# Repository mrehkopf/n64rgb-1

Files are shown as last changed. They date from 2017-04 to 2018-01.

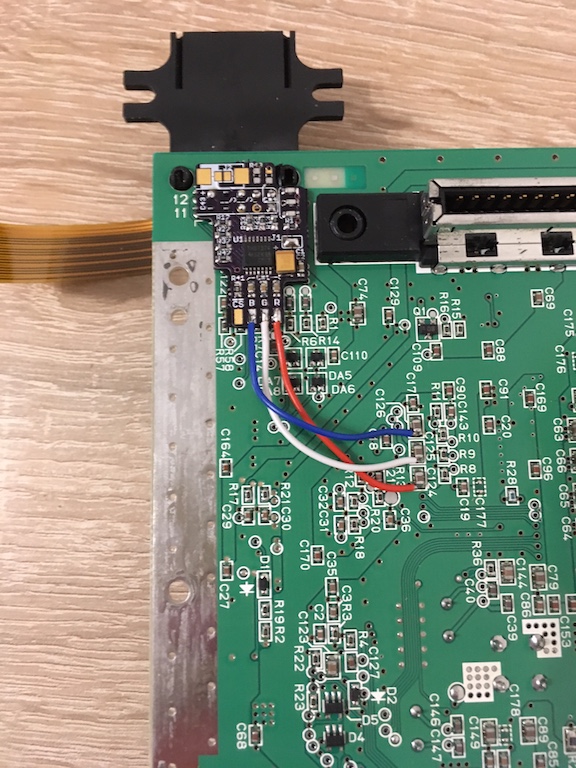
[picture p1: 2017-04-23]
pictures/n64_RGBamp_installed.jpg

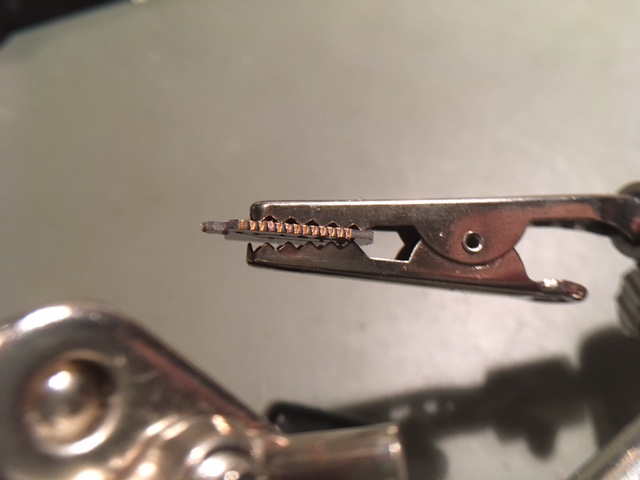
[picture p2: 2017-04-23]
pictures/mav_nus_breakout_side.jpg

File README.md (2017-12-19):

# N64 RGB 

A collection of RGB mods for the N64. This repository includes:

- a simple RGB amp
  * based on TI's video amplifier THS7374 / THS7373 (only for some NTSC-units)
  * folder: simpleRGBAmp
- a general RGB digital-to-analog converter based on viletims schematics
  * supported devices: MaxII (EPM240T100C5, EPM570T100C5) and MaxV (5M240ZT100C4, 5M570ZT100C4) CPLDs
  * PCB files (common for all supported devices) and firmware (separate programming files) are provided
  * folder: generalRGBmod
- an advanced RGB digital-to-analog converter with optional YPbPr conversion
  * supported FPGA: Cyclone IV (EP4CE6E22 and EP4CE10E22) and Cyclone 10 LP (10CL006YE144 and 10CL010YE144)
  * PCB files (common for all supported devices) and firmware (separate programming files) are provided
  * additional Filter board for the outputted video signal if you need that
  * folder: advancedRGBmod
- additional MAV-NUS Adapter:
  * pin breakout from 0.8mm pitch to 1.27mm pitch
  * PCB files provided
  * folder: misc/MAV-NUS-BreakOut
- Filter AddOn for N64RGBv2 and N64 Advanced:
  * used to filter the video signal comming out of the ADV7125 or to adjust signal levels such that one can use SNES PAL RGB cables
  * PCB files provided
  * folder: misc/FilterAddOn
- an alternative firmware for viletims commercial N64 RGB modding kit
  * include in firmware folder of generalRGBmod
  * project: n64rgb_viletim.qpf

## Acknowledgement

Of course, many thanks to viletim for his initial CPLD-based DAC project, for providing a valuable commercial modding board as well as for publishing the schematics and source codes for that project.
I also want to send many thanks to Ikari_01. He has written the code to detect 480i and PAL/NTSC output with the CPLD. He provides a source code for the XC9572XL, which can be accessed here: [URL to Ikari_01's GitHub repository](https://github.com/mrehkopf/n64rgb)
Last but not least, thank you to Bob for his website [RetroRGB](http://retrorgb.com) and especially in this context here for collecting and sharing all the [RGB information regarding the N64](http://retrorgb.com/n64.html).

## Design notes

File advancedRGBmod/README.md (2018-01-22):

# Advanced N64 RGB Digital-to-Analog Mod

This folder contains all you need for a complete DIY RGB mod.

Please don't ask me for selling a modding. I either sell some prototypes on some forums marketplaces (which is very unlikely) or I don't have any of the boards.
This is a complete DIY modding project. So everybody is on his own here.

**WARNING:** This is an advanced DIY project if you do everything on your own. You need decent soldering skills. The FPGA has 0.5mm fine pitch with 144pins and one exposed pad below the IC, which has to be soldered to the PCB. Next to it the video DAC has also 0.5mm pin pitch on the board there are some SMD1206 resistor and ferrit bead arrays.

## Features

- Supporting for different FPGAs [1] on a common PCB design:
  * (Cyclone IV EP4CE6E22)
  * Cyclone IV EP4CE10E22
  * (Cyclone 10 LP 10CL006YE144)
  * Cyclone 10 LP 10CL010YE144
- Video DAC ADV7125 (or ADV7123)
- Detection of 240p/288p vs. 480i/576i together with detection of NTSC vs. PAL mode
- Heuristic for de-blur function [2], De-Blur in 240p/288p (horizontal resolution decreased from 640 to 320 pixels)
- 15bit color mode
- IGR features:
  * reset the console with the controller
  * full control on de-blur and 15bit mode with the controller
- Advanced features:
  * output of RGsB or YPBPr on demand
  * linedoubling of 240p/288p video to 480p/576p [3]
  * selectable scanline strength: 0% (i.e. sl off), 25%, 50% and 100% [4]
  * optional bob de-interlace of 480i/576i to 480p/576p [3]
  * VGA output [5]

The following shortly describes the main features of the firmware and how to use / control them.

#### Notes
##### [1]
For now, all FPGAs seems to be fine. However, it might be the case that the 6k LEs FPGAs (EP4CE6E22 and 10CL006YE144) are to small for an OSD menu implementation due to the small amount of block RAM.

##### [2]
Heuristic for de-blur function highly depends on the image content. So it might be the case that de-blur is switched on and off rapidly even on small content changes. In any case you can override the heuristic by forcing de-blur on or off.  
If you observe something like that or where do you think that de-blur is not correctly guessed, please take a note (PAL / NTSC N64, game, ROM, situation), where I can check that and can try to further improve the heuristic algorithm. Send me your observation vie email or open an issue here on GitHub.

##### [3]
can be switched off

##### [4]
no scanlines are available in this mode

##### [5]
Not available if the filter adddon is used as HSYNC and VSYNC are shared outputs with F1 and F2 (filter selection)

### In-Game Routines (IGR)

Three functunalities are implemented: toggle de-blur feature / override heuristic for de-blur and toggle the 15bit mode (see above) as well as resetting the console.

The button combination are as follows:

- reset the console: Z + Start + R + A + B
- (de)activate de-blur / override heuristic for de-blur: (see description above)
- (de)activate 15bit mode: (see description above)

_Modifiying the IGR Button Combinations_:  
It's difficult to make everybody happy with it. Third party controllers, which differ from the original ones by design, make it even more difficult. So it is possible to generate your own firmware with **your own** preferred **button combinations** implemented. Please refere to the document **IGR.README.md** located in the top folder of this repository for further information.

_Final remark on IGR_:  
However, as the communication between N64 and the controller goes over a single wire, sniffing the input is not an easy task (and probably my solution is not the best one). This together with the lack of an exhaustive testing (many many games out there as well my limited time), I'm looking forward to any incomming issue report to furhter improve this feature :)

### De-Blur

De-blur of the picture information is only be done in 240p/288p. This is be done by simply blanking every second pixel. Normally, the blanked pixels are used to introduce blur by the N64 in 240p/288p mode. However, some games like Mario Tennis, 007 Goldeneye, and some others use these pixel for additional information rather than for bluring effects. In other words this means that these games uses full horizontal resolution even in 240p/288p output mode. Hence, the picture looks more blurry in this case if de-blur feature is activated.

- **By default heuristic is activated on every power cycle and on every reset!** However, as the heuristic guess might be not reliable, the guess can be overriden.
- Press Z + Start + R + C-le to deactivate de-blur (overrides the guess)
- Press Z + Start + R + C-ri to activate de-blur (overrides the guess)

_(Button combinations can be modified according to your needs - see note below @ **In-Game Routines (IGR)**)_

### Heuristic for De-Blur

As noted above, the N64 typically outputs a 320pixel wide picture in 240p/288p. As the pixel clock does not change compared to 480i/576i there outputted pixel wide is 640.
On the one hand, most games outputs a 320pixel wide picture in 240p/288p and use the remaining pixels to introduce a blur. This can be removed by simply blank these interpolated pixels.
On the other hand, a minor number of games outputs a 'full' 640pixel wide picture also in 240p/288p. In this case blanking out the suspected interpolated pixels causes a blurry picture.

The heuristic algorithm estimates whether a game uses the first or the second method. Depending on the result de-blur is active or not. However, as the estimation could be wrong, the user has the opportunity to override the estimation. (see section de-blur) At the moment it is not implemented that the heuristic can be switched on once overridden except with a reset or a new power cycle.

### 15bit Color Mode

The 15bit color mode reduces the color depth from 21bit (7bit for each color) downto 15bits (5bit for each color). Some very few games just use the five MSBs of the color information and the two LSBs for some kind of gamma dither. The 15bit color mode simply sets the two LSBs to '0'.

- By default the 15bit mode is *off*! The default is set on each power cycle but not on a reset.
- to deactivate 15bit mode press Z + Start + R + C-up.
- to (re)activate 15bit mode press Z + Start + R + C-dw.

_(Button combinations can be modified according to your needs - see note below @ **In-Game Routines (IGR)**)_

### Low Pass Filtering of the Video Output

The video DAC does not use any filtering. In general, this is also not needed. If you need DAC post-filtering though (receiver has a ADC build without any pre-filtering), you can install the filter addon (also provided in this repository).

The filter addon is based on a THS7368, where the video channels with selectable filter are used. As the filter is selected over the same pins as HSYNC and VSYNC, the addon is not compatible to VGA.

## Technical Information

A complete installation and setup guide to this modding kit is provided in the main folder of the repository. Here are some additional short notes.

### Checklist: How to build the project

- Use PCB files to order your own PCB or simply use the shared project(s) on OSHPark
- Source the components you need, e.g. from Mouser or Digikey
- Wait for everything to arrive
- Assemble your PCB
- Set all jumpers
- Flash the firmware to the serial flash device
  * You need a Altera USB Blaster
  * Use the JIC programming file if you want to program the serial flash over the FPGA or the SOF file if you have a AS programming adapter for the serial flash
  * The serial flash / board needs to be powered; so you may consider to install the PCB into your N64 first and then use the N64 for powering the board
  * If you want to build an adapter, you may take a look onto [my DIY adapter](https://oshpark.com/shared_projects/mEwjoesz) at [my profile on OSHPark](https://oshpark.com/profiles/borti4938)
- Install the modding board:
  * Installation description is part of the guide located in the top folder.
  * However an installation guide of a simalar product made by viletim is provided [here](http://etim.net.au/n64rgb/). The minor differences / extra pads are as follows:
    * decide on you own whether you want to use the analog part with 5V (connect 5V to the appropriate pad) or with 3.3V (short jumper _J6_). **Don't connect 5V and close J5.**
	* Pad *C*: currently unused. Leave it unconnected
    * Pad *Rst#*: connect this pad to the PIF-NUS pin 27
    * Pad *Ctrl*: connect this pin to the middle pin of the controller port you want to use for the IGR functions (controller port 1 is probably connected to PIF-NUS pin 16; check that before soldering a wire)
  * You have to be aware of the pinout of your video-encoder build into your N64. Pads on the DIY modding board are labeled.
  * If you have a MAV-NUS in your N64, you may want to use either the DIY break out board provided with this project and on OSHPark or buy a [flex cable from viletims shop](http://etim.net.au/shop/shop.php?crn=209&rn=555&action=show_detail)

### Jumpers

There are some jumpers spreaded over the PCB, namely _J1_, _J2_, _J3_, _J4_, _J5_ and _J6_. _J1 - J4_ have to parts, let's say _.1_ and _.2_, where _.1_ is marked with the _dot_ on the PCB.

#### J1 (Filter AddOn)
##### J1.1 
- opened: output HSYNC and VSYNC for possible VGA output
- closed: use filter addon

##### J1.2
- opened: use filter of the addon board
- closed: bypass filter (actually filter is set to 95MHz cut-off which is way above the video signal content)

#### J2 (RGB, RGsB, YPbPr)
##### J2.1
- opened: RGB output
- closed: RGsB output (sync on green)

##### J2.2
- opened: RGB / RGsB output
- closed: YPbPr output (beats J2.1)

#### J3 (Scanline)
##### J3.1/J3.2
- opened / opened: 0%
- opened / closed: 25%
- closed / opened: 50%
- closed / closed: 100%

#### J4 (Linemode)
##### J4.1
- opened: linedoubling of 240p/288p to 480p/576p
- closed: no-linedoubling (beats J4.2)

##### J4.2
- opened: no bob de-interlace of 480i/576i
- closed: bob de-interlace of 480i/576i to 480p/576p (J4.1 must be opened)

#### J5
_J5_ is the JTAG connector.

#### J6 (Power supply of analog outputs)
The analog part can be power with **either** 3.3V **or** 5V. If you want to power this part of the PCB with 3.3V, close _J6_ and leave pad _5V_ unconnected. If you want to power this part with 5V, leave _J6_ opened and connect pad _5V_ to +5V power rail of the N64. **NEVER connect 5V and close J6.**

#### Fallback Mode

A fallback mode can be activated by holding reset button down while powering on the N64. In the fallback mode **linedoubling and component conversion is turned off**. Sync on G/Y output is still on if one J2.1 or J2.2 is set as it does not affect RGBS.

### Source the PCB

Choose the PCB service which suits you. Here are some:

- OSHPark: [Link to the Main PCB](https://oshpark.com/shared_projects/kKAiNrtK) (If the PCB was updated and I forgot to update this link, look onto [my profile](https://oshpark.com/profiles/borti4938))
- PCBWay.com: [Link](http://www.pcbway.com/), [Affiliate Link](http://www.pcbway.com/setinvite.aspx?inviteid=10658)

### Part List for the PCB

This part list a recommendation how the PCB is designed. If you are able to find pin-compatible devices / parts, you can use them.

#### Components

Components are listed in advancedRGBmod/Main-PCB/BOM_n64advanced.xlsx

### Firmware
The firmware is located in the folder firmware/. To build the firmware on your own you need Quartus Prime Lite (any version which supports MaxII and MaxV devices).

If you only want to flash the firmware, the configuration files are pre-compiled and located in firmware/output_files. You need the POF appropriate for the CPLD you have choosen (look for the *\_extension*).

For flashing you need:

- Altera USB Blaster
- Standalone Quartus Prime Programmer and Tools

#### Firmware Revision Numbering

- 1.0: initially commited version

#### Road Map / New Ideas

- Gamma boost
- On Screen Display menu to get rid of the jumpers
- improve de-blur heuristic, e.g. by
  * de-blur estimation in the Y-domain
  * dynamic de-blur: decide on demand wether a pixel is used for a blurry effect or not (possible for the N64 to decide on demand? (e.g. background gaming with blur, front text without blur))
  * don't use quite dark / light pictures for the de-blur heuristic algorithm
- HDMI

Any other ideas: email me :)

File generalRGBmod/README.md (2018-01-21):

# General N64 RGB Digital-to-Analog Mod

This folder contains all you need for a complete DIY RGB mod.

Please don't ask me for selling a modding. I either sell some prototypes on some forums marketplaces (which is very unlikely) or I don't have any of the boards.
This is a complete DIY modding project. So everybody is on his own here.
If you are looking for a ready to install kit, just look on your own for a seller. Preferably you should invest your money into a [kit made by viletim](http://etim.net.au/shop/shop.php?crn=209). I also provide similar firmware files for his board in this GitHub repository, too.

**WARNING:** This is an advanced DIY project if you do everything on your own. You need decent soldering skills. The CPLD has 0.5mm fine pitch with 100pins. Next to it the video amp has a 0.65mm pin pitch on the board there are some SMD1206 resistor and ferrit bead arrays.

## Features

- Supporting for different CPLDs on a common PCB design:
  * MaxII EPM240T100C5
  * MaxII EPM570T100C5
  * MaxV 5M240ZT100C4 (a 5M240ZT100C5 does not met timing requirements [1])
  * MaxV 5M570ZT100C4 (a 5M570ZT100C5 does not met timing requirements [1])
- Video DAC:
  * V1: R2R ladder with video amplifier THS7374 or THS7373
  * V2: Video DAC ADV7125
- Detection of 240p/288p vs. 480i/576i together with detection of NTSC vs. PAL mode
- Heuristic for de-blur function [2], De-Blur in 240p/288p (horizontal resolution decreased from 640 to 320 pixels)
- 15bit color mode
- IGR features:
  * reset the console with the controller
  * full control on de-blur and 15bit mode with the controller
- Installation type: user decides whether he want to use IGR features or dedicated mechanical switches
- Slow Slew Rate
- for possibly future implementation: switch LPF of the video amplifier on and off (may only fit into CPLDs with 570LE)

The following shortly describes the main features of the firmware and how to use / control them.

#### Notes
##### [1]
Clocks are defined in the SDC-files place in the firmware folder.
The 5M240ZT100C5 and 5M570ZT100C5 does not met the timing requirements checked during the Timing Analysis. However, the default model is the so called *slow model*. If one uses the *fast model* for analysis, the timings are met without any problems.
So one could also give a try with the 5M240ZT100C5 or the 5M570ZT100C5, which should also works with 95% of all units produced in 'common' environments (e.g. living room temperature environment). Nevertheless, I won't garantee that.

Update: If you are looking for a 5M240ZT100C4 and 5M570ZT100C4, you propably realize that they are not in stock (e.g. at Mouser or Digikey). Then you can also use the 5M240ZT100I5 and 5M570ZT100I5, which are actually the same CPLDs.

##### [2]
Heuristic for de-blur function highly depends on the image content. So it might be the case that de-blur is switched on and off rapidly even on small content changes. In any case you can override the heuristic by forcing de-blur on or off.  
If you observe something like that or where do you think that de-blur is not correctly guessed, please take a note (PAL / NTSC N64, game, ROM, situation), where I can check that and can try to further improve the heuristic algorithm. Send me your observation vie email or open an issue here on GitHub.

### In-Game Routines (IGR) (default installation type)

Three functunalities are implemented: toggle de-blur feature / override heuristic for de-blur and toggle the 15bit mode (see above) as well as resetting the console.

The button combination are as follows:

- reset the console: Z + Start + R + A + B
- (de)activate de-blur / override heuristic for de-blur: (see description below)
- (de)activate 15bit mode: (see description below)

_Modifiying the IGR Button Combinations_:  
It's difficult to make everybody happy with it. Third party controllers, which differ from the original ones by design, make it even more difficult. So it is possible to generate your own firmware with **your own** preferred **button combinations** implemented. Please refere to the document **IGR.README.md** located in the top folder of this repository for further information.

_Final remark on IGR_:  
However, as the communication between N64 and the controller goes over a single wire, sniffing the input is not an easy task (and probably my solution is not the best one). This together with the lack of an exhaustive testing (many many games out there as well my limited time), I'm looking forward to any incomming issue report to furhter improve this feature :)

### De-Blur

De-blur of the picture information is only be done in 240p/288p. This is be done by simply blanking every second pixel. Normally, the blanked pixels are used to introduce blur by the N64 in 240p/288p mode. However, some games like Mario Tennis, 007 Goldeneye, and some others use these pixel for additional information rather than for bluring effects. In other words this means that these games uses full horizontal resolution even in 240p/288p output mode. Hence, the picture looks more blurry in this case if de-blur feature is activated.

- **By default heuristic is activated on every power cycle and on every reset!** However, as the heuristic guess might be not reliable, the guess can be override. Also, the heuristic algorithm can be switched off permanently by setting pin 2 of the CPLD to GND (short pin 1 and 2)
- Press Z + Start + R + C-le to deactivate de-blur (overrides the guess)
- Press Z + Start + R + C-ri to activate de-blur (overrides the guess)
- If heuristic estimation is switched off, the de-blur setting has a default value. This default is set on each power cycle but not on a reset. Default is de-blur *on*! If you want to have it *off* by default, short pin 91 and 90 at the CPLD!

_(Button combinations can be modified according to your needs - see note below @ **In-Game Routines (IGR)**)_

### Heuristic for De-Blur

As noted above, the N64 typically outputs a 320pixel wide picture in 240p/288p. As the pixel clock does not change compared to 480i/576i there outputted pixel wide is 640.
On the one hand, most games outputs a 320pixel wide picture in 240p/288p and use the remaining pixels to introduce a blur. This can be removed by simply blank these interpolated pixels.
On the other hand, a minor number of games outputs a 'full' 640pixel wide picture also in 240p/288p. In this case blanking out the suspected interpolated pixels causes a blurry picture.

The heuristic algorithm estimates whether a game uses the first or the second method. Depending on the result de-blur is active or not. However, as the estimation could be wrong, the user has the opportunity to override the estimation. (see section de-blur) At the moment it is not implemented that the heuristic can be switched on once overridden except with a reset or a new power cycle.

### 15bit Color Mode

The 15bit color mode reduces the color depth from 21bit (7bit for each color) downto 15bits (5bit for each color). Some very few games just use the five MSBs of the color information and the two LSBs for some kind of gamma dither. The 15bit color mode simply sets the two LSBs to '0'.

- By default the 15bit mode is *off*! The default is set on each power cycle but not on a reset. If you want to have it *on* by default, short pin 36 and 37 at the CPLD!
- to deactivate 15bit mode press Z + Start + R + C-up.
- to (re)activate 15bit mode press Z + Start + R + C-dw.

_(Button combinations can be modified according to your needs - see note below @ **In-Game Routines (IGR)**)_

### Jumpers - Altering Defaults and Installation Type

There are three jumpers jumpers on the modding board - one double solder jumper and one 'hidden' jumper - to set up deblur (IGR installation) and 15bit mode.  
The hidden jumper are nothing else then neighbouring pins. This pin is marked with an arrow. If you short a pair of pins you can change the default of the above noted features.  

- J11.1 -> deactivates de-blur by default (only applied if de-blur heuristic is off by default) **[1]**
- J11.2 -> deactivate the de-blur heuristic. **[1]**
- pin 36 and 37 (hidden jumper on v1) / J12.1 -> activates the 15bit color mode by default
- J12 (v1) / J12.2 (v2) -> Altering installation type **[2]** 

**Notes**:  

**[1]**  
Board Version September 2017 and later have a dedicated double solder jumper for de-blur heuristic and de-blur default. The jumper is labeled with _J11_ (left pad is _marked with a dot_). The middle pad is GND, the right pad is de-blur heuristic on (open) or off (short to middle) and the left pad is de-blur on (open) or off (short to middle), respectively.  
On older revisions _J11.1_ (pin 90 and 91) and _J11.2_ (pin 1 and 2) are hidden jumpers.  

**[2]**  
To use switches for de-blur (similar to viletims board) on can set the jumper _J12_ on the board. This deactivates the IGR functionalities and the user can use the in-/ouputs for controller and reset for switches.  
These switches are used as on viletims commercial board: **A**uto and **M**anual. The corresponding inputs are _Ctrl_ and _Rst#_, respectively. On newer boards (September 2017 and later) these pads are relabeled with _Ctrl/ A_ and _Rst#/ M_.

- If pad _Ctrl/ A_ is shorted to GND via a switch, the de-blur heuristic is used to switch de-blur on and off.
- If pad _Rst#/ M_ is shorted to GND via a switch, the de-blur is forced to be on (beats heuristic).

_J12_ is connected to pin 66 of the CPLD. Next to it is pin 65 which is connected to GND. If you have an older version of the board (August 2017 and earlier) running with the current firmware (September 2017 and later) you can short pin 65 and 66 to activate the alternative installation type.

### Slow Slew Rate

This feature reduces the rising and falling time of the outputs. This reduces artefacts due to fast rising/falling edges at the outputs and the resulting over-/undershoots. The drawback is that the edges are not as sharp as with fast slew rates (at least in theory), which is not noticeable.

### Low Pass Filter Bypass Mode of the THS7374 (v1 only)

The bypass mode of the internal filters is controlled by the CPLD. At the moment the CPLD forwards just the setting one can input to the CPLD over pad *Fil*.

- To leave the internal filters enabled you can left the pad open
- To bypass the filter set this pad to GND.

## Technical Information

A complete installation and setup guide to this modding kit is provided in the main folder of the repository. Here are some additional short notes.

### Checklist: How to build the project

- Use PCB files to order your own PCB or simply use the shared project on OSHPark
- Source the components you need, e.g. from Mouser
- Wait for everything to arrive
- Assemble your PCB (**N64RGBv1**):
  * If you use a MaxII CPLD, you have to assemble FB2 and must not use U3, C31 and C32.
  * If you use a MaxV CPLD, you need U3 (a 1.8V voltage regulator), C31 and C32. Don't touch FB2 in this case!
- Assemble your PCB (**N64RGBv2**):
  * If you use a MaxII CPLD, you have to assemble FB3 and must not use U4, C41 and C42.
  * If you use a MaxV CPLD, you need U4 (a 1.8V voltage regulator), C41 and C42. Don't touch FB3 in this case!
- If you use a 570LEs CPLD, close J1
- Flash the firmware to the CPLD:
  * You need a Altera USB Blaster
  * The board needs to be powered; so you may consider to install the PCB into your N64 first and then use the N64 for powering the board
  * If you want to build an adapter, you may take a look onto [my DIY adapter](https://oshpark.com/shared_projects/mEwjoesz) at [my profile on OSHPark](https://oshpark.com/profiles/borti4938)
- Install the modding board:
  * Installation description is part of the guide located in the top folder.
  * However an installation guide of a similar product made by viletim is provided [here](http://etim.net.au/n64rgb/). The minor differences / extra pads are as follows:
    * N64RGBv2: J2 shorts 3.3V from CPLD with power rail of the ADV7125 (DAC). **If you use 5V at the analog power rail of the ADV7125, you must not close J2!**
    * Pad *Fil*: controls the low pass filter mode (v1 only, see above)
    * Pad *Rst#*: connect this pad to the PIF-NUS pin 27
    * Pad *Ctrl*: connect this pin to the middle pin of the controller port you want to use for the IGR functions (controller port 1 is probably connected to PIF-NUS pin 16; check that before soldering a wire)
  * You have to be aware of the pinout of your video-encoder build into your N64. Pads on the DIY modding board are labeled.
  * If you have a MAV-NUS in your N64, you may want to use either the DIY break out board provided with this project and on OSHPark or buy a [flex cable from viletims shop](http://etim.net.au/shop/shop.php?crn=209&rn=555&action=show_detail)

### Source the PCB
Choose the PCB service which suits you. Here are some:

- OSHPark: [Link to the Main PCB v1](https://oshpark.com/shared_projects/zPCxky4e) (If the PCB was updated and I forgot to update this link, look onto [my profile](https://oshpark.com/profiles/borti4938))
- OSHPark: [Link to the Main PCB v2](https://oshpark.com/shared_projects/KUxvVUbc) (If the PCB was updated and I forgot to update this link, look onto [my profile](https://oshpark.com/profiles/borti4938))
- PCBWay.com: [Link](http://www.pcbway.com/), [Affiliate Link](http://www.pcbway.com/setinvite.aspx?inviteid=10658)

### BOM / Part List for the PCB
This part list a recommendation how the PCB is designed. If you are able to find pin-compatible devices / parts, you can use them.

The manufacturer's part numbers (MPNs) are just to help you to source appropriate components.

### Firmware
The firmware is located in the folder firmware/. To build the firmware on your own you need Quartus Prime Lite (any version which supports MaxII and MaxV devices).

If you only want to flash the firmware, the configuration files are pre-compiled and located in firmware/output_files. You need the POF appropriate for the CPLD you have choosen (look for the *\_extension*).

For flashing you need:

- Altera USB Blaster
- Standalone Quartus Prime Programmer and Tools

#### Firmware Revision Numbering

Revision numbering goes along with the revision numbering I use for the alternative firmware for viletims N64RGB modding kit.

#### Road Map / New Ideas

- don't use quite dark / light pictures for the de-blur heuristic algorithm (possibly only for the CPLDs with 570LEs)
- Simple onscreen feedback for user controled changes (only for the CPLDs with 570LEs (for the 240LEs CPLDs instead of the heuristic?))
- dynamic de-blur: decide on demand wether a pixel is used for a blurry effect or not (possible for the N64 to decide on demand? (e.g. background gaming with blur, front text without blur))
- HDMI?

Any other ideas: email me :)

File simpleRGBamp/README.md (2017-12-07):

# Simple RGB Mod

## General Information

Technical information about this mod...

- Which N64 is suitable for it
- How to install this mod

... can be found on RetroRGB.com ([Compatibility](http://www.retrorgb.com/n64rgbcompatible.html) and [Installation](http://www.retrorgb.com/n64rgbmod.html))

Many thanks to Bob at this place for sharing that.

The rest

- Which parts are needed
- Some additional tips and hints

can be found in this document.

## Components

**be aware of the additional comments below this table**

| Label | Device / Part | Package | Quantity | Mouser Ordering Key | Comment |
|:---:|---|---|:---:|:---|---|
| | | | | | |
| **U1** | THS7374 | TSSOP-14 | 1 | 595-THS7374IPWR | |
| | THS7373 | TSSOP-14 | 1 | 595-THS7373IPWR | **Alternative** for the THS7374 [1] |
| **C1** | 22uF / 6.3V (tantal) | SMD case B (typical: 3.50mm x 2.80mm) | 1 | 74-593D226X96R3B2TE3 | |
| **C2** | 0.1uF / 50V (10%) | SMD 0603 | 1 | 80-C0603C104K9R | |  
| | | | | | |
| **R1, R41** | 4.7kohm (1%) | SMD 0603 | 2 | 71-CRCW06034K70FKEAH | |
| **R42** | 475ohm (1%) | SMD 0603 | 1 | 71-CRCW0603-475-E3 | csync compatible with 75ohm termination [2,3] |
| | 10.7kohm | SMD 0603 | 1 | 71-CRCW060310K7FKEB | TTL compatible csync [2,3] |
| **C11,C21,C31** | 0.082uF / 25V (10%) | SMD 0603 | 3 | 81-GRM188R71E823KA1D | |
| **R12,R22,R32** | 5.1Mohm (1%) | SMD 0603 | 3 | 71-CRCW06035M10FKEA | |
| | | | | | |
| **R13,R23,R33** | 75ohm (1%) | SMD 0603 | 3 | 71-RCS060375R0FKEA | NTSC-SNES RGB cable setup or direct wiring on RGB wires [4] |
| | 39ohm (1%) | SMD 0603 | 3 | 71-CRCW060339R0FKEAH | PAL-SNES cable setup on RGB wires [4] |
| **C14,C24,C34** | 47pF / 25V (5%) | SMD 0603 | 3 | 77-VJ0603A470JXXPBC | | 
| | | | | | |
| **C43** | tantal 220uF / 6.3V (tantal) | SMD case D (typical: 7.30mm x 4.30mm) | 1 | 74-593D227X96R3D2TE3 | csync compatible with 75ohm termination[2,3] |
| | 330uF / 6.3V (tantal) | SMD case D (typical: 7.30mm x 4.30mm) | 1 | 74-TR3D337K6R3E0100 | /CSYNC compatible with 75ohm termination, **Alternative** to 220uF tantal [2,3] |
| | *free* | | | | TTL compatible /CSYNC, close **J2** [2,3] |
| **R43** | 75ohm (1%) | SMD 0603 | 1 | 71-RCS060375R0FKEA | csync compatible with 75ohm termination [2,3], NTSC-SNES RGB cable setup [4] |
|| 39ohm (1%) | SMD 0603 | 1 | 71-CRCW060339R0FKEAH | /CSYNC compatible with 75ohm termination [2,3], PAL-SNES cable setup on RGB wires [4] |
| | 0ohm | SMD 0603 | 1 | *use a piece of silver wire* |  TTL compatible /CSYNC [2,3] |
| **C44** | 47pF / 25V (5%) | SMD 0603 | 1 | 77-VJ0603A470JXXPBC | [3] | 

### Additional Comments:

##### [1]  
Both ICs are supported. The THS7373 has one SD-video low pass filter (used for /CSYNC) and three HD-video filters (used for R, G and B). The THS7374 has four SD-video filters.  
At the THS7373 the HD-video LPFs can be bypassed and at the THS7374 all four SD-video filters can be bypassed (using J1).

##### [2]
According to your needs, you can design the board such that it outputs 75ohm compatible /CSYNC or TTL /CSYNC. Be aware of the components marked with this note (**R42**, **R43**, **C43/J2** and **C44**).  
If you have a RGB cable build to work with /CSYNC and use this with another (probably) _unmodified_ console, which you use on a 75ohm terminated source, you may have a resistor (and a cap) build in the sync line. Then you must build this modding board here with TTL compatible sync, too.

##### [3]
If you are going to use the stock /CSYNC circuit of the N64 - which I recommend if you have a NUS-CPU-01/02/03 board - you don't need the components **R43**, **C43** and **C44**. Just leave the footprints disassembled.  
**R42** should remain on the modding board (either size; could also be a short) as it holds channel one of the video amp close to GND.

##### [4]
As the N64 does not output RGB by stock, there is no official RGB cable available. A most common method is to refere to the [SNES cable schematics](http://members.optusnet.com.au/eviltim/gamescart/gamescart.htm#snes).

- If you use a NTSC cable cable, **R13**, **R23** and **R33** (and **R43**) has to be 75ohm resistors.
- If you use a PAL cable setup, **R13**, **R23** and **R33** (and **R43**) has to be 39ohm resistors.

## Source the PCB
Choose the PCB service which suits you. Here are some:

- OSHPark: [Link to the PCB](https://oshpark.com/shared_projects/B3Unx78x) (If the PCB was updated and I forgot to update this link, look onto [my profile](https://oshpark.com/profiles/borti4938))
- PCBWay.com: [Link](http://www.pcbway.com/), [Affiliate Link](http://www.pcbway.com/setinvite.aspx?inviteid=10658)

## Installation

A very good installation guide can be found on [RetroRGB.com](http://www.retrorgb.com/n64rgbmod.html).

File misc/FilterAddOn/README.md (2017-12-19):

# Filter Add On for N64 RGBv2 and N64 Advanced

This filter board is meant to use with the N64RGBv2 and N64 Advanced. It can be used to filter the video signal comming out of the ADV7125 or to adjust signal levels such that one can use SNES PAL RGB cables.

The PCB can be sourced on every manufacturer you like. Use a **PCB substrate thickness** as small as possible; e.g., 0.8mm at OSHPark.

- OSHPark: [Link to the Filter AddOn PCB](https://oshpark.com/shared_projects/BTvi9bfX) (If the PCB was updated and I forgot to update this link, look onto [my profile](https://oshpark.com/profiles/borti4938)) -- get this PCB with 0.8mm (or less) substrate thickness
- PCBWay.com: [Link](http://www.pcbway.com/), [Affiliate Link](http://www.pcbway.com/setinvite.aspx?inviteid=10658)

## Filter Settings

The board utilizes the THS7368 with selectable filters. The setup is done via inputs _F1_ and _F2_.

### N64RGBv2

- Leave _F1_ and _F2_ open or short the to GND to use the filter.
- Connect _F1_ and _F2_ to Vcc, i.e. +5V, to effectively bypass the filter.

### N64Advanced

Commect _F1_ and _F2_ to the modding board and use _J1_ to set it up.

## Jumper J1

With the jumper _J1_ you are able to forward composite sync input to either MultiAV pin 3 or pin 7.  
The composite sync input _/CS_ **is not** passed through the THS7386. You can either connect TTL level sync or 75ohm attenuated sync, here.

## BOM

- U1: THS7368
- C1: 0.1uF SMD0603 ceramic cap
- C2: 22uF SMD1206 ceramic cap
- RN1: 4x 75ohm resistor array SMD1206
- RN2:
  * NTSC cable:: 4x 75ohm resistor array SMD1206
  * PAL cable:: 4x 39ohm resistor array SMD1206

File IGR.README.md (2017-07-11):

# IGR Features of the N64 RGB Firmware
## Modifying the Button Combinations

### Preface
With the In-Game Routines feature of the N64 RGB firmware (generalRGBmod, viletim) you are able to trigger several events using the controller, e.g. perform a soft-reset.  
However, everybody prefer some different combinations according to some subjective criterias. This documents describes how to build your own firmware or how to request a firmware build.

### Required Software

- _build your own_: [Quartus Prime Lite edition](http://dl.altera.com/17.0/?edition=lite) with MaxII / MaxV support files. Please see release notes for additional hard- and software requirements.
- _request a fw-build_: simple text editor

### Adding your button combination

#### Before you start
All firmware builds I made will be located in the GitHub repository _firmware_ subfolder _output\_files/igr\_fw\_builds/_. Please look through the subfolders there if there is a build with button combinations which are suitable for you. The to the build corresponding _igr\_params.vh_ is located in the firmware build subfolder along with the programming file(s).

#### First steps
The firmware source is located in either _generalRGBmod/firmware/_ or _viletim/_. It depends on your hardware which one you use - most probable you have viletims modding kit installed; then you go into _viletim/_ of course.

If you use Quartus Prime to build your own firmware open the _Quartus Project File_ (\*.qpf) with Quartus Prime. Once the project has been loaded, change the revision accodingly.

- generalRGBmod: revision named by the CPLD you use
- viletim: use revision _n64rgb_with_igr

#### Modifying the button combination
You find in the Verilog source files a file named **igr\_params.vh**. open this file with either Quartus Prime or with a text editor of your choice.

**Please do not edit** the first few lines. Your editing starts at line 50. Each line starting with the keyword _parameter_ is now in your point of interest. After the keyword you have a name and an assigned value. Do not edit the name, just the assignment.

You have the following values for your assignment available: **\`A, \`B, \`Z, \`St, \`Du, \`Dd, \`Dl, \`Dr, \`L, \`R, \`Cu, \`Cd, \`Cl and \`Cr**. It's important that you **use the backtick** infront of each button code. You can **connect multiple buttons** with a simple **+** sign! A line closes with a semicolon. You can assign the following codes:

- _igr\_reset_: button combination to trigger a reset
- _igr\_deblur\_off_: button combination to switch deblur off
- _igr\_deblur\_on_: button combination to switch deblur on
- _igr\_15bitmode\_off_: button combination to switch 15bit color mode off
- _igr\_15bitmode\_on_: button combination to switch 15bit color mode on

Once you have edited your button combinations, you have the option to either build the firmware on your own or to request a firmware build.

#### Building the firmware
If you are on the DIY PCB project, first open the _n64rgb.v_ and (un-)comment the lines 31 to 34 appropriately for your CPLD.
 
In Quartus Prime then go to _Processing_ on the top bar and _Start Compilation_. Or simply double click on _Assembler (Generate programming file)_ in the _Tasks_-subwindow. Your programming file (\*.pof) will be located in the project-subfolder _output\_files/_.

#### Request the firmware
As I can understand that not everybody wants to install a 15GB program for just building the firmware, I offer you to generate your firmware. Just send me your edited **igr\_params.vh** to [borti4938@gmx.de](mailto:borti4938@gmx.de).

A few days later I will upload it to GitHub. I try to inform you via email directly, but please be not sad if I forget it. Just look frequently on GitHub.

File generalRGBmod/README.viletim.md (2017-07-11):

# N64 RGB Firmware
An alternative firmware for viletims commercial N64 RGB mod

## Description of the Firmware Version

I uploaded two different firmware versions. These are the common features:
- Detection of 240p/288p
- Detection of PAL and NTSC mode (no output of that information at the moment as it is only internally used)
- Heuristic for de-blur function
- De-Blur in 240p/288p (horizontal resolution decreased from 640 to 320 pixels)
- 15bit color mode
- Slow Slew Rate

The two versions of the firmware now differs in the way how de-blur and 15bit color mode is accessed:
- With mechanical switches
- with in-game routine (IGR)

The following shortly describes the main features of the firmware and how to use / control them.

### De-Blur

De-blur of the picture information is only be done in 240p/288p. This is be done by simply blanking every second pixel. Normally, the blanked pixels are used to introduce blur by the N64 in 240p/288p mode. However, some games like Mario Tennis use these pixel for additional information rather than for bluring effects. In other words this means that these games uses full horizontal resolution even in 240p/288p output mode. Hence, the picture looks more blurry in this case if de-blur feature is activated.

By default this feature is on.
- 'firmware without IGR':
  * By setting pin 100 of the MaxII CPLD (pad *A*) to GND, the heuristic is activated. The firmware tries to estimate whether de-blur can be applied in 240p/288p or not.
  * By setting pin 99 of the MaxII CPLD (pad *M*) to GND, de-blur is applied in 240p/288p in any case. This overrides the heuristic.
  * By default (pin 100 and 99 / pad *A* and *M* left open) the de-blur feature is switched *off*!
- 'firmware with IGR':
  * **By default heuristic is activated on every power cycle and on every reset!** However, as the heuristic guess might be not reliable, the guess can be override. Also, the heuristic algorithm can be switched off permanently by setting pin 61 of the MaxII CPLD to GND (short pin 61 and 60)
  * Press D-Pad le + L + R + C-le to deactivate de-blur (overrides the guess)
  * Press D-Pad ri + L + R + C-ri to activate de-blur (overrides the guess)
  * If heuristic estimation is switched off, the de-blur setting has a default value. This default is set on each power cycle. Default is de-blur *on*! If you want to have it *off* by default, short pin 91 and 90 at the MaxII CPLD!

_(Button combinations can be modified according to your needs - see note below @ **In-Game Routines (IGR)**)_

### Heuristic for De-Blur

As noted above, the N64 typically outputs a 320pixel wide picture in 240p/288p. As the pixel clock does not change compared to 480i/576i there outputted pixel wide is 640.
On the one hand, most games outputs a 320pixel wide picture in 240p/288p and use the remaining pixels to introduce a blur. This can be removed by simply blank these interpolated pixels.
On the other hand, a minor number of games outputs a 'full' 640pixel wide picture also in 240p/288p. In this case blanking out the suspected interpolated pixels causes a blurry picture.

The heuristic algorithm estimates whether a game uses the first or the second method. Depending on the result de-blur is active or not. However, as the estimation could be wrong, the user has the opportunity to override the estimation. (see section de-blur)

### 15bit Color Mode

The 15bit color mode reduces the color depth from 21bit (7bit for each color) downto 15bits (5bit for each color). Some very few games just use the five MSBs of the color information and the two LSBs for some kind of gamma dither. The 15bit color mode simply sets the two LSBs to '0'.

By default this feature is off.
- 'firmware without IGR': To activate it set pin 36 of the CPLD to GND (short pin 36 and 37). This feature is *off* by default.
- 'firmware with IGR':
  * to deactivate 15bit mode press D-Pad up + L + R + C-up.
  * to (re)activate 15bit mode press D-Pad dw + L + R + C-dw.
  * the default is set on each power cycle. Default for 15bit color mode is *off*! If you want to have it *on* by default, short pin 36 and 37 at the MaxII CPLD!

_(Button combinations can be modified according to your needs - see note below @ **In-Game Routines (IGR)**)_

### Slow Slew Rate

This feature reduces the rising and falling time of the outputs. This reduces artefacts due to fast rising/falling edges at the outputs and the resulting over-/undershoots. The drawback is that the edges are not as sharp as with fast slew rates (at least in theory), which is not noticeable.

### In-Game Routines (IGR)

To use this firmware (and therefore the IGRs) pin 100 of the CPLD (pad *A*) has to be connected to the communication wire of controller 1. On the controller port this is the middle pin, which is connected to pin 16 of the PIF-NUS (PIFP-NUS) on most consoles. Check this before soldering a wire to the PIF-NUS.

Three functunalities are implemented: toggle de-blur feature / override heuristic for de-blur and toggle the 15bit mode (see above) as well as resetting the console. To use the reset functionality please connect pin 1 OR pin 99 of the CPLD (pad *M*) to the PIF-NUS pin 27. This is optional and can be left out if not needed.

The button combination are as follows:

- reset the console: A + B + D-Pad dw + D-Pad ri + L + R
- (de)activate de-blur / override heuristic for de-blur: (see description above)
- (de)activate 15bit mode: (see description above)

_Modifiying the IGR Button Combinations_:  
It's difficult to make everybody happy with it. Third party controllers, which differ from the original ones by design, make it even more difficult. So it is possible to generate your own firmware with **your own** preferred **button combinations** implemented. Please refere to the document **IGR.README.md** located in the top folder of this repository for further information.

_Final remark on IGR_:  
However, as the communication between N64 and the controller goes over a single wire, sniffing the input is not an easy task (and probably my solution is not the best one). This together with the lack of an exhaustive testing (many many games out there as well my limited time), I'm looking forward to any incomming issue report to furhter improve this feature :)

## Technical Information

The firmware is suiteable for all version of the N64RGB modding kits designed by viletim.
- On V1.0 and V1.1 boards, CPLD pin 100, pin 99 and pin 1 are not connected to anything. You have to connect loose wires here.
- On V1.2 boards (and later versions?), CPLD pin 100 is connected to pad *A* and pin 99 to pad *M*.

Lastly, the information how to update can be grabbed incl. some more technical information here: [URL to viletims official website](http://etim.net.au/n64rgb/tech/). The use of the presented firmware is up on everybodies own risk. However, a fallback to the initial firmware is provided on viletims webpage.

### Firmware Revision Numbering

Before 19.04.2017:
- The revisions were number with 1, 2, 3,...
- All revisions with a number below 4 has no IGRs implemented; revisions with 5 and later has the IGRs implemented.

After 19.04.2017:
- Revision numbering has changed:
  * 1.x - no IGR implemented. Use mechanical (or external electrical) switches
  * 2.x - IGR functions implemented.

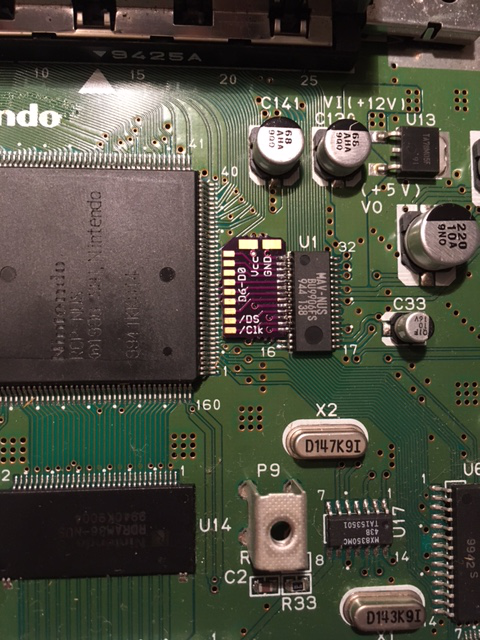
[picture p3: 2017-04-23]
pictures/mav_nus_breakout.jpg

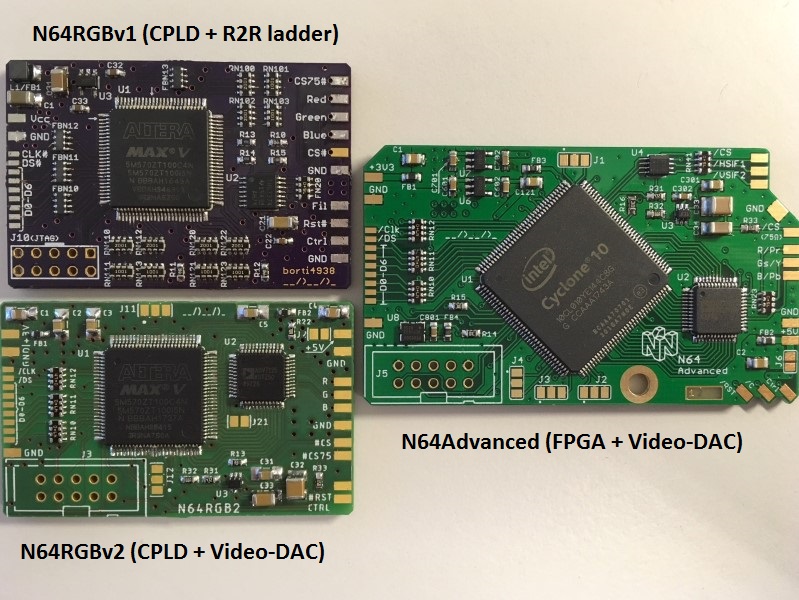
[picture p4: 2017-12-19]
pictures/N64RGB-Family.JPG

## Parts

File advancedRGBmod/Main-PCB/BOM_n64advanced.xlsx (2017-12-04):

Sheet: BOM_N64_Advanced
Designator | MPN | QTY | DESCRIPTION | VALUE | PACKAGE | NOTES | Digikey | Mouser
U1 | 10CL010YE144C8G | 1 | Cyclone 10 LP FPGA, 10k LE |  | EQFP144 | can be replaced with other FPGAs on demand (see Schematic file) | https://www.digikey.de/product-detail/en/altera/10CL010YE144I7G/544-3376-ND/7347620 (http://www.digikey.de/scripts/DkSearch/dksus.dll?Detail&itemSeq=234870402) | http://www.mouser.de/ProductDetail/Intel/10CL010YE144C8G/
U2 | ADV7125KSTZ140 | 1 | Video DAC 8bit, 3Ch. |  | 48-LQFP | can be replaced with ADV7123KSTZ140 on demand | https://www.digikey.de/product-detail/de/analog-devices-inc/ADV7125KSTZ140/ADV7125KSTZ140-ND/654207 | www.mouser.de/ProductDetail/Analog-Devices/ADV7125KSTZ140/
U3 | TSH122ICT | 1 | Video Verstärker 1Ch |  | SC-70-6 |  | https://www.digikey.de/product-detail/de/stmicroelectronics/TSH122ICT/497-8332-1-ND/ | http://www.mouser.de/ProductDetail/STMicroelectronics/TSH122ICT/
U4 | SN74LVC3G17DCTR | 1 | Non-Inv Buffer 3Ch., Schmitt Trigger |  | 8-LSSOP, 8-MSOP | TI: DCT Package Footprint | https://www.digikey.de/product-detail/de/texas-instruments/SN74LVC3G17DCTR/296-16915-1-ND/644203 | http://www.mouser.de/ProductDetail/Texas-Instruments/SN74LVC3G17DCTR/
U5 | S25FL116K0XMFB013 | 1 | IC FLASH 16MBIT 108MHZ 8SOIC |  | 8-SOIC | 208mil Body; Digikey ist Alternative im 150mil Body. Footprint ünterstützt beides | https://www.digikey.de/product-detail/de/cypress-semiconductor-corp/S25FL116K0XMFA043/428-4061-1-ND/ | http://www.mouser.de/ProductDetail/Cypress/S25FL116K0XMFB013/
U6 | TLV70012DDCR | 1 | LDO 1.2V |  | SOT-23-5 |  | https://www.digikey.de/product-detail/de/texas-instruments/TLV70012DDCR/296-39275-1-ND/ | http://www.mouser.de/ProductDetail/Texas-Instruments/TLV70012DDCR/
U7 | TLV70025DDCR | 1 | LDO 2.5V |  | SOT-23-5 |  | https://www.digikey.de/product-detail/de/texas-instruments/TLV70025DDCR/296-32411-1-ND/ | http://www.mouser.de/ProductDetail/Texas-Instruments/TLV70025DDCR/
U8 | ASE-50.000MHZ-LC-T | 1 | OSC 50MHz | 50MHz | 4-SMD | L x B: 0,126" x 0,098" (3,20 mm x 2,50 mm) | https://www.digikey.de/product-detail/de/abracon-llc/ASE-50.000MHZ-LC-T/535-9577-1-ND/ | http://www.mouser.de/ProductDetail/ABRACON/ASE-50000MHZ-L-C-T/
C1,C2 | GRM219R60J476ME44D | 2 | Ceramic capacitor, X5R | 47uF / 6.3V | SMD0805 |  | https://www.digikey.de/product-detail/de/murata-electronics-north-america/GRM219R60J476ME44D/490-13249-1-ND/ | http://www.mouser.de/ProductDetail/Murata/GRM219R60J476ME44D/
C21,C22,C102,C103,C104,C105,C106,C107,C108,C109,C110,C111,C112,C113,C122,C123,C124,C125,C126,C127,C128,C129,C131,C132,C141,C142,C201,C203,C205,C401,C501 | GRM188R71H104KA93J | 31 | Ceramic capacitor, X7R | 0.1uF / 50V | SMD0603 |  | https://www.digikey.de/product-detail/de/murata-electronics-north-america/GRM188R71H104KA93J/490-9735-1-ND/ | http://www.mouser.de/ProductDetail/Murata/GRM188R71H104KA93J/
C101,C121,C301 | GRM21BR60J106ME19L | 3 | Ceramic capacitor, X5R | 10uF / 6.3V | SMD0805 |  | https://www.digikey.de/product-detail/de/murata-electronics-north-america/GRM21BR60J106ME19L/490-1718-1-ND/ | http://www.mouser.de/ProductDetail/Murata/GRM21BR60J106ME19L/
C202,C204,C206,C302,C801 | GRM188R70J103KA01D | 5 | Ceramic capacitor, X7R | 0.01uF / 50V | SMD0603 |  | https://www.digikey.de/product-detail/de/murata-electronics-north-america/GRM188R70J103KA01D/490-9729-1-ND/ | http://www.mouser.de/ProductDetail/Murata/GRM188R70J103KA01D/
C33 | GRM32DR60J336ME19L | 1 | Ceramic capacitor, X5R | 33uF / 6.3V | SMD1210 |  | https://www.digikey.de/product-detail/de/murata-electronics-north-america/GRM32DR60J336ME19L/490-3389-1-ND/ | http://www.mouser.de/ProductDetail/Murata-Electronics/GRM32DR60J336ME19L/
C34 | GRM31CR60J226KE19L | 1 | Ceramic capacitor, X5R | 22uF / 6.3V | SMD1206 |  | https://www.digikey.de/product-detail/de/murata-electronics-north-america/GRM31CR60J226KE19L/ | http://www.mouser.de/ProductDetail/Murata/GRM31CR60J226KE19L/
C601,C602,C701,C702 | GRM18R60J105KA01J | 4 | Ceramic capacitor, X5R | 1uF / 6.3V | SMD0603 |  | https://www.digikey.de/product-detail/de/murata-electronics-north-america/GRM188R60J105KA01J/490-6404-1-ND/3845601 | https://www.mouser.de/ProductDetail/Murata/GRM188R60J105KA01J/
FB1,FB2,FB3,FB4 | MPZ1608S221A | 4 | Ferrit bead, power line |  | SMD0603 |  | https://www.digikey.de/product-detail/de/tdk-corporation/MPZ1608S221ATA00/445-1565-1-ND/ | http://www.mouser.de/ProductDetail/TDK/MPZ1608S221A/
J5 | 30310-6002HB | 1 |  |  |  | JTAG Connector | https://www.digikey.de/product-detail/de/3m/30310-6002HB/30310-6002HB-ND/1237393 | http://www.mouser.de/ProductDetail/3M/30310-6002HB/
R11 | RC0603FR-071KL | 1 | Resistor | 1k | SMD0603 |  | https://www.digikey.de/product-detail/de/yageo/RC0603FR-071KL/311-1.00KHRCT-ND/ | http://www.mouser.de/ProductDetail/Yageo/RC0603FR-071KL/
R12,R13,R14,R15,R16 | RC0603FR-0710KL | 5 | Resistor | 10k | SMD0603 |  | https://www.digikey.de/product-detail/de/yageo/RC0603FR-0710KL/311-10.0KHRCT-ND/ | http://www.mouser.de/ProductDetail/Yageo/RC0603FR-0710KL/
R21 | RC0603FR-07523RL | 1 | Resistor | 518 | SMD0603 | with ADV7123: use 516ohm resistor; for PAL-Standard: 528ohm/527ohm | https://www.digikey.de/product-detail/de/yageo/RC0603FR-07523RL/311-523HRCT-ND/ | http://www.mouser.de/ProductDetail/Yageo/RC0603FR-07523RL/
R22,R31,R52,R53 | RC0603FR-074K7L | 4 | Resistor | 4k7 | SMD0603 |  | https://www.digikey.de/product-detail/de/yageo/RC0603FR-074K7L/311-4.70KHRCT-ND/ | http://www.mouser.de/ProductDetail/Yageo/RC0603FR-074K7L/
R32 | RC0603FR-07475RL | 1 | Resistor | 475 | SMD0603 |  | https://www.digikey.de/product-detail/de/yageo/RC0603FR-07475RL/311-475HRCT-ND/ | http://www.mouser.de/ProductDetail/Yageo/RC0603FR-07475RL/
R33 | RC0603FR-0775RL | 1 | Resistor | 75 | SMD0603 |  | https://www.digikey.de/product-detail/de/yageo/RC0603FR-0775RL/311-75.0HRCT-ND/ | http://www.mouser.de/ProductDetail/Yageo/RC0603FR-0775RL/
R51 | RC0603FR-0724R9L | 1 | Resistor | 25 | SMD0603 |  | https://www.digikey.de/product-detail/de/yageo/RC0603FR-0724R9L/311-24.9HRCT-ND/ | http://www.mouser.de/ProductDetail/Yageo/RC0603FR-0724R9L/
RN10,RN11,RN12 | CAT16-47R0F4LF | 3 | Resistor Array (4x) | 47 | SMD1206 | Alternative: CAY16-47R0F4LF | https://www.digikey.de/product-detail/de/bourns-inc/CAT16-47R0F4LF/CAT16-47R0F4LFCT-ND/ | http://www.mouser.de/ProductDetail/Bourns/CAT16-47R0F4LF/
RN23,RN41 | CAT16-75R0F4LF | 2 | Resistor Array (4x) | 75 | SMD1206 | Alternative: CAY16-75R0F4LF; Digi-Key Link zur J4LF Serie (5% Toleranz statt 1%) | https://www.digikey.de/product-detail/de/bourns-inc/CAT16-750J4LF/CAT16-750J4LFCT-ND/ | http://www.mouser.de/search/ProductDetail.aspx?R=0virtualkey0virtualkeyCAT16-75R0F4LF

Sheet: TOP
Designator | MPN | QTY | DESCRIPTION | VALUE | PACKAGE | NOTES
U1 | 10CL010YE144C8G | 1 | Cyclone 10 LP FPGA, 10k LE |  | EQFP144 | can be replaced with other FPGAs on demand (see Schematic file)
U2 | ADV7125KSTZ140 | 1 | Video DAC 8bit, 3Ch. |  | 48-LQFP | can be replaced with ADV7123KSTZ140 on demand
U3 | TSH122ICT | 1 | Video Verstärker 1Ch |  | SC-70-6
U4 | SN74LVC3G17DCTR | 1 | Non-Inv Buffer 3Ch., Schmitt Trigger |  | 8-LSSOP, 8-MSOP | TI: DCT Package Footprint
U6 | TLV70012DDCR | 1 | LDO 1.2V |  | SOT-23-5
U7 | TLV70025DDCR | 1 | LDO 2.5V |  | SOT-23-5
U8 | ASE-50.000MHZ-LC-T | 1 | OSC 50MHz | 50MHz | 4-SMD | L x B: 0,126" x 0,098" (3,20 mm x 2,50 mm)
C1,C2 | GRM219R60J476ME44D | 2 | Ceramic capacitor, X5R | 47uF / 6.3V | SMD0805
C121,C301 | GRM21BR60J106ME19L | 2 | Ceramic capacitor, X5R | 10uF / 6.3V | SMD0805
C302,C801 | GRM188R70J103KA01D | 2 | Ceramic capacitor, X7R | 0.01uF / 50V | SMD0603
C33 | GRM32DR60J336ME19L | 1 | Ceramic capacitor, X5R | 33uF / 6.3V | SMD1210
C34 | GRM31CR60J226KE19L | 1 | Ceramic capacitor, X5R | 22uF / 6.3V | SMD1206
C601,C602,C701,C702 | GRM18R60J105KA01J | 4 | Ceramic capacitor, X5R | 1uF / 6.3V | SMD0603
FB1,FB2,FB3,FB4 | MPZ1608S221A | 4 | Ferrit bead, power line |  | SMD0603
R14,R15,R16 | RC0603FR-0710KL | 3 | Resistor | 10k | SMD0603
R21 | RC0603FR-07523RL | 1 | Resistor | 518 | SMD0603 | with ADV7123: use 516ohm resistor; for PAL-Standard: 528ohm/527ohm
R31 | RC0603FR-074K7L | 1 | Resistor | 4k7 | SMD0603
R32 | RC0603FR-07475RL | 1 | Resistor | 475 | SMD0603
R33 | RC0603FR-0775RL | 1 | Resistor | 75 | SMD0603
RN10,RN11,RN12 | CAT16-47R0F4LF | 3 | Resistor Array (4x) | 47 | SMD1206 | Alternative: CAY16-47R0F4LF
RN23,RN41 | CAT16-75R0F4LF | 2 | Resistor Array (4x) | 75 | SMD1206 | Alternative: CAY16-75R0F4LF; Digi-Key Link zur J4LF Serie (5% Toleranz statt 1%)

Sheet: BOT
Designator | MPN | QTY | DESCRIPTION | VALUE | PACKAGE | NOTES
U5 | S25FL116K0XMFB013 | 1 | IC FLASH 16MBIT 108MHZ 8SOIC |  | 8-SOIC | 208mil Body; Digikey ist Alternative im 150mil Body. Footprint ünterstützt beides
C21,C22,C102,C103,C104,C105,C106,C107,C108,C109,C110,C111,C112,C113,C122,C123,C124,C125,C126,C127,C128,C129,C131,C132,C141,C142,C201,C203,C205,C401,C501 | GRM188R71H104KA93J | 31 | Ceramic capacitor, X7R | 0.1uF / 50V | SMD0603
C101 | GRM21BR60J106ME19L | 1 | Ceramic capacitor, X5R | 10uF / 6.3V | SMD0805
C202,C204,C206 | GRM188R70J103KA01D | 3 | Ceramic capacitor, X7R | 0.01uF / 50V | SMD0603
R11 | RC0603FR-071KL | 1 | Resistor | 1k | SMD0603
R12,R13 | RC0603FR-0710KL | 2 | Resistor | 10k | SMD0603
R22,R52,R53 | RC0603FR-074K7L | 3 | Resistor | 4k7 | SMD0603
R51 | RC0603FR-0724R9L | 1 | Resistor | 25 | SMD0603

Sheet: THT
Designator | MPN | QTY | DESCRIPTION | VALUE | PACKAGE | NOTES
J5 | 30310-6002HB | 1 |  |  |  | JTAG Connector

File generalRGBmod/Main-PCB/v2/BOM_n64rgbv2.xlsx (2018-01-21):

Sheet: MaxV Setup
Designator | MPN | QTY | DESCRIPTION | VALUE | PACKAGE | NOTES
ICs and Regulators
U1 | 5M570ZT100C4N | 1 | CPLD with 570LEs |  | TQFP100 | Close J1
 | 5M240ZT100C4N |  | CPLD with 240LEs |  | TQFP100 | Alternative to 5M570ZT100 with less LEs, leave J1 open
U2 | ADV7125KSTZ50 | 1 | Video DAC 8bit, 3Ch. |  | 48-LQFP | can be replaced with ADV7123KSTZ50 on demand
U3 | TSH122ICT | 1 | Video buffer |  | SC-70-6
U4 | TLV70018DDCR | 1 | 1.8V LDO regulator |  | SOT-23-5
Power Supply Filtering
C1,C4 | GRM31CR61A476ME15L | 2 | Ceramic capacitor, X5R | 47uF / 6.3V | SMD0805
FB1,FB2 | BLM18PG471SN1D | 2 | Ferrit bead |  | SMD0603
Remaining passive components
C2,C3,C5,C31 | GRM219R60J476ME44D | 4 | Ceramic capacitor, X5R | 10uF / 6.3V | SMD0805
C10-C19,C20,C22,C24,C27,C28 | GRM188R71H104KA93J | 15 | Ceramic capacitor, X7R | 0.1uF / 50V (10%) | SMD0603
C21,C23,C25,C32 | GRM188R70J103KA01D | 4 | Ceramic capacitor, X7R | 0.01uF / 50V | SMD0603
C33 | GRM32DR60J336ME19L | 1 | Ceramic capacitor, X5R | 33uF / 6.3V | SMD1210
C34 | GRM31CR60J226KE19L | 1 | Ceramic capacitor, X5R | 22uF / 6.3V | SMD1206
C41,C42 | GRM18R60J105KA01J | 2 | Ceramic capacitor, X5R | 1uF / 6.3V | SMD0603
R10 | CRCW06031K00FKTB | 1 | Resistor | 1kohm (1%) | SMD0603
R11, R12 | CRCW0603-10K | 2 | Resistor | 10kohm (1%) | SMD0603
R13 | RC0603FR-07330RL | 1 | Resistor | 330ohm (1%) | SMD0603
R21 | RC0603FR-07523RL | 1 | Resistor | 518 | SMD0603 | with ADV7123: use 516ohm resistor; for PAL-Standard: 528ohm/527ohm
R22,R31 | RC0603FR-074K7L | 2 | Resistor | 4.7kohm (1%) | SMD0603
R32 | RC0603FR-07475RL | 1 | Resistor | 475ohm (1%) | SMD0603
R33 | RC0603FR-0775RL | 1 | Resistor | 75 | SMD0603
RN10,RN11,RN12 | CAT16-47R0F4LF | 3 | Resistor Array (4x) | 47 | SMD1206
RN23 | CAT16-75R0F4LF | 2 | Resistor Array (4x) | 75 | SMD1206
J3 | 30310-6002HB | 1 |  |  |  | JTAG Connector
Unpopulated Footprints
FB3 | Don't use FB3 in MaxV setup!!! Otherwise you'll harm your CPLD at first power cycle
MPNs are only suggestions! You can use equivalent components, too.

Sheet: MaxII Setup
Designator | MPN | QTY | DESCRIPTION | VALUE | PACKAGE | NOTES
ICs and Regulators
U1 | EPM570T100C5N | 1 | CPLD with 570LEs |  | TQFP100 | Close J1
 | EPM240T100C5N |  | CPLD with 240LEs |  | TQFP100 | Alternative to EPM570T100C5N with less Les, leave J1 open
U2 | ADV7125KSTZ50 | 1 | Video DAC 8bit, 3Ch. |  | 48-LQFP | can be replaced with ADV7123KSTZ50 on demand
U3 | TSH122ICT | 1 | Video buffer |  | SC-70-6
Power Supply Filtering
C1,C4 | GRM31CR61A476ME15L | 2 | Ceramic capacitor, X5R | 47uF / 6.3V | SMD0805
FB1,FB2,FB3 | BLM18PG471SN1D | 3 | Ferrit bead |  | SMD0603
Remaining passive components
C2,C3,C5,C31 | GRM219R60J476ME44D | 4 | Ceramic capacitor, X5R | 10uF / 6.3V | SMD0805
C10-C19,C20,C22,C24,C27,C28 | GRM188R71H104KA93J | 15 | Ceramic capacitor, X7R | 0.1uF / 50V (10%) | SMD0603
C21,C23,C25,C32 | GRM188R70J103KA01D | 4 | Ceramic capacitor, X7R | 0.01uF / 50V | SMD0603
C33 | GRM32DR60J336ME19L | 1 | Ceramic capacitor, X5R | 33uF / 6.3V | SMD1210
C34 | GRM31CR60J226KE19L | 1 | Ceramic capacitor, X5R | 22uF / 6.3V | SMD1206
R10 | CRCW06031K00FKTB | 1 | Resistor | 1kohm (1%) | SMD0603
R11, R12 | CRCW0603-10K | 2 | Resistor | 10kohm (1%) | SMD0603
R13 | RC0603FR-07330RL | 1 | Resistor | 330ohm (1%) | SMD0603
R21 | RC0603FR-07523RL | 1 | Resistor | 518 | SMD0603 | with ADV7123: use 516ohm resistor; for PAL-Standard: 528ohm/527ohm
R22,R31 | RC0603FR-074K7L | 2 | Resistor | 4.7kohm (1%) | SMD0603
R32 | RC0603FR-07475RL | 1 | Resistor | 475ohm (1%) | SMD0603
R33 | RC0603FR-0775RL | 1 | Resistor | 75 | SMD0603
RN10,RN11,RN12 | CAT16-47R0F4LF | 3 | Resistor Array (4x) | 47 | SMD1206
RN23 | CAT16-75R0F4LF | 2 | Resistor Array (4x) | 75 | SMD1206
J3 | 30310-6002HB | 1 |  |  |  | JTAG Connector
Unpopulated Footprints
U4,C41,C42 | These components are for MaxV setup only!!! Leave them free.
MPNs are only suggestions! You can use equivalent components, too.

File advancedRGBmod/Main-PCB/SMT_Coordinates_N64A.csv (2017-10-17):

Designator | Footprint | Mid XＢmm） | Mid YＢmm） | Layer | Rotation
U1 | EQFP144 | 31.11 | 18.41 | T | 45
U2 | LQFP48 | 51.94 | 13.97 | T | 0
U3 | SC-70-6 | 46.86 | 27.94 | T | 0
U4 | SSOP-8 | 43.05 | 34.93 | T | 0
U5 | SO-08 | 5.72 | 14.48 | B | 90
U6 | SOT23-5 | 17.14 | 31.75 | T | 270
U7 | SOT23-5 | 17.14 | 35.56 | T | 270
U8 | 4-SMD | 7.62 | 10.79 | T | 180
C1 | C0805 | 7.62 | 35.56 | T | 180
C2 | C0805 | 58.42 | 6.22 | T | 180
C21 | C0603 | 58.93 | 21.84 | B | 270
C22 | C0603 | 56.90 | 21.84 | B | 270
C33 | C1210 | 51.94 | 29.08 | T | 0
C34 | C1206 | 51.94 | 25.91 | T | 0
C101 | C0805 | 10.03 | 31.75 | B | 0
C102 | C0603 | 20.57 | 8.64 | B | 315
C103 | C0603 | 23.50 | 5.71 | B | 315
C104 | C0603 | 34.04 | 5.59 | B | 45
C105 | C0603 | 33.66 | 10.79 | B | 45
C106 | C0603 | 36.83 | 13.97 | B | 45
C107 | C0603 | 43.82 | 11.43 | B | 225
C108 | C0603 | 39.50 | 20.19 | B | 315
C109 | C0603 | 35.31 | 24.51 | B | 315
C110 | C0603 | 23.62 | 31.24 | B | 45
C111 | C0603 | 22.23 | 29.84 | B | 45
C112 | C0603 | 24.89 | 22.35 | B | 225
C113 | C0603 | 21.59 | 19.05 | B | 225
C121 | C0805 | 24.77 | 32.38 | T | 0
C122 | C0603 | 16.00 | 14.61 | B | 0
C123 | C0603 | 24.89 | 4.32 | B | 315
C124 | C0603 | 32.26 | 9.40 | B | 45
C125 | C0603 | 38.48 | 15.62 | B | 45
C126 | C0603 | 41.02 | 18.67 | B | 315
C127 | C0603 | 32.00 | 27.69 | B | 315
C128 | C0603 | 25.02 | 32.64 | B | 45
C129 | C0603 | 23.14 | 20.57 | B | 225
C131 | C0603 | 32.39 | 3.94 | B | 225
C132 | C0603 | 27.06 | 34.66 | B | 45
C141 | C0603 | 26.80 | 2.41 | B | 315
C142 | C0603 | 35.56 | 34.29 | B | 135
C201 | C0603 | 49.91 | 11.94 | B | 180
C202 | C0603 | 49.91 | 13.97 | B | 180
C203 | C0603 | 53.59 | 10.41 | B | 0
C204 | C0603 | 53.59 | 12.45 | B | 0
C205 | C0603 | 53.59 | 14.73 | B | 0
C206 | C0603 | 53.59 | 16.76 | B | 0
C301 | C0805 | 51.31 | 31.13 | T | 0
C302 | C0603 | 46.86 | 30.48 | T | 180
C401 | C0603 | 48.26 | 35.94 | B | 180
C501 | C0603 | 10.16 | 18.54 | B | 180
C601 | C0603 | 13.34 | 31.75 | T | 270
C602 | C0603 | 20.96 | 31.75 | T | 270
C701 | C0603 | 13.34 | 35.43 | T | 270
C702 | C0603 | 20.96 | 35.56 | T | 270
C801 | C0603 | 10.67 | 10.79 | T | 90
FB1 | R0603 | 7.37 | 33.02 | T | 0
FB2 | R0603 | 59.69 | 9.53 | T | 180
FB3 | R0603 | 24.77 | 34.42 | T | 180
FB4 | R0603 | 12.70 | 10.79 | T | 270
R11 | R0603 | 2.29 | 5.84 | B | 0
R12 | R0603 | 2.29 | 3.30 | B | 0
R13 | R0603 | 19.05 | 3.30 | B | 180
R14 | R0603 | 16.13 | 10.54 | T | 180
R15 | R0603 | 14.22 | 14.48 | T | 180
R16 | R0603 | 49.50 | 29.21 | T | 270
R31 | R0603 | 43.05 | 30.48 | T | 0
R32 | R0603 | 43.05 | 27.94 | T | 0
R33 | R0603 | 56.52 | 25.91 | T | 0
RN10 | CTS742C083 | 8.26 | 16.51 | T | 270
RN11 | CTS742C083 | 8.26 | 20.96 | T | 270
RN12 | CTS742C083 | 8.26 | 25.40 | T | 270
RN23 | CTS742C083 | 59.69 | 15.11 | T | 270
RN41 | CTS742C083 | 49.91 | 35.43 | T | 270
R21 | R0603 | 53.34 | 19.05 | B | 0
R22 | R0603 | 54.86 | 21.84 | B | 90
R51 | R0603 | 10.16 | 11.30 | B | 180
R52 | R0603 | 10.16 | 13.34 | B | 180
R53 | R0603 | 10.16 | 15.37 | B | 180

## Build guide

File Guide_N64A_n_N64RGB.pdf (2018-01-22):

# N64 Advanced and

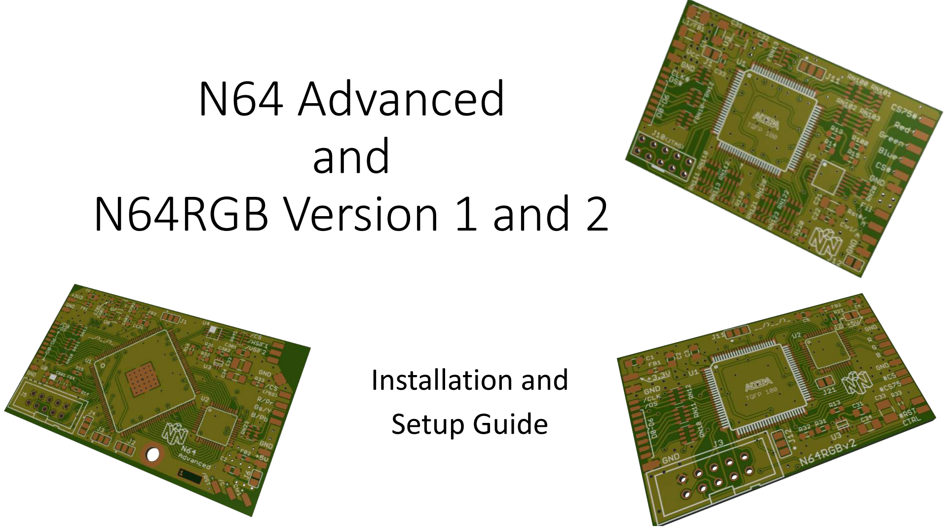
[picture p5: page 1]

# N64RGB Version 1 and 2

# Installation and Setup Guide

# Content

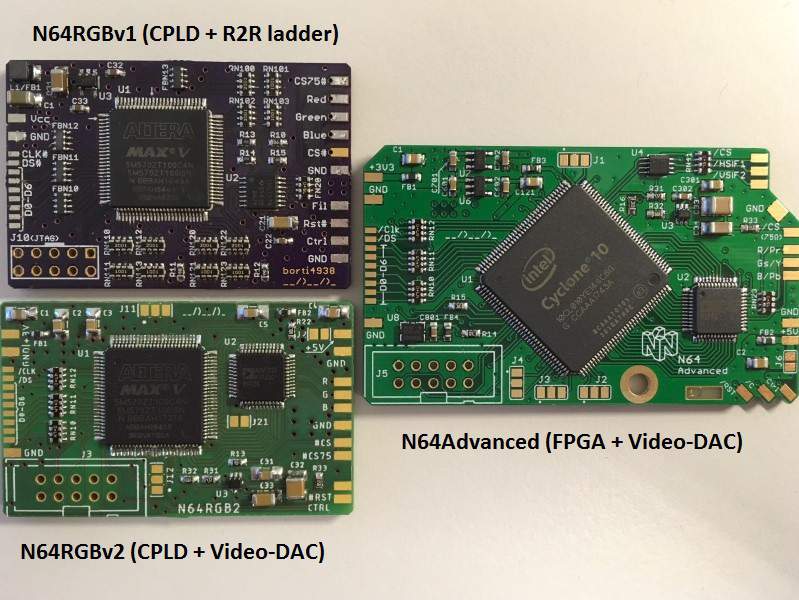
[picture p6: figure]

# - Open the Console - Preparation - Solder Work

## - Console - Modding Kit

# - Settings (Solder Jumper) - Cable Setup - Controller – In Game Routines - Firmwareupdate

# Open the Console

## - Remove Jumper Pak / Expansion Pak - Remove screws from bottom side of the console (needs 4.5mm game bit tool) - Lift up the top housing

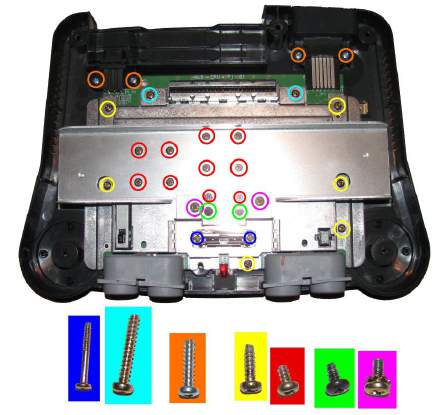
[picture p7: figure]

## - Remove marked screws from inside (in some later consoles heat sink is designed differently) - Pull out the mainboard and remove heat sink and RF shield - Hint: Now you have a good chance to clean

up your N64 shell under hot water.

Picture by Zerberus (circuit-board.de user)

# Preparation – Top RF shield

# - Next to the MultiOut and the cartridge slot

## - Locate the tap in the RF shield closing the gap to the N64 mainboard - Bend away or remove this tap or even cut off a small piece out of the RF shield as shown here

# - At the front side between reset button and controller port:

## - Slightly bend off the tap here

# - This helps later to fit the connection wire

Cut away | Bend away

# Preparation – Top RF shield -- Interference issue--

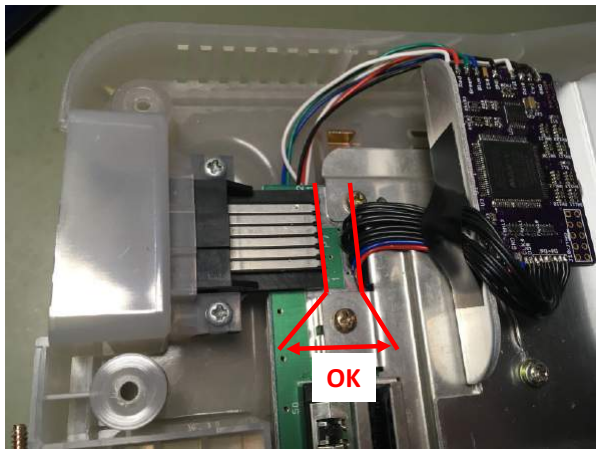
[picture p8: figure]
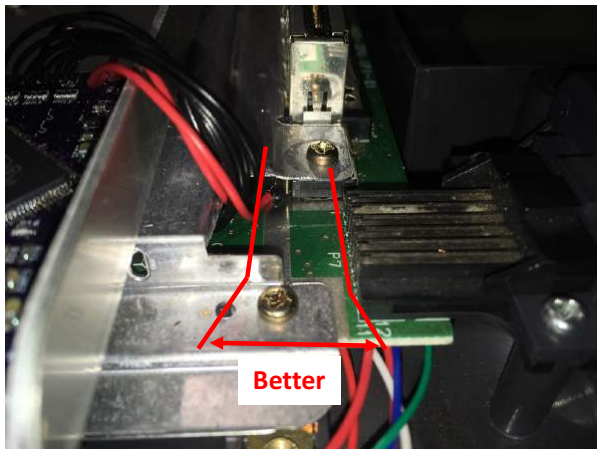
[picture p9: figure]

- Later, the data lines as well as the clock will be routed close to the MultiAV - The distance between both is a crucial issue as your wires act as interferer - Hence, have tap bend might be ok, but it is better to cut some piece of the RF shield away to further increase the distance between MultiAV and data lines

OK | Better

# Preparation – Mount the PCB (N64A only)

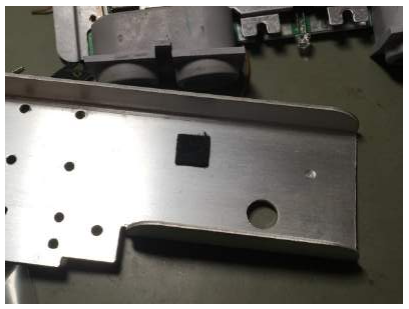
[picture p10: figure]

- Put a small piece of a
flat isolationg foam or
glider under the top left
of the PCB
(OPTIONAL)

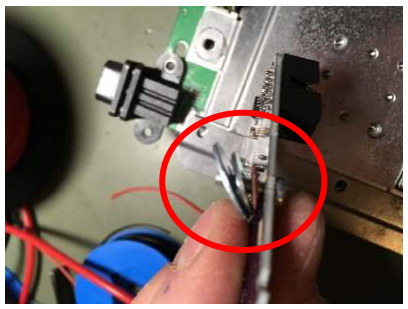
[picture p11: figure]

Mounting material:
- Screw
(M3 diameter,
min. 10mm, max. 14mm)
- 3x washer below PCB:
- isolating or small outer diameter
(three traces are close to the mounting hole)
- a slightly larger washer
- a large washer
(such that this washer does not fit through the mounting hole of the heat sink)

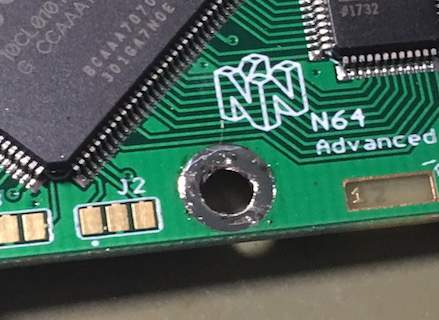
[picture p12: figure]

- Apply some amount of
solder to the mounting
hole
- This helps later to have a better connection to the
screw

# Preparation – Mount the PCB (N64A only)

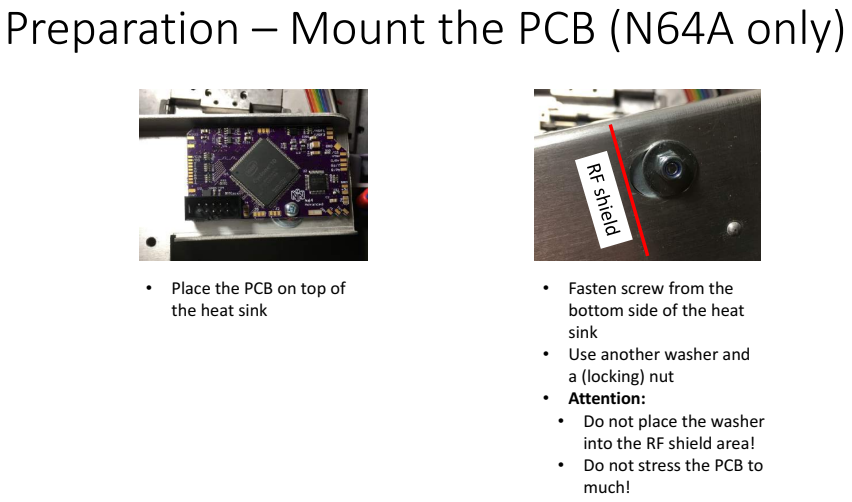
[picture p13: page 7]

• Place the PCB on top of
the heat sink

• Fasten screw from the
bottom side of the heat
sink
• Use another washer and
a (locking) nut
• Attention:
• Do not place the washer
into the RF shield area!
• Do not stress the PCB to
much!

# Preparation – Mount the PCB (N64RGB only)

(no pictures atm)

## - The N64RGB does not have a mounting hole to keep the size as small as possible - Isolate the PCB from the bottom - Fix the PCB into the heat sink (similar position as the N64A) using double side tape or other adhesive pads or hot glue

# Solder Work – Console -- digital video signals --

Pin 10 (marked with a dot)

Pinout RCP-NUS

Pinouts of different encoder chips used in the N64

Most of the signals needed has to be taken from video processor output; the RCP-NUS.
Next to the RCP-NUS is the video encoder, where several types are used during the variety of N64 designs. The pinouts are given below. Basically we need D0-D6, /DSYNC and /CLK (or VCLK or CLOCK) for the modding board.

RCP-NUS picture by Marshall Encoder picture by Viletim

# Solder Work – Console -- digital video signals and 3.3V and GND --

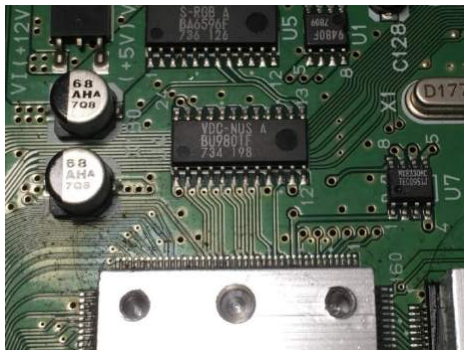
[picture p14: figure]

# - Locate the video encode (here a VDC-NUS) - Solder a bunch of wires to the video signal pins

- You may use an adapter if you have a MAV-NUS or AVDC-NUS encoder (see README)

# - Solder two addional wires one for 3.3V (can be picked off C141) and one for GND (large GND plain)

# - Route all wires approximately to the MultiAV port

# Solder Work – Console -- Controller and Reset --

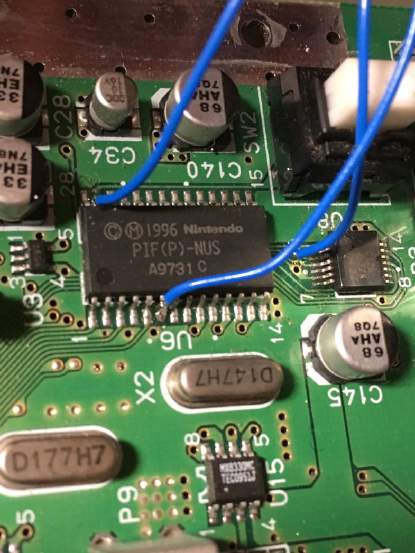
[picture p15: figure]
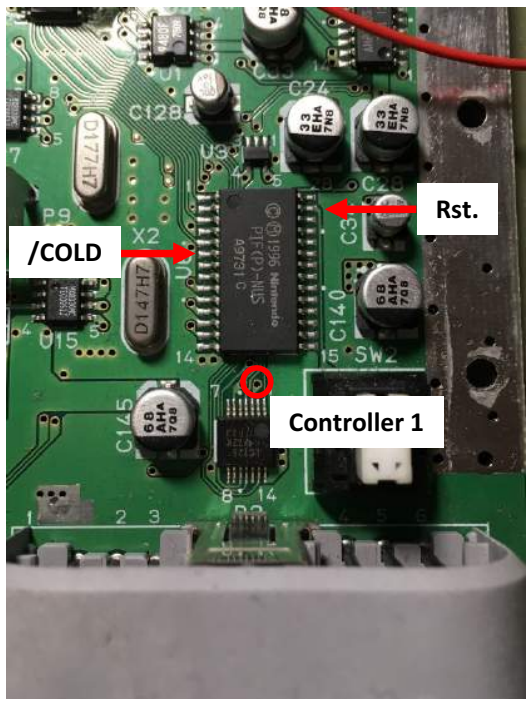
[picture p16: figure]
Rst.; /COLD; Controller 1

## - All signals for the controller and the reset can be picked off the PIF-NUS which is located next to the reset button - Solder the following wires:

- One for reset (PIF-NUS pin 27)
- One for the controller input
in my case: the marked via, sometimes also PIF-NUS pin 16
in any case: search for a suiteable connection to the middle pin of controller port 1
- N64A only:
one for /COLD (PIF-NUS pin 6) (atm not used in the current implementation)

# Solder Work – Console -- MultiAV port – analoge video output --

# - Prepare some wires for:

- Pin 1: | Red / Pr
- Pin 2: | Green / Y
- Pin 3: | Sync *
- Pin 4: | Blue / Pb

## - Pin 5 / 6: GND - Pin 7: Sync * - Pin 10: +5V (N64A only)

* Sync:

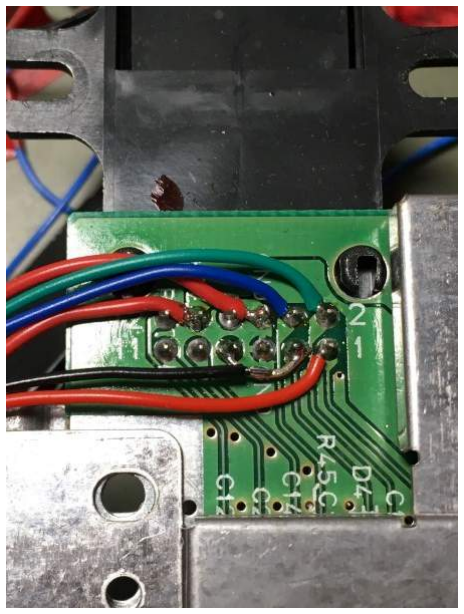
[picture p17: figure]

You need to take the composite sync out of the modding board. Depending on your RGB cable, you need to use pin 3 (sync on csync cable) or pin 7 (sync on luma cable). I soldered a bridge between both pins to make it useable with both types of cables.
Sometimes pin 3 / 7 is used in your stock console. Make sure that the pin / these pins is / are unconnected.

Solder Work – Miscellaneous -- Other PIF-NUS configurations and proper Controller 1 solder points --

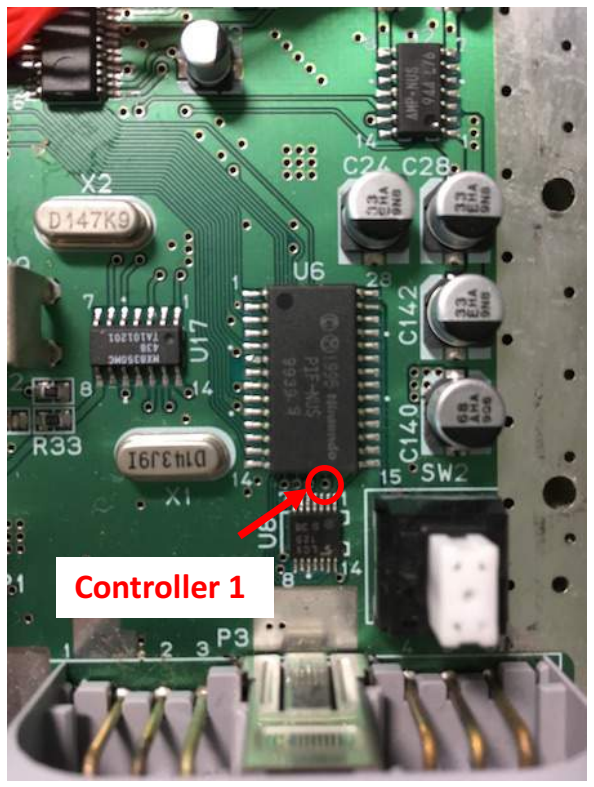
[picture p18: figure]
Controller 1
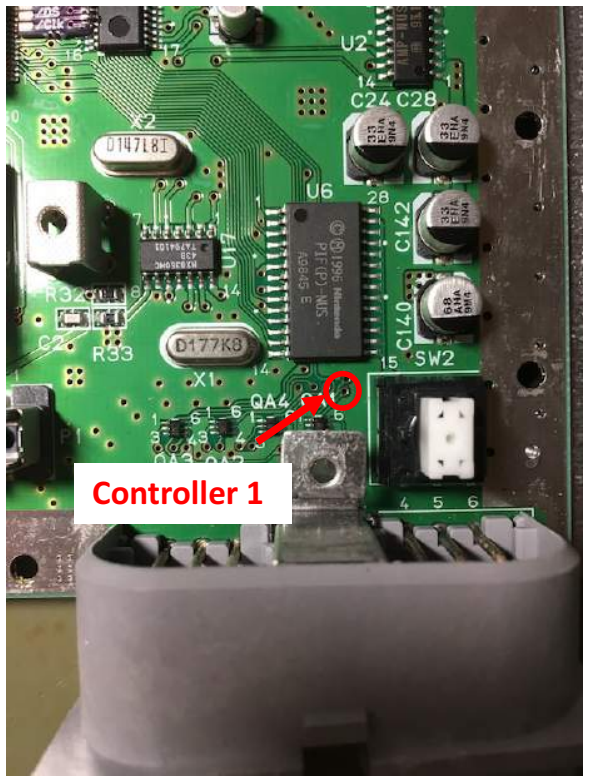
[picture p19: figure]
Controller 1

# Solder Work – Miscellaneous -- MAV-NUS--

# - The MAV-NUS and the AVDC-NUS have a small pitch of 0.8mm - You may want to use the MAV-NUS breakout board to work on a 1.27mm pitch - Check connectivity between the RCP-NUS and the pads on the breakout with a DMM

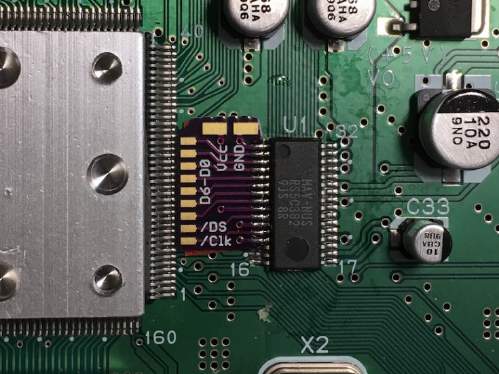
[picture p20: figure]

# - Check for adjacent shorts

# Solder Work – Miscellaneous -- Marking wires --

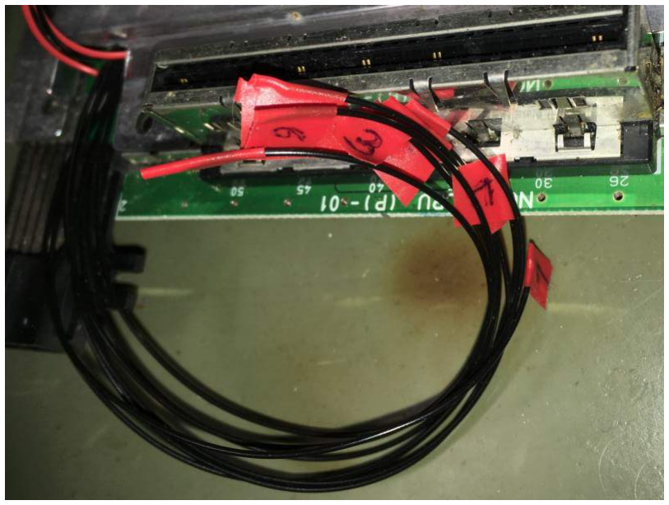
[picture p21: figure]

# - If you use lose wires as I do, you may mark them before you go on

# Solder Work – Modding Kit -- N64 Advanced --

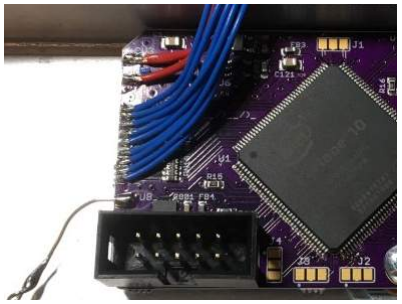
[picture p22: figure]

## - Reassemble the top RF shield and heat sink on top of the N64 mainboard

## - Make sure that you do not squeeze any of the wires you prepared - For that you cut and/or bend the taps of the RF shield

## - Connect +3.3V and GND to the left hand side of the modding kit - Connect the seven data lines and /DSYNC and /CLK to the appropriate pads

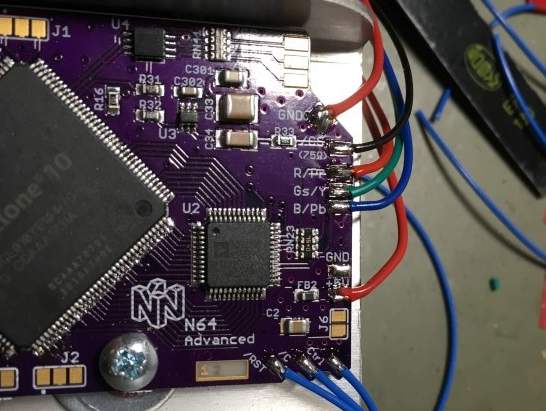
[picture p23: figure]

- Connect the wires for /Rst., Ctrl. (Controller) and /C (/Cold) to the pads at the bottom right of the

## modding kit - Connect the video lines, GND and +5V to the right hand side of the modding kit

# Solder Work – Modding Kit -- N64RGB --

## - Reassemble the top RF shield and heat sink on top of the N64 mainboard

- Make sure that you do not squeeze any of the wires you prepared

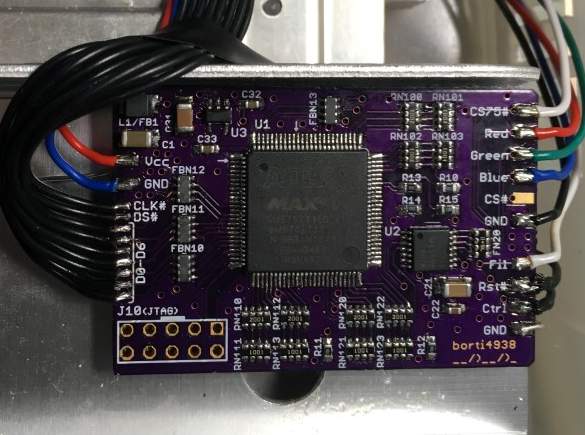
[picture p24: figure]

- For that you cut and/or bend the taps of the RF shield

- Connect +3.3V (Vcc) and GND to the left hand side of the modding kit - Connect the seven data lines and /DSYNC and /CLK to the appropriate pads - Connect the wires for /Rst. and Ctrl. (Controller) to the pads at the bottom right of the modding kit - Connect the video lines and GND to the right hand side of the modding kit - You may want to use the Fil pad to toggle the LPF on and off (see jumper section)

# Solder Work – Modding Kit -- Some extra GND --

- To reduce the GND loop size, it is helpful to assemble some extra GND connections to the N64 mainboard - If the GND is not properly designed between the N64 mainboard and modding kit some current out of the digital signals flows back to the N64 throgh the analog video connections. This causes visible noise!

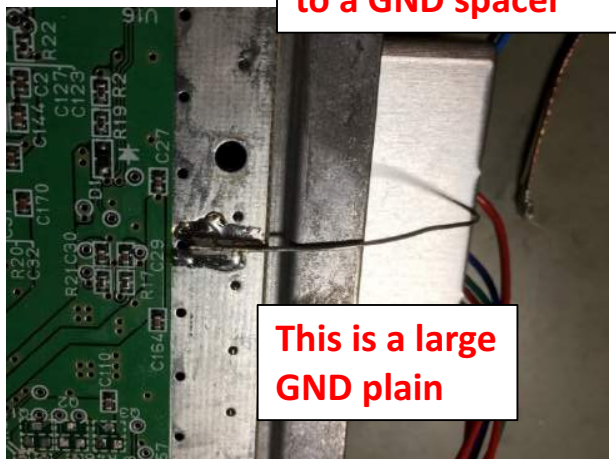
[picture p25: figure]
This is a large GND plain

# - I assembled two extra connection: one on the left hand side of the modding PCB and

one at the right hand side.

to a GND spacer

# Settings – Solder Jumper (N64 Advanced)

J5: 10pin JTAG interface
for update firmware

J4: Linemode

J4.1: - opened: linedoubling enabled
- closed: no linedoubling (beats J4.2) J4.2: - opened: 480i pass through
- closed: 480i de-interlace (bob)

J3: Scanline strenght
(J3.2/J3.1) =
- (opened/opened): 0%
- (opened/closed): 25%
- (closed/opened): 50%
- (closed / closed): 100%

J2: RGB, RGsB, YPbPr
J2.1: - opened: RGB output
- closed: RGsB output
J2.2: - opened: RGB / RGsB output
- closed: YPbPr output (beats J2.1)

J1: VGA sync / Filter AddOn J1.1: - opened: output HS, VS and CS (VGA output possible)
- closed: use filter addon
J1.2: - Use filter board in bypass mode (e.g. to use it as a simple
NTSC output to PAL output conversion) J6: Analog power supply
- opened: +5V (connect +5V to pad)
- closed: +3.3V (do not connect +5V to +5V pad in this case)

Notes for dual jumper:
- Jx.1 is always marked with a dot
- Closed reference is middle pad

Fallback Mode:
- Fallback is active if reset button is pressed on powering on
- fallback: 240p/480i and RGB output

# Settings – Solder Jumper (N64 RGBv1)

J10: 10pin JTAG interface

for update firmware | J12: IGR / Mechanical Switches
- opened: Use IGR (Ctrl. and /Rst)
- closed: Use switches at M and A pads

J11: De-Blur with IGR active
J11.1: (only applicable with heuristic off)
- opened: default de-blur on
- closed: default de-blur off J11.2: - opened: use de-blur heuristic
- closed: bypass de-blur heuristic

Notes for dual jumper J11:
- J11.1 is marked with a dot
- Closed reference is middle pad

M: Manual (only with J12 closed)
- opened: no de-blur or de-blur heuristic
- grounded: de-blur in any 240p case (beats heuristic)
A: Auto (only with J12 closed)
- opened: bypass de-blur heuristic
- grounded: use de-blur heuristic

Fil: Video filter
- opened: Use filter of the THS7374
- grounded: THS7374 in bypass mode

Hidden Jumper between
pin 36 and 37:
- short both pins to activate 15bit mode by default

J1: (bottom side)
- opened: use a CPLD
with 240LEs
- closed: use a CPLD
with 570LEs

# Settings – Solder Jumper (N64 RGBv2)

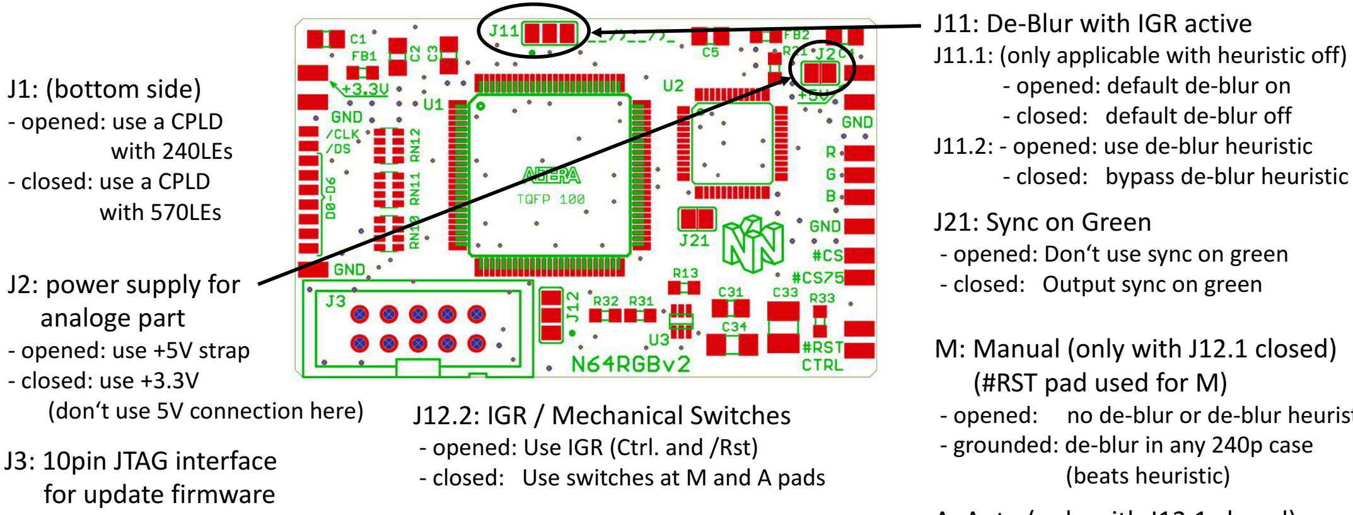
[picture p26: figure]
J3: 10pin JTAG interface for update firmware; J11: De-Blur with IGR active; - opened: default de-blur on - closed: default de-blur off J11.2: - opened: use de-blur heuristic - closed: bypass de-blur heuristic; M: Manual (only with J12.1 closed) (#RST pad used for M); - grounded: de-blur in any 240p case (beats heuristic); J12.2: IGR / Mechanical Switches - opened: Use IGR (Ctrl. and /Rst); J21: Sync on Green - opened: Don‘t use sync on green; analoge part - opened: use +5V strap - closed: use +3.3V (don‘t use 5V connection here)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

J12.1: 15bit mode default
- opened: 15 bit mode off by default
- closed: 15 bit mode on by default

J11.1: (only applicable with heuristic off)

Notes for dual jumper J11:
- J1#.1 is marked with a dot
- Closed reference is middle pad
- opened: no de-blur or de-blur heuristic

A: Auto (only with J12.1 closed) (CTRL pad used for A)
- opened: bypass de-blur heuristic
- grounded: use de-blur heuristic
- closed: Use switches at M and A pads
J2: power supply for | - closed: Output sync on green

# Cable Setup -- N64RGBv2 and N64 Advanced --

Name | MultiAV | SCART plug | Ref. GND in SCART | Cinch plugs | Notes
Red / Pr | 1 | 15 | 13 | Red plug | Using a 220uF cap in series is possible
Green / Y | 2 | 11 | 9 | Green plug | Using a 220uF cap in series is possible
Blue / Pb | 4 | 7 | 5 | Blue plug | Using a 220uF cap in series is possible
Sync | 3 or 7 | 20 | 17 | Not needed | Consider notes on next page
GND | 5, 6 | 4, 5, 9, 13, 17, 18, 21 | | To outer ring of each plug | Pin 21 @ SCART plug is outer shield
+5V | 10 | 16 | 18 | Not needed | Use a 180ohm resistor in series
Audio left | 11 | 6 | 4 | Red plug
Audio right | 12 | 2 | 4 | White plug

# Cable Setup

# -- N64RGBv2 and N64 Advanced --

- Notes on Sync:
- I recommend using the 75ohm compatible csync output.
- If you do so then run a straight wire through your cable for sync.
- If you use TTL sync output, you have to add an additional resistor in series (N64RGv2: 0ohm to 900ohm; N64A: 270ohm to 1.1kohm) to attenuate the signal for 75ohm terminationed destinations.
- RGB cables:
- If you buy an RGB cable, buy a typical RGB cable for a NTSC SNES with sync on luma (MultiAV pin 7) or sync on csync (MultiAV pin 3).
- If you bought a raw csync cable and if you use the 75ohm output, remove / short the resistor which is possibly installed in the sync trace.

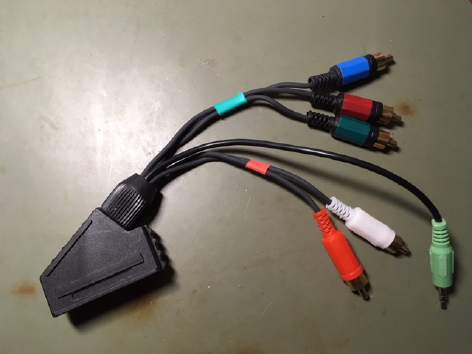
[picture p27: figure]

- RGsB / YPbPr Cables:
- With the given table you should be able to build your own component cable or to build an adapter (see pictures on left side)
- Unfortunately, there are no cables / adapter to bought.

# Cable Setup

# -- Filter Add On for the N64RGBv2 and N64 Advanced --

- Use the Filter AddOn if your ADC device does not apply input filtering (e.g. some capture cards)
- Solder the board onto the MultiAV and decide where /CS has to go – pin 3 and/or pin 7 – depending on your setup
- All connections to the N64RGBv2 and N64A are labeled
- A note on PAL SNES RGB cables:
- By default the N64RGBv2 and N64A are not suitable to use it with PAL SNES RGB cables
- By using the Filter AddOn board one can convert the output such that it is possible to buy a stock PAL SNES RGB cable (with sync on luma)
- Just use the Filter Addon board and use a 39Ohm resistor array at the output (marked with a red arrow)
- N64RGBv2
- To use the LPF of the adapter board, left F1 and F2 floating or connect them to GND
- To bypass the LPF, connect F1 and F2 pads to +5V.
- N64 Advanced:
- Remind to set J1.1 on the N64A
- Set J1.2 if you want to have the filter off, e.g. in the case you simply want to use a PAL SNES RGB cable
(actually they will be set to 95MHz cut-off, which is way above the
video content)

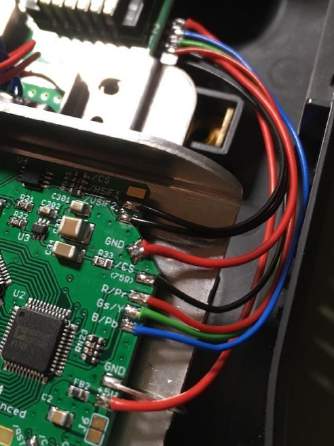
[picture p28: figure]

# Cable Setup -- N64 RGBv1 --

Name | MultiAV | SCART plug | Ref. GND in SCART | Notes | PAL assembly | NTSC assembly
Red | 1 | 15 | 13 | | Use 75ohm resistor to reference GND | Using a 220uF cap in series is possible
Green | 2 | 11 | 9 | | Use 75ohm resistor to reference GND | Using a 220uF cap in series is possible
Blue | 4 | 7 | 5 | | Use 75ohm resistor to reference GND | Using a 220uF cap in series is possible
Sync | 3 or 7 | 20 | 17 | Consider notes on next page | Using a 220uF cap in series is possible
GND | 5, 6 | 4, 5, 9, 13, 17, 18, 21 | | Pin 21 @ SCART plug is outer shield
+5V | 10 | 16 | 18 | Use a 180ohm resistor in series
Audio left | 11 | 6 | 4
Audio right | 12 | 2 | 4

# Cable Setup

# -- N64 RGBv1 --

## - PAL or NTSC assembly:

### - Depends on RN20 - PAL assembled kits have 39ohm resistor array installed - NTSC assembled kits have 75ohm resistor array installed

- Notes on Sync: • I recommend using the 75ohm compatible csync output.
- If you do so then run a straight wire through your cable for sync. For PAL assembly an optional resistor of 75ohm to reference GND can be installed.
- If you use TTL sync output, you have to add an additional resistor in series.
- R15 = 330ohm … series resistor of size 0ohm to 420ohm
- R15 = 0ohm … series resistor of size 330ohm to 750ohm

## - RGB cables:

- It‘s possible to buy pre-build RGB cable with either PAL SNES or NTSC SNES setup.
- Use a cable with sync on luma (MultiAV pin 7) or sync on csync (MultiAV pin 3).
- If you bought a raw csync cable and if you use the 75ohm output, remove / short the resistor which is possibly installed in the sync trace.

# Controller – In Game Routines

## - The controller is able to trigger a reset or to change de-blur and 15bit mode option - Button combinaton: Start + R + Z + … - … A + B : trigger a reset - … C-ri : de-blur for 240p on - … C-le : de-blur for 240p off - … C-up : 15bit mode off - … C-dw : 15bit mode on

R

Basis for all button combinations

Notes:
- Controller is only read if the actual game reads the controller
- Switching de-blur overwrites the heuristic estimation.
De-blur option is reset with each triggered reset and power cycle
- 15bit mode is reset with each power cycle

# Firmwareupdate

# -- Download the software tools --

1. Go to altera.com and select “Downloads” from the “SUPPORT” menu
2. Select “Download” from the “Light Edition” column of the “Design Software” (preselected)
3. Go to “Additional Software”
4. Download the “Quartus Prime Programmer and Tools software

If you have the Quartus Prime edition installed, the programmer tools are already available on your computer.

Date: 22.11.2017
Website layout may change

# Firmwareupdate

# -- Update your N64 Advanced --

- Connect your PC with the USB Blaster and the USB Blaster with the modding kit J5 - Download the actual firmware build from the GitHub repository folder advancedRGBmod/firmware/output_files/yourFPGA/n64 a_yourfpga.jic - Open the programmer tool - Load the previously downlaoded JIC file with “Add File…” - Check “Program/Configure” for the FPGA and “Program/Configure” and “Verify” for the Flashdevice - Make sure that the USB Blaster is selected in the “Hardware Setup” - Click on “Start” (the N64 has to be powered for the reference voltage) and wait for the process to be finished - Power cycle your N64 and enjoy :)

Quartus Prime Lite v17.1

# Firmwareupdate

# -- Update your N64 RGB --

### - Connect your PC with the USB Blaster and the USB Blaster with the modding kit J10 - Download the actual firmware build from the GitHub repository folder

generalRGBmod/firmware/output_files/v#/n64rgb_yourcpld.pof

### - Open the programmer tool - Load the previously downlaoded POF file with “Add File…” - Check “Program/Configure” and “Verify” for the CFM part of your device

### - Make sure that the USB Blaster is selected in the “Hardware Setup” - Click on “Start” (the N64 has to be powered for the reference voltage) and wait for the process to be finished

Quartus Prime Lite v17.1

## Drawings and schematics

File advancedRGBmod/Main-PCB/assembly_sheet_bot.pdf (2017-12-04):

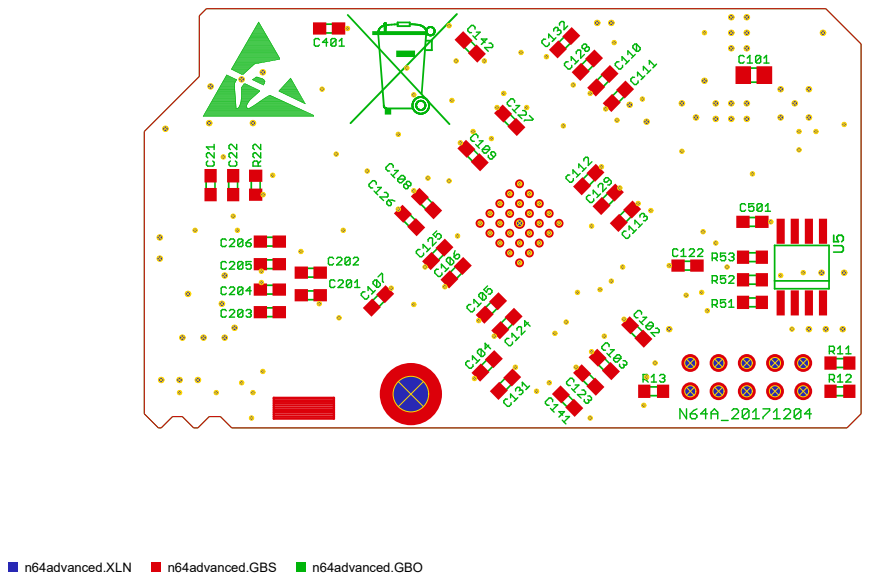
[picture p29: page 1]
n64advanced.XLN; n64advanced.GBS; n64advanced.GBO

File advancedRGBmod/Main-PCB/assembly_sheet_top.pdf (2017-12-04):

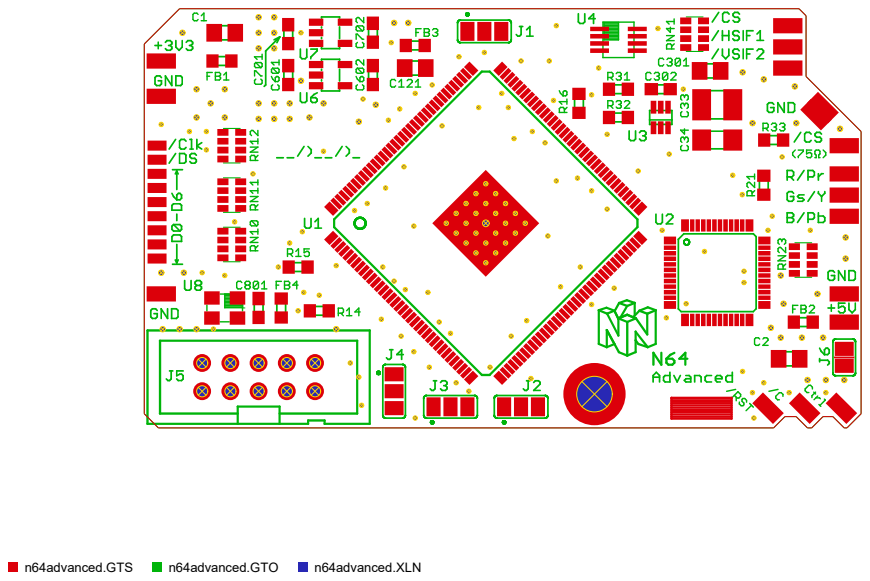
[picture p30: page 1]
n64advanced.GTS; n64advanced.GTO; n64advanced.XLN

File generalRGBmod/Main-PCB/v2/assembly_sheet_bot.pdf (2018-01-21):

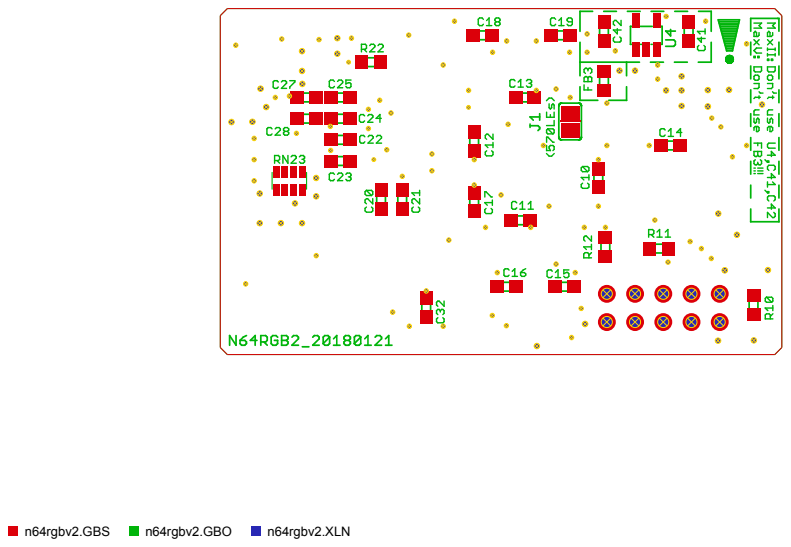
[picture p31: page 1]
n64rgbv2.GBS; n64rgbv2.GBO; n64rgbv2.XLN

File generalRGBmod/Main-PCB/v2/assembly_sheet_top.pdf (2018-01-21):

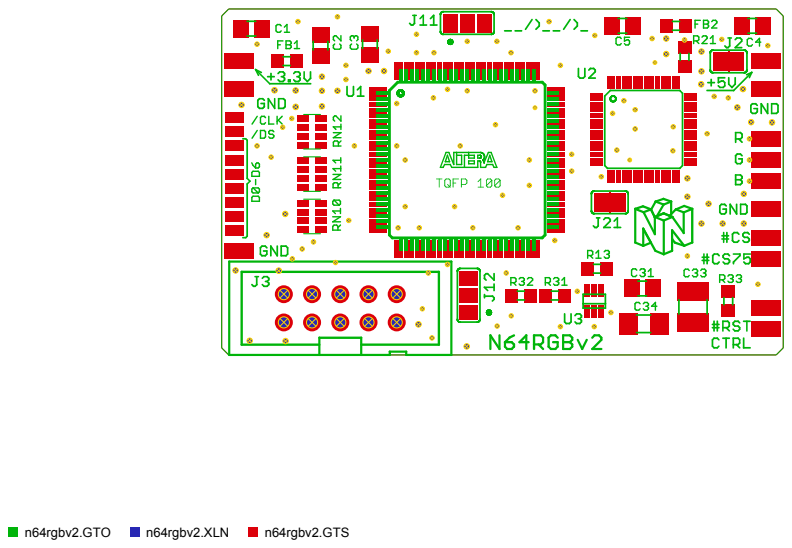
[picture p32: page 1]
n64rgbv2.GTO; n64rgbv2.XLN; n64rgbv2.GTS

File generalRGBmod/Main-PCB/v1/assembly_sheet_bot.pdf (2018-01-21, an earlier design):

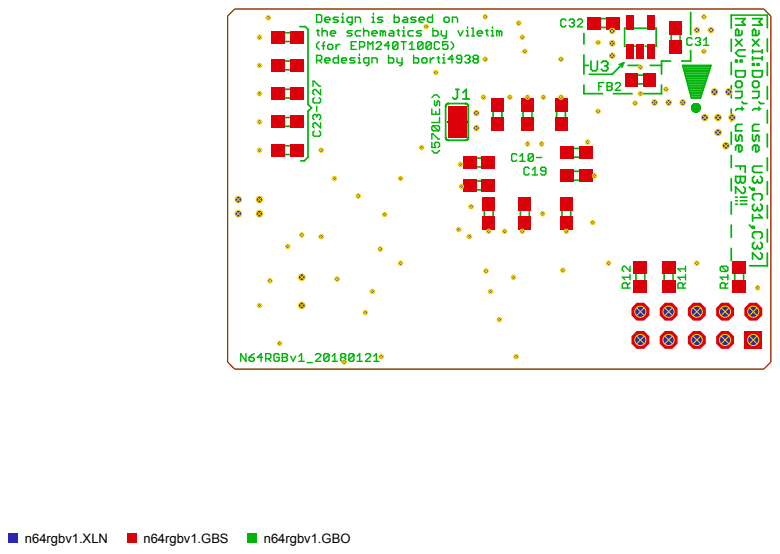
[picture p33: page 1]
n64rgbv1.XLN; n64rgbv1.GBS; n64rgbv1.GBO

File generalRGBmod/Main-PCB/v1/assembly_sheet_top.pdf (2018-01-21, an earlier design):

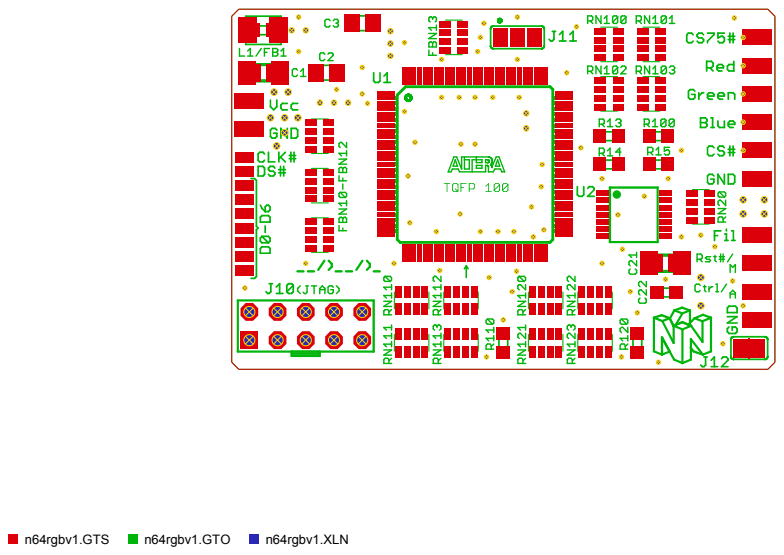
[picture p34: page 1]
n64rgbv1.GTS; n64rgbv1.GTO; n64rgbv1.XLN

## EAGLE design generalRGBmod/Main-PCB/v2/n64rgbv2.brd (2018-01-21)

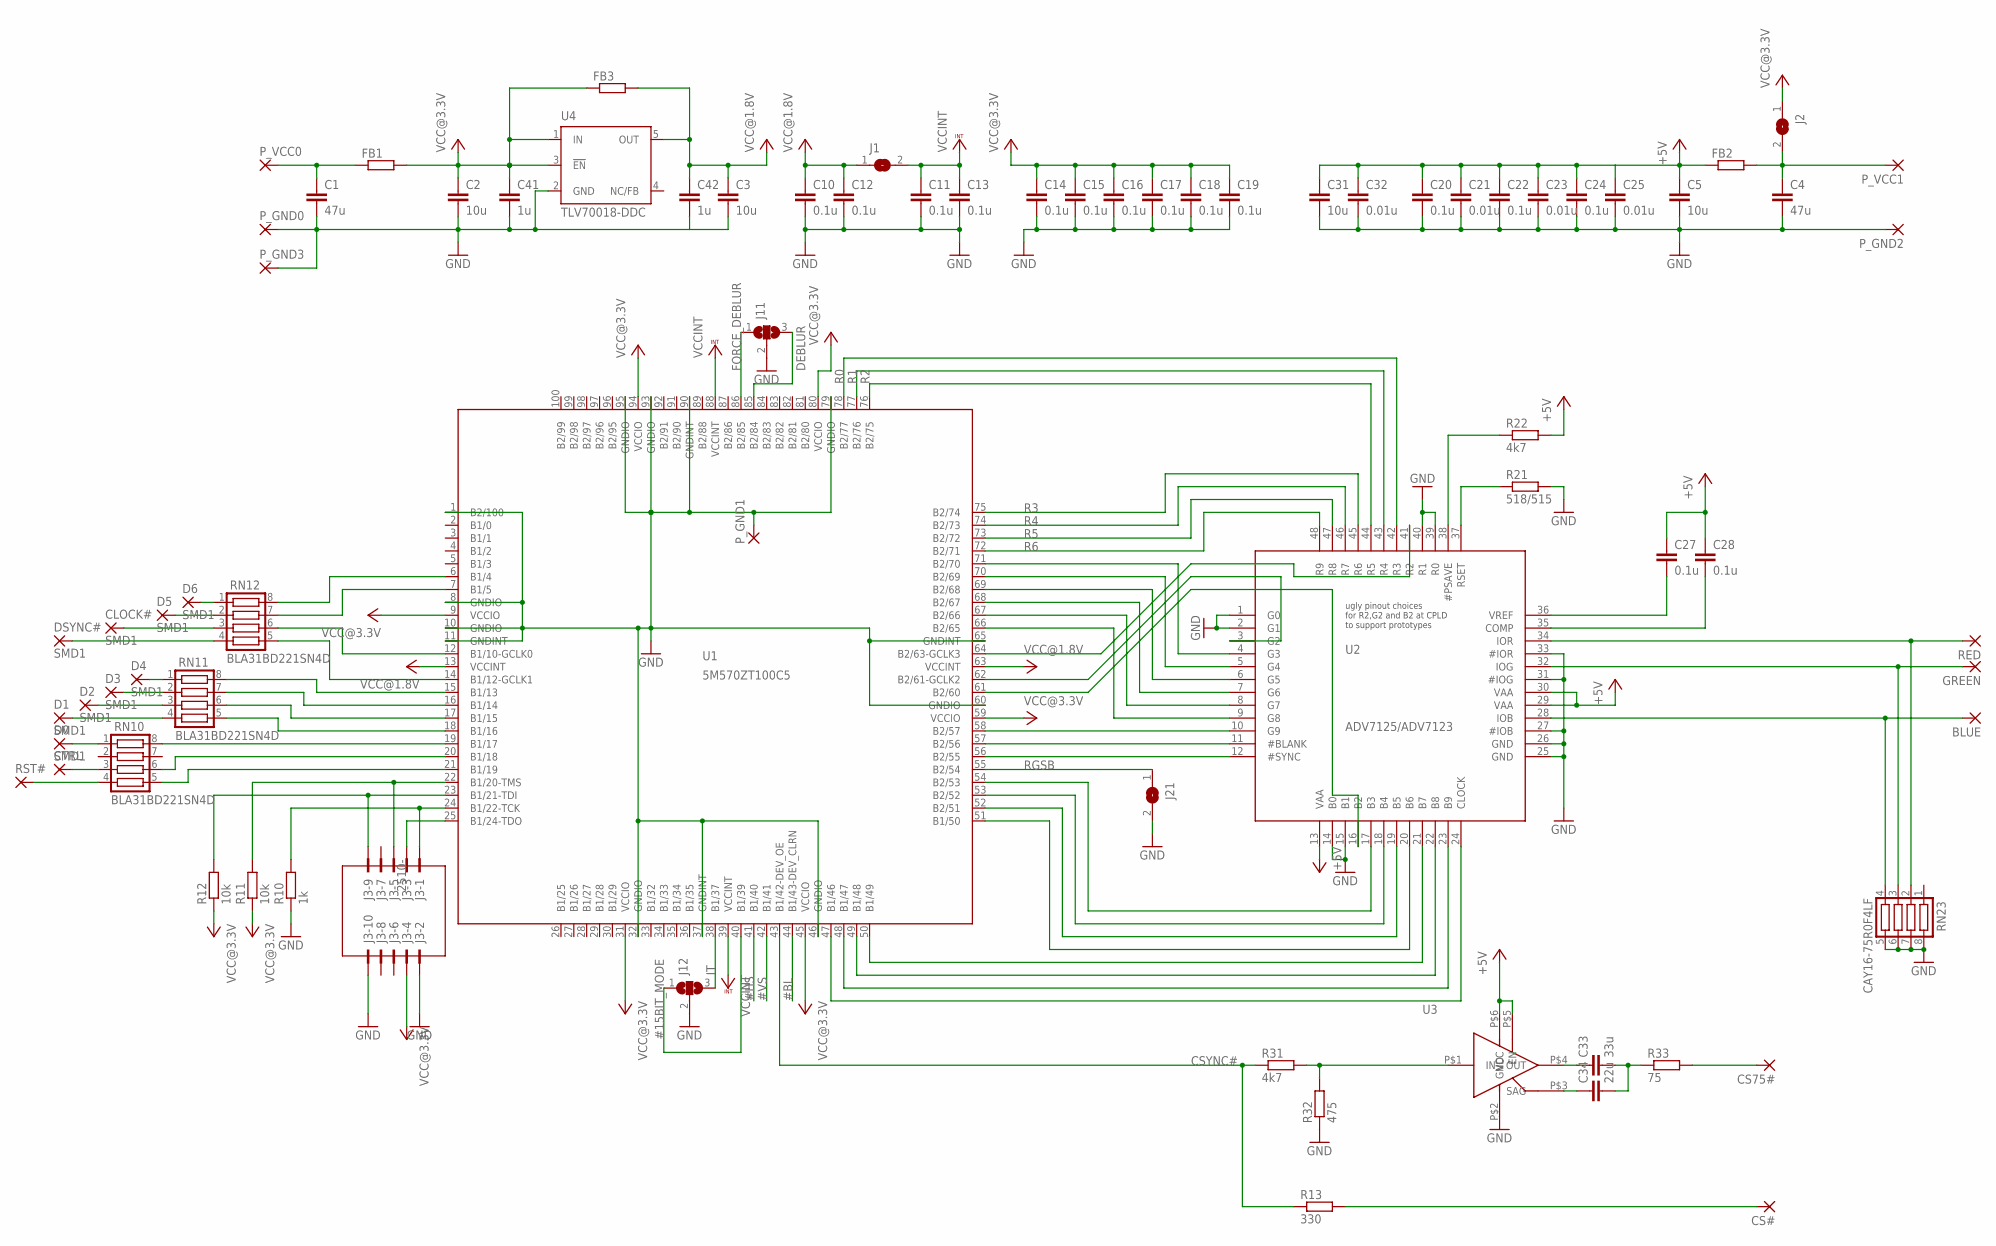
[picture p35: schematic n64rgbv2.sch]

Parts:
BLUE: SMD2; SMD1,27-2,54
C1, C4: 47u; C0805
C2, C3, C5, C31: 10u; C0805
C10, C11, C12, C13, C14, C15, C16, C17, C18, C19, C20, C22, C24, C27, C28: 0.1u; C0603
C21, C23, C25, C32: 0.01u; C0603
C33: 33u; C1210
C34: 22u; C1206
C41, C42: 1u; C0603
CLOCK#: SMD1; SMD0,8-1,6
CS75#: SMD2; SMD1,27-2,54
CS#: SMD2; SMD1,27-2,54
CTRL: SMD2; SMD1,27-2,54
D0, D1, D2, D3, D4, D5, D6: SMD1; SMD0,8-1,6
DSYNC#: SMD1; SMD0,8-1,6
FB1, FB2, FB3: R-EU_R0603; R0603
GREEN: SMD2; SMD1,27-2,54
J1, J2, J21: SJ
J3: 2510-; PAK100/2500-10
J11, J12: SJ2W; SJ_2
P_GND0, P_GND1, P_GND2, P_GND3: SMD2; SMD1,27-2,54
P_VCC0, P_VCC1: SMD2; SMD1,27-2,54
R10: 1k; R0603
R11, R12: 10k; R0603
R13: 330; R0603
R21: 518/515; R0603
R22, R31: 4k7; R0603
R32: 475; R0603
R33: 75; R0603
RED: SMD2; SMD1,27-2,54
RN10, RN11, RN12: BLA31BD221SN4D; CTS742C083
RN23: CAY16-75R0F4LF; CTS742C083
RST#: SMD2; SMD1,27-2,54
U1: 5M570ZT100C5; TQFP100
U2: ADV7125/ADV7123; LQFP48
U3: TSH122ICT; SC70
U4: TLV70018-DDC; SOT23-DBV

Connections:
#15BIT_MODE: J12.1, U1.40 (B1/39)
#BL: U1.44 (B1/43-DEV_CLRN)
#HS: U1.41 (B1/40)
#VS: U1.42 (B1/41)
+5V: C5.1, C20.1, C21.1, C22.1, C23.1, C24.1, C25.1, C27.1, C28.1, C31.1, C32.1, FB2.1, R22.2, U2.13 (VAA), U2.29 (VAA), U2.30 (VAA), U3.P$5 (EN), U3.P$6 (VCC)
BLUE: BLUE.1, RN23.4, U2.28 (IOB)
CSYNC#: R13.1, R31.1, U1.43 (B1/42-DEV_OE)
DEBLUR: J11.3, U1.85 (B2/84)
FORCE_DEBLUR: J11.1, U1.86 (B2/85)
GND: C1.2, C2.2, C3.2, C4.2, C5.2, C10.2, C11.2, C12.2, C13.2, C14.2, C15.2, C16.2, C17.2, C18.2, C19.2, C20.2, C21.2, C22.2, C23.2, C24.2, C25.2, C31.2, C32.2, C41.2, C42.2, J3.2, J3.10, J11.2, J12.2, J21.2, P_GND0.1, P_GND1.1, P_GND2.1, P_GND3.1, R10.1, R21.2, R32.1, RN23.5, RN23.6, RN23.7, RN23.8, U1.1 (B2/100), U1.8 (GNDIO), U1.10 (GNDIO), U1.11 (GNDINT), U1.32 (GNDIO), U1.37 (GNDINT), U1.46 (GNDIO), U1.60 (GNDIO), U1.65 (GNDINT), U1.79 (GNDIO), U1.90 (GNDINT), U1.93 (GNDIO), U1.95 (GNDIO), U2.1 (G0), U2.2 (G1), U2.14 (B0), U2.15 (B1), U2.25 (GND), U2.26 (GND), U2.27 (#IOB), U2.31 (#IOG), U2.33 (#IOR), U2.39 (R0), U2.40 (R1), U3.P$2 (GND), U4.2 (GND)
GREEN: GREEN.1, RN23.3, U2.32 (IOG)
IT: J12.3, U1.38 (B1/37)
unnamed: D6.P$1, RN12.1
unnamed: D5.P$1, RN12.2
unnamed: DSYNC#.P$1, RN12.4
unnamed: CLOCK#.P$1, RN12.3
unnamed: RN10.4, RST#.1
unnamed: CTRL.1, RN10.3
unnamed: D0.P$1, RN10.1
unnamed: RN10.8, U1.19 (B1/17)
unnamed: RN10.6, U1.20 (B1/18)
unnamed: RN10.5, U1.21 (B1/19)
unnamed: RN11.5, U1.18 (B1/16)
unnamed: RN11.6, U1.17 (B1/15)
unnamed: CS#.1, R13.2
unnamed: RN11.7, U1.16 (B1/14)
unnamed: RN11.8, U1.15 (B1/13)
unnamed: D1.P$1, RN11.4
unnamed: D2.P$1, RN11.3
unnamed: D3.P$1, RN11.2
unnamed: D4.P$1, RN11.1
unnamed: RN12.7, U1.7 (B1/5)
unnamed: RN12.8, U1.6 (B1/4)
unnamed: RN12.5, U1.14 (B1/12-GCLK1)
unnamed: RN12.6, U1.12 (B1/10-GCLK0)
unnamed: U1.71 (B2/70), U2.4 (G3)
unnamed: U1.64 (B2/63-GCLK3), U2.41 (R2)
unnamed: U1.70 (B2/69), U2.5 (G4)
unnamed: U1.69 (B2/68), U2.6 (G5)
unnamed: U1.68 (B2/67), U2.7 (G6)
unnamed: U1.67 (B2/66), U2.8 (G7)
unnamed: U1.66 (B2/65), U2.9 (G8)
unnamed: U1.58 (B2/57), U2.10 (G9)
unnamed: U1.56 (B2/55), U2.12 (#SYNC)
unnamed: U1.47 (B1/46), U2.24 (CLOCK)
unnamed: U1.48 (B1/47), U2.23 (B9)
unnamed: U1.49 (B1/48), U2.22 (B8)
unnamed: U1.50 (B1/49), U2.21 (B7)
unnamed: U1.51 (B1/50), U2.20 (B6)
unnamed: U1.52 (B2/51), U2.19 (B5)
unnamed: U1.53 (B2/52), U2.18 (B4)
unnamed: U1.54 (B2/53), U2.17 (B3)
unnamed: U1.62 (B2/61-GCLK2), U2.3 (G2)
unnamed: U1.57 (B2/56), U2.11 (#BLANK)
unnamed: U1.61 (B2/60), U2.16 (B2)
unnamed: C4.1, FB2.2, J2.2, P_VCC1.1
unnamed: C1.1, FB1.1, P_VCC0.1
unnamed: C33.2, C34.2, R33.1
unnamed: CS75#.1, R33.2
unnamed: C33.1, U3.P$4 (OUT)
unnamed: C34.1, U3.P$3 (SAG)
unnamed: R21.1, U2.37 (RSET)
unnamed: R22.1, U2.38 (#PSAVE)
unnamed: C28.2, U2.35 (COMP)
unnamed: R31.2, R32.2, U3.P$1 (IN)
unnamed: C27.2, U2.36 (VREF)
R0: U1.78 (B2/77), U2.42 (R3)
R1: U1.77 (B2/76), U2.43 (R4)
R2: U1.76 (B2/75), U2.44 (R5)
R3: U1.75 (B2/74), U2.45 (R6)
R4: U1.74 (B2/73), U2.46 (R7)
R5: U1.73 (B2/72), U2.47 (R8)
R6: U1.72 (B2/71), U2.48 (R9)
RED: RED.1, RN23.2, U2.34 (IOR)
RGSB: J21.1, U1.55 (B2/54)
TCK: J3.1, R10.2, U1.24 (B1/22-TCK)
TDI: J3.9, R12.2, U1.23 (B1/21-TDI)
TDO: J3.3, U1.25 (B1/24-TDO)
TMS: J3.5, R11.2, U1.22 (B1/20-TMS)
VCC@1.8V: C3.1, C10.1, C12.1, C42.1, FB3.2, J1.1, U1.13 (VCCINT), U1.63 (VCCINT), U4.5 (OUT)
VCC@3.3V: C2.1, C14.1, C15.1, C16.1, C17.1, C18.1, C19.1, C41.1, FB1.2, FB3.1, J2.1, J3.4, R11.1, R12.1, U1.9 (VCCIO), U1.31 (VCCIO), U1.45 (VCCIO), U1.59 (VCCIO), U1.80 (VCCIO), U1.94 (VCCIO), U4.1 (IN), U4.3 (!EN)
VCCINT: C11.1, C13.1, J1.2, U1.39 (VCCINT), U1.88 (VCCINT)

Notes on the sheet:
ugly pinout choices for R2,G2 and B2 at CPLD to support prototypes

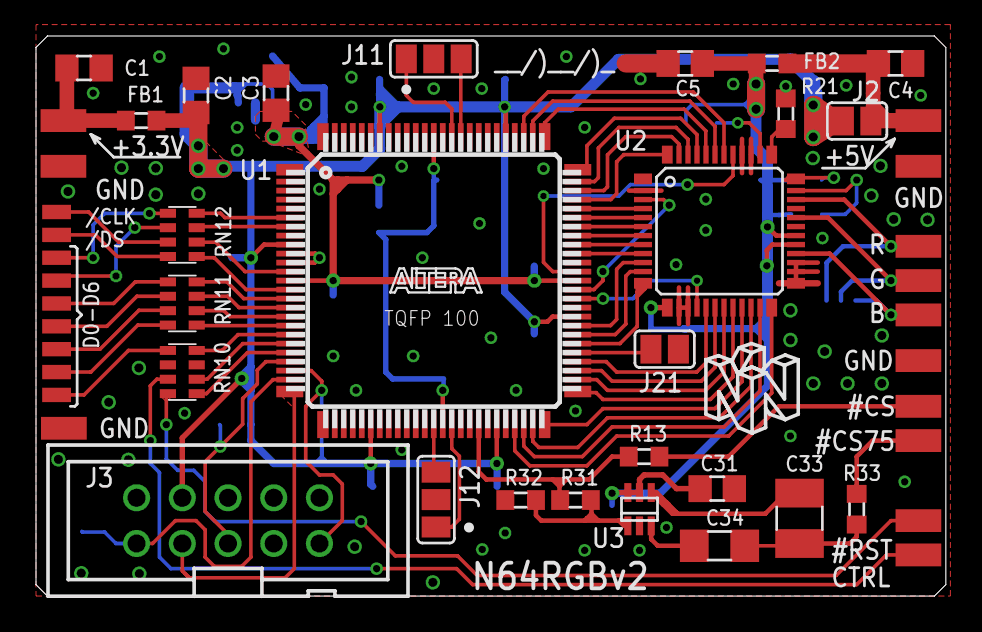
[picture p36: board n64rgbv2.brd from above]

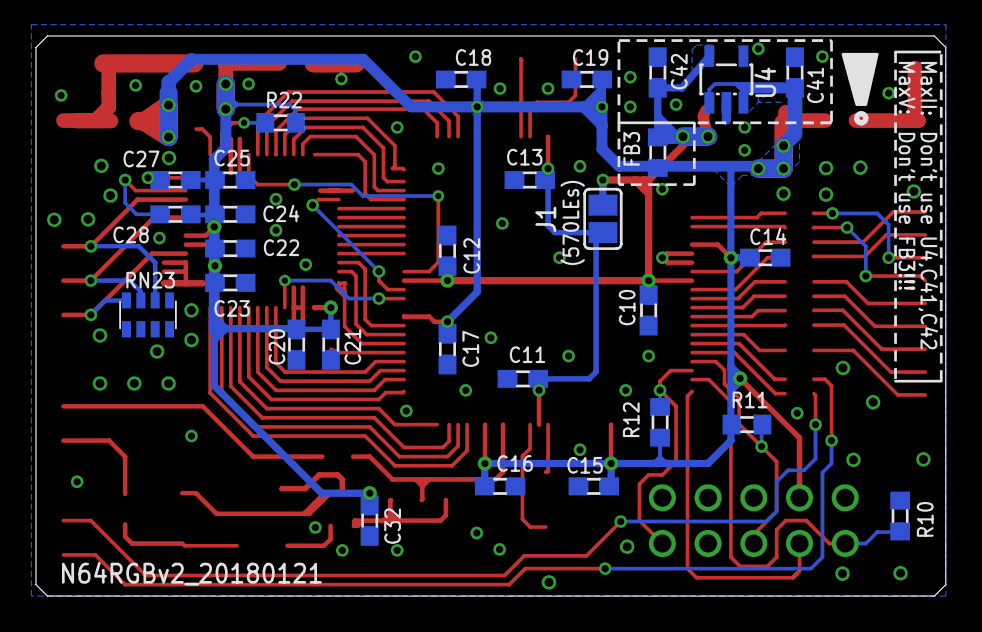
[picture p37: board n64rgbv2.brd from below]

Board: 2 copper layers, 50.5 x 31.1 mm, 77 parts (29 on the bottom side), 79 nets.

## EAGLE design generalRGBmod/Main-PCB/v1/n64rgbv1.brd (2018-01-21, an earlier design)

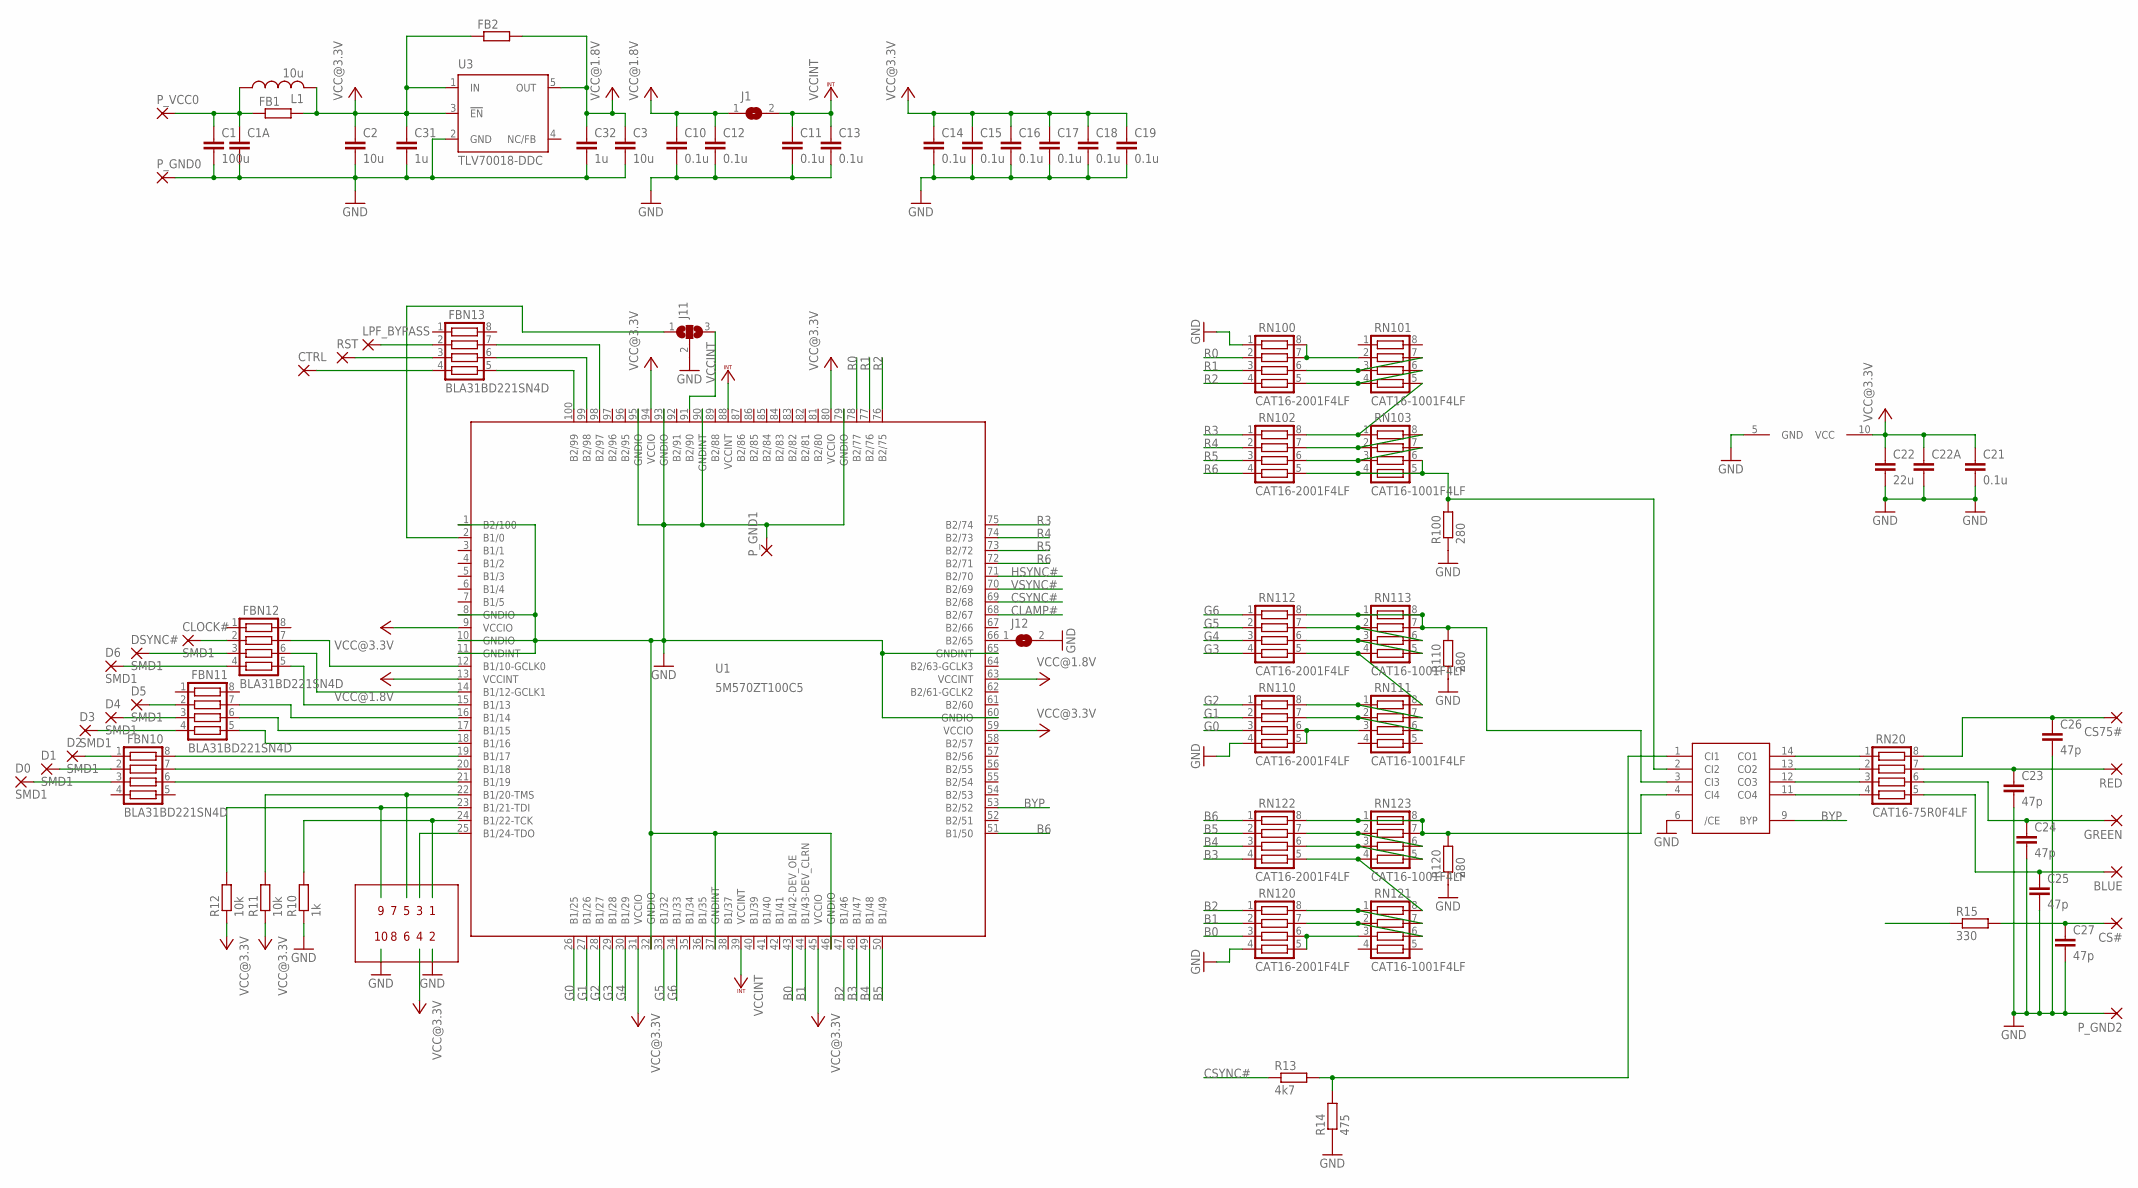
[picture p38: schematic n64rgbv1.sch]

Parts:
BLUE: SMD2; SMD1,27-2,54
C1: 100u; C1206K
C1A, C22A: C-EUC0805; C0805
C2, C3: 10u; C0805
C10, C11, C12, C13, C14, C15, C16, C17, C18, C19, C21: 0.1u; C0603
C22: 22u; C1206K
C23, C24, C25, C26, C27: 47p; C0603
C31, C32: 1u; C0603
CLOCK#: SMD1; SMD0,8-1,6
CS75#: SMD2; SMD1,27-2,54
CS#: SMD2; SMD1,27-2,54
CTRL: SMD2; SMD1,27-2,54
D0, D1, D2, D3, D4, D5, D6: SMD1; SMD0,8-1,6
DSYNC#: SMD1; SMD0,8-1,6
FB1, FB2: R-EU_R0603; R0603
FBN10, FBN11, FBN12, FBN13: BLA31BD221SN4D; CTS742C083
GREEN: SMD2; SMD1,27-2,54
J1, J12: SJ
J11: SJ2W; SJ_2
L1: 10u; L3230M
LPF_BYPASS: SMD2; SMD1,27-2,54
P_GND0, P_GND1, P_GND2: SMD2; SMD1,27-2,54
P_VCC0: SMD2; SMD1,27-2,54
R10: 1k; R0603
R11, R12: 10k; R0603
R13: 4k7; R0603
R14: 475; R0603
R15: 330; R0603
R100, R110, R120: 280; R0603
RED: SMD2; SMD1,27-2,54
RN20: CAT16-75R0F4LF; CTS742C083
RN100, RN102, RN110, RN112, RN120, RN122: CAT16-2001F4LF; CTS742C083
RN101, RN103, RN111, RN113, RN121, RN123: CAT16-1001F4LF; CTS742C083
RST: SMD2; SMD1,27-2,54
U1: 5M570ZT100C5; TQFP100
U2: THS7374
U3: TLV70018-DDC; SOT23-DBV

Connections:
B0: RN120.3, U1.43 (B1/42-DEV_OE)
B1: RN120.2, U1.44 (B1/43-DEV_CLRN)
B2: RN120.1, U1.47 (B1/46)
B3: RN122.4, U1.48 (B1/47)
B4: RN122.3, U1.49 (B1/48)
B5: RN122.2, U1.50 (B1/49)
B6: RN122.1, U1.51 (B1/50)
BYP: U1.53 (B2/52), U2.9 (BYP)
CLAMP#: U1.68 (B2/67)
CSYNC#: R13.1, R15.1, U1.69 (B2/68)
G0: RN110.3, U1.26 (B1/25)
G1: RN110.2, U1.27 (B1/26)
G2: RN110.1, U1.28 (B1/27)
G3: RN112.4, U1.29 (B1/28)
G4: RN112.3, U1.30 (B1/29)
G5: RN112.2, U1.33 (B1/32)
G6: RN112.1, U1.34 (B1/33)
GND: C1.2, C1A.2, C2.2, C3.2, C10.2, C11.2, C12.2, C13.2, C14.2, C15.2, C16.2, C17.2, C18.2, C19.2, C21.2, C22.2, C22A.2, C23.2, C24.2, C25.2, C26.2, C27.2, C31.2, C32.2, J11.2, J12.2, P_GND0.1, P_GND1.1, P_GND2.1, R10.1, R14.1, R100.1, R110.1, R120.1, RN100.1, RN110.4, RN120.4, U1.1 (B2/100), U1.8 (GNDIO), U1.10 (GNDIO), U1.11 (GNDINT), U1.32 (GNDIO), U1.37 (GNDINT), U1.46 (GNDIO), U1.60 (GNDIO), U1.65 (GNDINT), U1.79 (GNDIO), U1.90 (GNDINT), U1.93 (GNDIO), U1.95 (GNDIO), U2.5 (GND), U2.6 (/CE), U3.2 (GND)
HSYNC#: U1.71 (B2/70)
unnamed: R13.2, R14.2, U2.1 (CI1)
unnamed: C23.1, RED.1, RN20.7
unnamed: RN20.1, U2.14 (CO1)
unnamed: RN20.2, U2.13 (CO2)
unnamed: RN20.3, U2.12 (CO3)
unnamed: RN20.4, U2.11 (CO4)
unnamed: CTRL.1, FBN13.4
unnamed: FBN13.3, RST.1
unnamed: FBN13.2, LPF_BYPASS.1
unnamed: C24.1, GREEN.1, RN20.6
unnamed: BLUE.1, C25.1, RN20.5
unnamed: C26.1, CS75#.1, RN20.8
unnamed: C27.1, CS#.1, R15.2
unnamed: FBN13.5, U1.100 (B2/99)
unnamed: D1.P$1, FBN10.2
unnamed: D0.P$1, FBN10.3
unnamed: D2.P$1, FBN10.1
unnamed: FBN10.6, U1.21 (B1/19)
unnamed: FBN10.7, U1.20 (B1/18)
unnamed: FBN10.8, U1.19 (B1/17)
unnamed: D3.P$1, FBN11.4
unnamed: D4.P$1, FBN11.3
unnamed: D5.P$1, FBN11.2
unnamed: D6.P$1, FBN12.4
unnamed: RN110.5, RN110.6, RN111.3
unnamed: RN110.7, RN111.2, RN111.6
unnamed: RN110.8, RN111.1, RN111.7
unnamed: RN111.8, RN112.5, RN113.4
unnamed: RN112.6, RN113.3, RN113.5
unnamed: RN112.7, RN113.2, RN113.6
unnamed: R120.2, RN122.8, RN123.1, RN123.7, RN123.8, U2.4 (CI4)
unnamed: RN120.5, RN120.6, RN121.3
unnamed: RN120.7, RN121.2, RN121.6
unnamed: RN120.8, RN121.1, RN121.7
unnamed: RN121.8, RN122.5, RN123.4
unnamed: DSYNC#.P$1, FBN12.3
unnamed: RN122.6, RN123.3, RN123.5
unnamed: RN122.7, RN123.2, RN123.6
unnamed: CLOCK#.P$1, FBN12.2
unnamed: FBN11.5, U1.18 (B1/16)
unnamed: FBN11.6, U1.17 (B1/15)
unnamed: FBN11.7, U1.16 (B1/14)
unnamed: FBN12.5, U1.15 (B1/13)
unnamed: FBN12.6, U1.14 (B1/12-GCLK1)
unnamed: FBN12.7, U1.12 (B1/10-GCLK0)
unnamed: FBN13.6, U1.99 (B2/98)
unnamed: FBN13.7, U1.98 (B2/97)
unnamed: R100.2, RN102.5, RN103.4, RN103.5, RN103.6, U2.2 (CI2)
unnamed: J12.1, U1.66 (B2/65)
unnamed: J11.3, U1.91 (B2/90)
unnamed: J11.1, U1.2 (B1/0)
unnamed: C1.1, C1A.1, FB1.1, L1.1, P_VCC0.1
unnamed: R110.2, RN112.8, RN113.1, RN113.7, RN113.8, U2.3 (CI3)
unnamed: RN100.7, RN100.8, RN101.2
unnamed: RN100.6, RN101.3, RN101.7
unnamed: RN100.5, RN101.4, RN101.6
unnamed: RN101.5, RN102.8, RN103.1
unnamed: RN102.7, RN103.2, RN103.8
unnamed: RN102.6, RN103.3, RN103.7
R0: RN100.2, U1.78 (B2/77)
R1: RN100.3, U1.77 (B2/76)
R2: RN100.4, U1.76 (B2/75)
R3: RN102.1, U1.75 (B2/74)
R4: RN102.2, U1.74 (B2/73)
R5: RN102.3, U1.73 (B2/72)
R6: RN102.4, U1.72 (B2/71)
TCK: R10.2, U1.24 (B1/22-TCK)
TDI: R12.2, U1.23 (B1/21-TDI)
TDO: U1.25 (B1/24-TDO)
TMS: R11.2, U1.22 (B1/20-TMS)
VCC@1.8V: C3.1, C10.1, C12.1, C32.1, FB2.2, J1.1, U1.13 (VCCINT), U1.63 (VCCINT), U3.5 (OUT)
VCC@3.3V: C2.1, C14.1, C15.1, C16.1, C17.1, C18.1, C19.1, C21.1, C22.1, C22A.1, C31.1, FB1.2, FB2.1, L1.2, R11.1, R12.1, U1.9 (VCCIO), U1.31 (VCCIO), U1.45 (VCCIO), U1.59 (VCCIO), U1.80 (VCCIO), U1.94 (VCCIO), U2.10 (VCC), U3.1 (IN), U3.3 (!EN)
VCCINT: C11.1, C13.1, J1.2, U1.39 (VCCINT), U1.88 (VCCINT)
VSYNC#: U1.70 (B2/69)

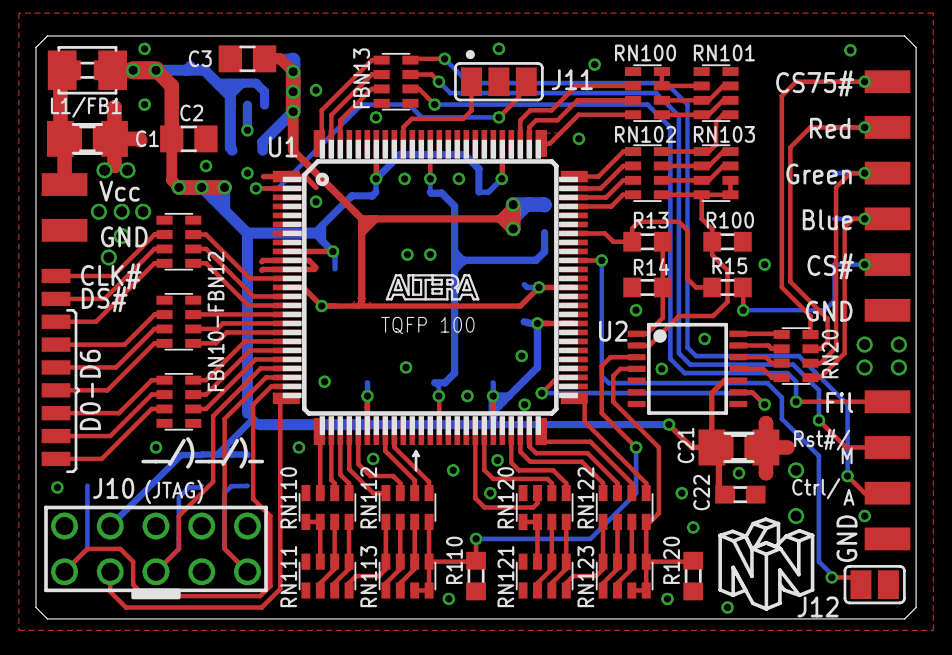
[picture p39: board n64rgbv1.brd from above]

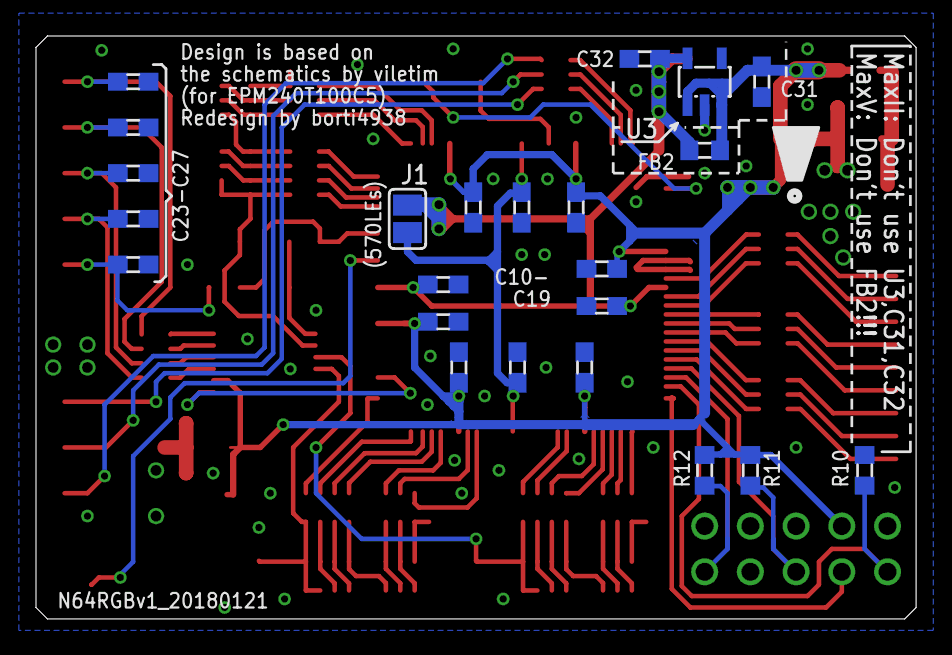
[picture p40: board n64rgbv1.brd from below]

Board: 2 copper layers, 48.9 x 32.4 mm, 80 parts (23 on the bottom side), 89 nets.

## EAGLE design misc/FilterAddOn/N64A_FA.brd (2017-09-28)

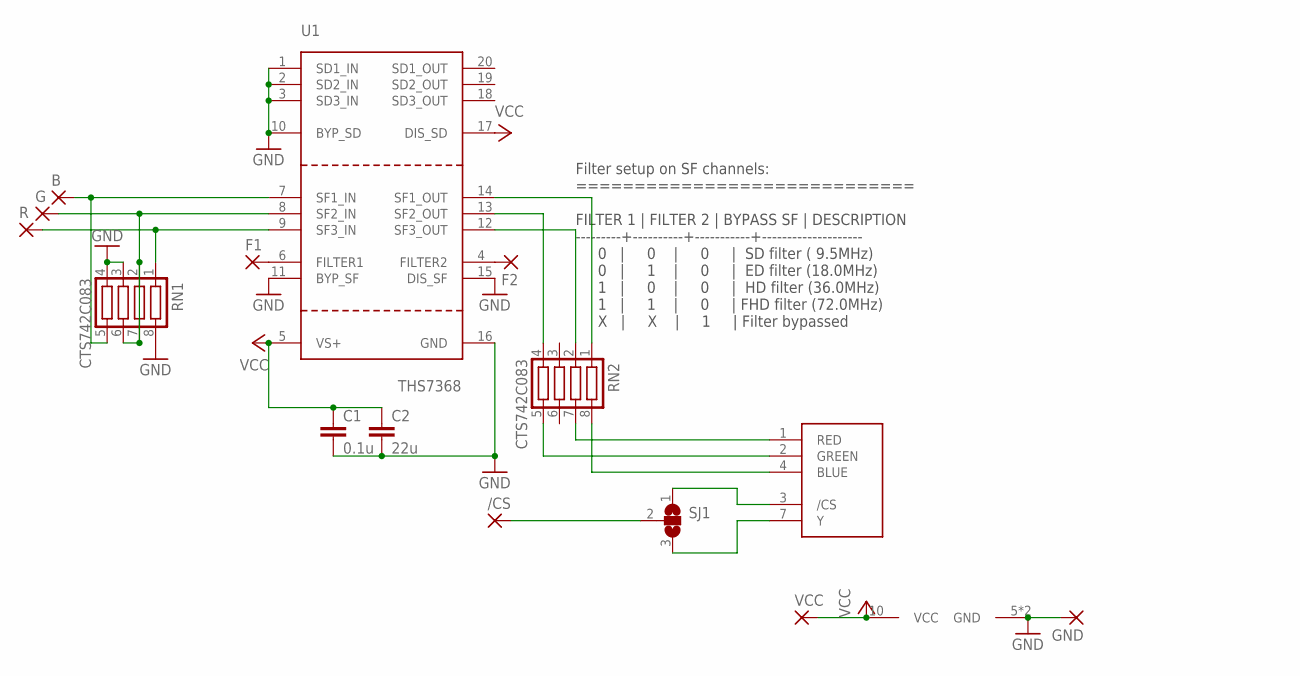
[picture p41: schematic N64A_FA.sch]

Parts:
/CS: SMD2; SMD1,27-2,54
B: SMD2; SMD1,27-2,54
C1: 0.1u; C0603
C2: 22u; C1206
F1, F2: SMD1; SMD0,8-1,6
G: SMD2; SMD1,27-2,54
GND: SMD2; SMD1,27-2,54
R: SMD2; SMD1,27-2,54
RN1, RN2: CTS742C083
SJ1: SJ2W; SJ_2
U1: THS7368
U$1: SNES_MULTIAV_RGBSY
VCC: SMD2; SMD1,27-2,54

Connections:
GND: C1.2, C2.2, GND.1, RN1.3, RN1.4, RN1.8, U1.1 (SD1_IN), U1.2 (SD2_IN), U1.3 (SD3_IN), U1.10 (BYP_SD), U1.11 (BYP_SF), U1.15 (DIS_SF), U1.16 (GND), U$1.5 (GND), U$1.6 (GND)
unnamed: RN2.7, U$1.1 (RED)
unnamed: RN2.8, U$1.4 (BLUE)
unnamed: RN2.5, U$1.2 (GREEN)
unnamed: RN2.4, U1.13 (SF2_OUT)
unnamed: RN2.1, U1.14 (SF1_OUT)
unnamed: RN2.2, U1.12 (SF3_OUT)
unnamed: SJ1.1, U$1.3 (/CS)
unnamed: F1.P$1, U1.6 (FILTER1)
unnamed: R.1, RN1.1, U1.9 (SF3_IN)
unnamed: G.1, RN1.2, RN1.6, RN1.7, U1.8 (SF2_IN)
unnamed: F2.P$1, U1.4 (FILTER2)
unnamed: /CS.1, SJ1.2
unnamed: B.1, RN1.5, U1.7 (SF1_IN)
unnamed: SJ1.3, U$1.7 (Y)
VCC: C1.1, C2.1, U1.5 (VS+), U1.17 (DIS_SD), U$1.10 (VCC), VCC.1

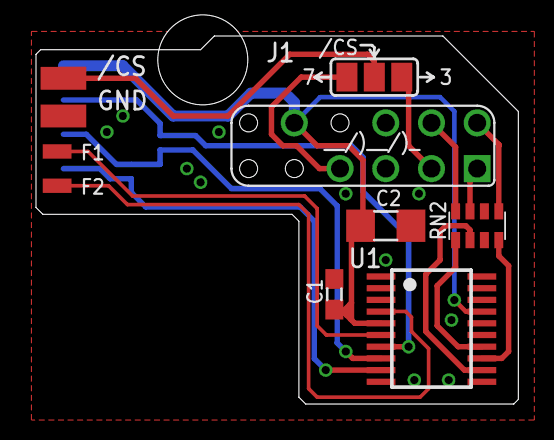
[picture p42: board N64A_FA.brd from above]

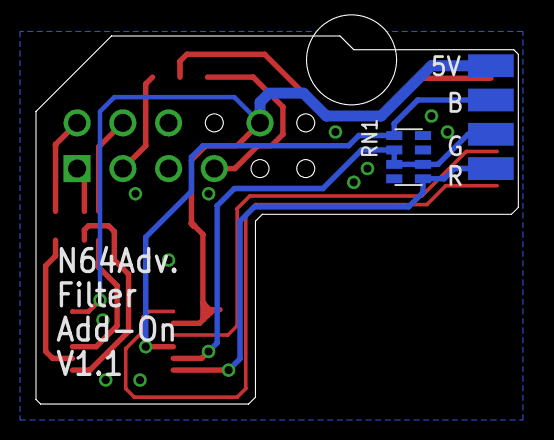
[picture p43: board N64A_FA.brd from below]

Board: 2 copper layers, 26.8 x 20.4 mm, 15 parts (5 on the bottom side), 16 nets.

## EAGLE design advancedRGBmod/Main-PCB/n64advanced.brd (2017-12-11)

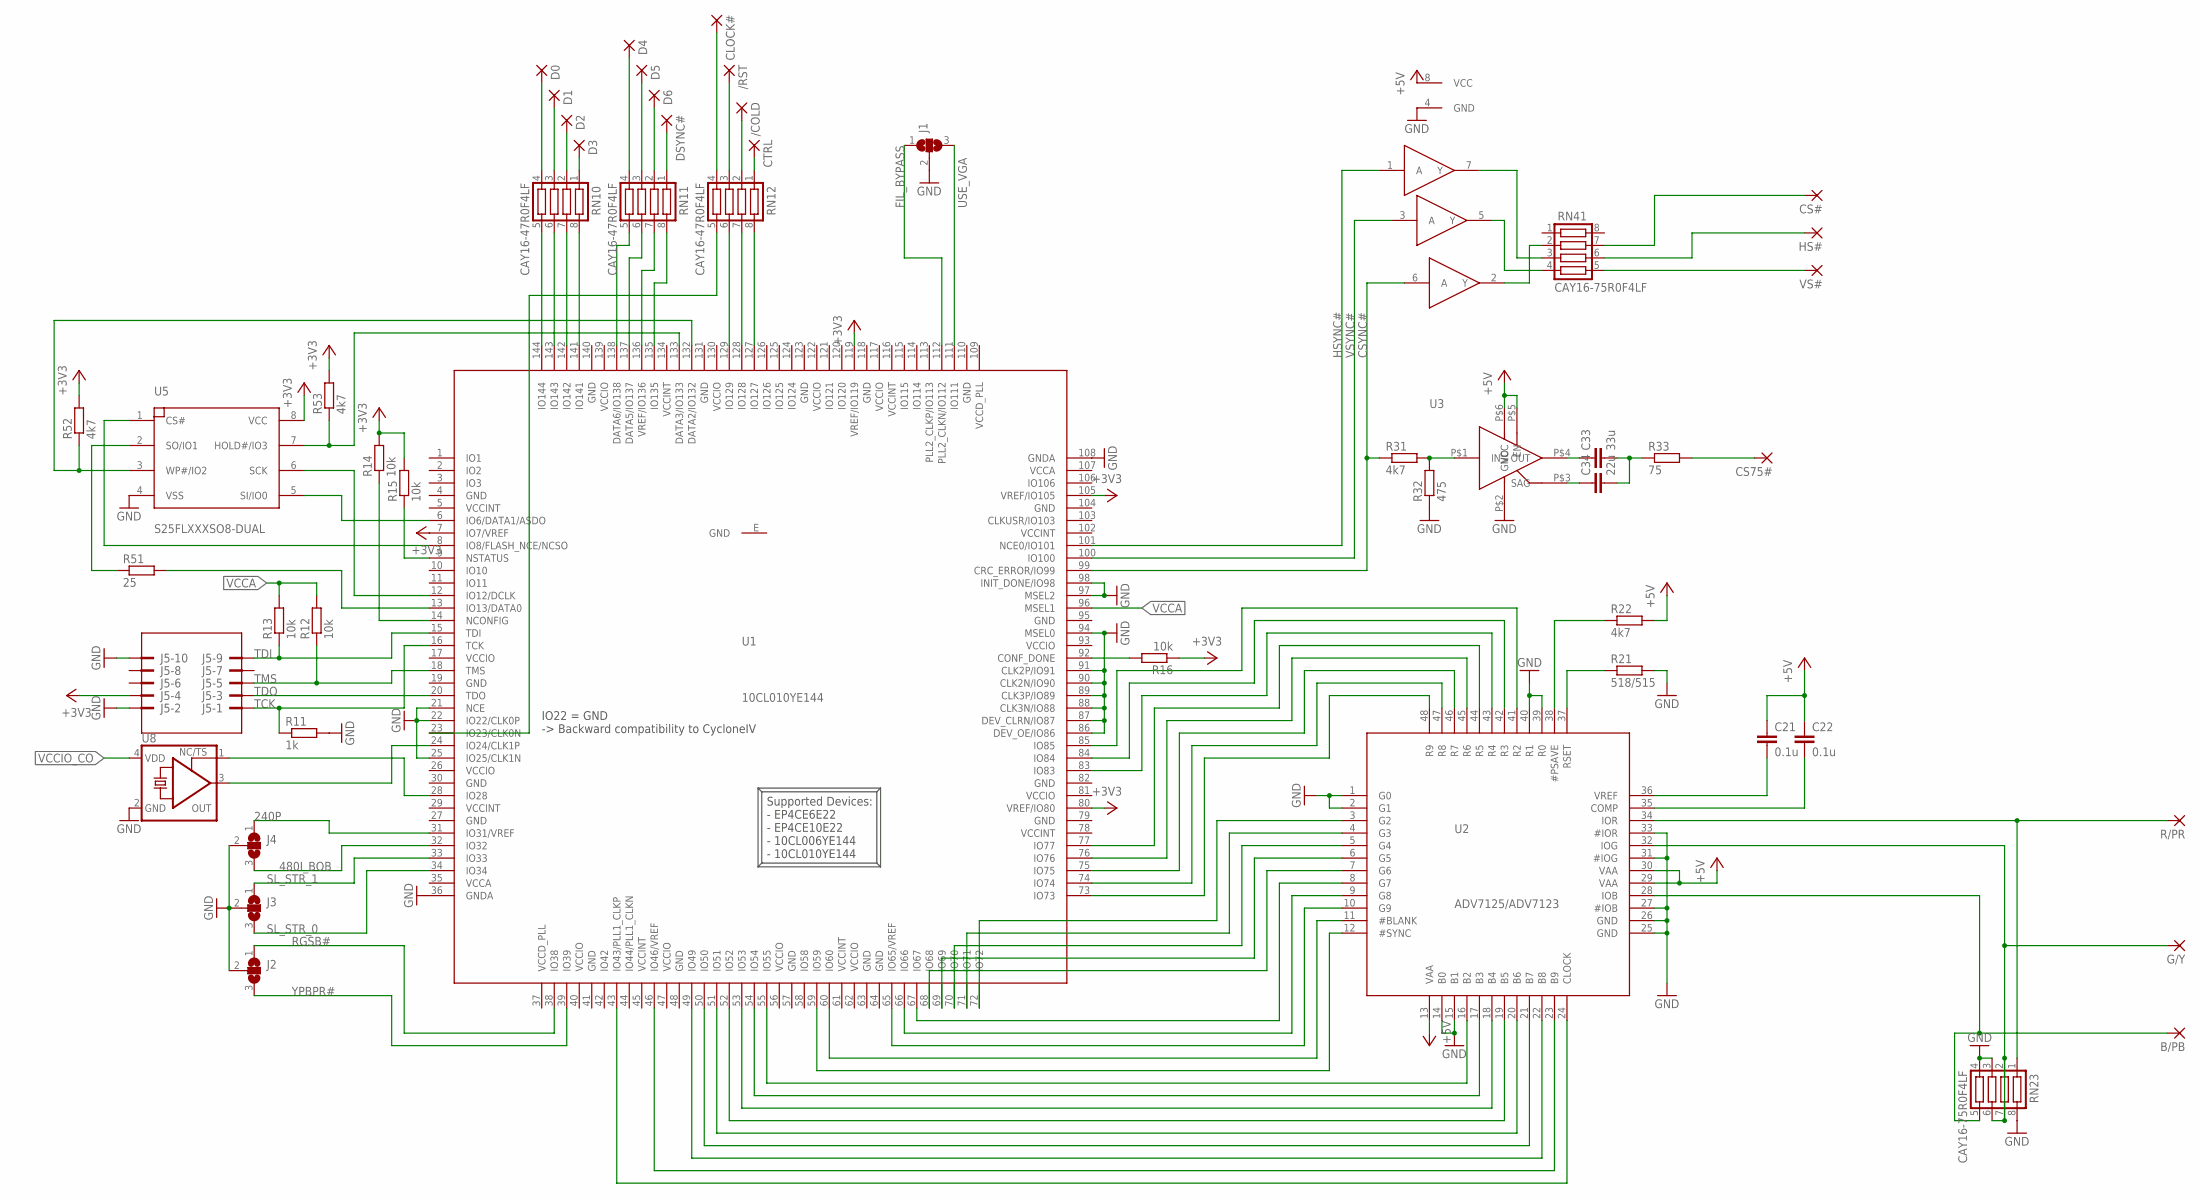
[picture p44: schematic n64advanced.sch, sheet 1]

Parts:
/COLD: SMD2; SMD1,27-2,54
/RST: SMD2; SMD1,27-2,54
B/PB: SMD2; SMD1,27-2,54
C21, C22: 0.1u; C0603
C33: 33u; C1210
C34: 22u; C1206
CLOCK#: SMD1; SMD0,8-1,6
CS75#: SMD2; SMD1,27-2,54
CS#: SMD2; SMD1,27-2,54
CTRL: SMD2; SMD1,27-2,54
D0, D1, D2, D3, D4, D5, D6: SMD1; SMD0,8-1,6
DSYNC#: SMD1; SMD0,8-1,6
G/Y: SMD2; SMD1,27-2,54
HS#: SMD2; SMD1,27-2,54
J1, J2, J3, J4: SJ2W; SJ_2
J5: 2510-; PAK100/2500-10
R11: 1k; R0603
R12, R13, R14, R15, R16: 10k; R0603
R21: 518/515; R0603
R22, R31, R52, R53: 4k7; R0603
R32: 475; R0603
R33: 75; R0603
R51: 25; R0603
R/PR: SMD2; SMD1,27-2,54
RN10, RN11, RN12: CAY16-47R0F4LF; CTS742C083
RN23, RN41: CAY16-75R0F4LF; CTS742C083
U1: 10CL010YE144; EQFP144_2
U2: ADV7125/ADV7123; LQFP48
U3: TSH122ICT; SC70
U4: 74LVC3G17; 74LVC3G34
U5: S25FLXXXSO8-DUAL; SO8-DUAL
U8: KXO-PXO/XO-V96; 3.2X2.5_KXO-V96
VS#: SMD2; SMD1,27-2,54

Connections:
240P: J4.1, U1.31 (IO31/VREF)
480I_BOB: J4.3, U1.32 (IO32)
+5V: C21.1, C22.1, R22.2, U2.13 (VAA), U2.29 (VAA), U2.30 (VAA), U3.P$5 (EN), U3.P$6 (VCC), U4.8 (VCC); also elsewhere on the board
BLUE: B/PB.1, RN23.5, U2.28 (IOB)
CSYNC47#: CS#.1, RN41.7
CSYNC#: R31.1, U1.99 (CRC_ERROR/IO99), U4.6 (A)
FIL_BYPASS: J1.1, U1.112 (PLL2_CLKN/IO112)
GND: J1.2, J2.2, J3.2, J4.2, J5.2, J5.10, R11.2, R21.2, R32.1, RN23.3, RN23.4, RN23.8, U1.4 (GND), U1.19 (GND), U1.21 (NCE), U1.22 (IO22/CLK0P), U1.25 (IO25/CLK1N), U1.27 (GND), U1.30 (GND), U1.36 (GNDA), U1.41 (GND), U1.48 (GND), U1.57 (GND), U1.63 (GND), U1.64 (GND), U1.79 (GND), U1.82 (GND), U1.86 (DEV_OE/IO86), U1.87 (DEV_CLRN/IO87), U1.88 (CLK3N/IO88), U1.89 (CLK3P/IO89), U1.90 (CLK2N/IO90), U1.91 (CLK2P/IO91), U1.94 (MSEL0), U1.95 (GND), U1.97 (MSEL2), U1.98 (INIT_DONE/IO98), U1.104 (GND), U1.108 (GNDA), U1.110 (GND), U1.118 (GND), U1.123 (GND), U1.131 (GND), U1.140 (GND), U1.E (GND), U2.1 (G0), U2.2 (G1), U2.14 (B0), U2.15 (B1), U2.25 (GND), U2.26 (GND), U2.27 (#IOB), U2.31 (#IOG), U2.33 (#IOR), U2.39 (R0), U2.40 (R1), U3.P$2 (GND), U4.4 (GND), U5.4 (VSS), U8.2 (GND); also elsewhere on the board
GREEN: G/Y.1, RN23.2, RN23.6, RN23.7, U2.32 (IOG)
HSYNC47#: HS#.1, RN41.6
HSYNC#: U1.101 (NCE0/IO101), U4.1 (A)
unnamed: R31.2, R32.2, U3.P$1 (IN)
unnamed: R21.1, U2.37 (RSET)
unnamed: RN12.5, U1.23 (IO23/CLK0N)
unnamed: U1.43 (IO43/PLL1_CLKP), U2.24 (CLOCK)
unnamed: U1.46 (IO46/VREF), U2.23 (B9)
unnamed: U1.49 (IO49), U2.22 (B8)
unnamed: U1.50 (IO50), U2.21 (B7)
unnamed: R14.1, U1.14 (NCONFIG)
unnamed: U1.51 (IO51), U2.20 (B6)
unnamed: U1.52 (IO52), U2.19 (B5)
unnamed: U1.53 (IO53), U2.18 (B4)
unnamed: U1.54 (IO54), U2.17 (B3)
unnamed: U1.55 (IO55), U2.16 (B2)
unnamed: U1.72 (IO72), U2.3 (G2)
unnamed: C33.1, U3.P$4 (OUT)
unnamed: C34.1, U3.P$3 (SAG)
unnamed: C33.2, C34.2, R33.1
unnamed: U1.71 (IO71), U2.4 (G3)
unnamed: U1.70 (IO70), U2.5 (G4)
unnamed: U1.69 (IO69), U2.6 (G5)
unnamed: CS75#.1, R33.2
unnamed: R22.1, U2.38 (#PSAVE)
unnamed: C22.2, U2.35 (COMP)
unnamed: C21.2, U2.36 (VREF)
unnamed: R52.1, U1.132 (DATA2/IO132), U5.3 (WP#/IO2)
unnamed: RN41.2, U4.2 (Y)
unnamed: U1.68 (IO68), U2.7 (G6)
unnamed: U1.67 (IO67), U2.8 (G7)
unnamed: U1.66 (IO66), U2.9 (G8)
unnamed: U1.65 (IO65/VREF), U2.10 (G9)
unnamed: U1.60 (IO60), U2.11 (#BLANK)
unnamed: U1.59 (IO59), U2.12 (#SYNC)
unnamed: U1.85 (IO85), U2.41 (R2)
unnamed: U1.84 (IO84), U2.42 (R3)
unnamed: U1.83 (IO83), U2.43 (R4)
unnamed: U1.77 (IO77), U2.44 (R5)
unnamed: U1.76 (IO76), U2.45 (R6)
unnamed: U1.75 (IO75), U2.46 (R7)
unnamed: U1.74 (IO74), U2.47 (R8)
unnamed: U1.73 (IO73), U2.48 (R9)
unnamed: RN10.5, U1.144 (IO144)
unnamed: RN10.6, U1.143 (IO143)
unnamed: RN10.7, U1.142 (IO142)
unnamed: RN10.8, U1.141 (IO141)
unnamed: R15.1, U1.9 (NSTATUS)
unnamed: RN11.5, U1.138 (DATA6/IO138)
unnamed: RN41.4, U4.5 (Y)
unnamed: RN11.6, U1.137 (DATA5/IO137)
unnamed: RN11.7, U1.136 (VREF/IO136)
unnamed: RN11.8, U1.135 (IO135)
unnamed: R16.2, U1.92 (CONF_DONE)
unnamed: D0.P$1, RN10.4
unnamed: RN12.6, U1.129 (IO129)
unnamed: RN12.7, U1.128 (IO128)
unnamed: RN12.8, U1.127 (IO127)
unnamed: D1.P$1, RN10.3
unnamed: D2.P$1, RN10.2
unnamed: D3.P$1, RN10.1
unnamed: D4.P$1, RN11.4
unnamed: D5.P$1, RN11.3
unnamed: D6.P$1, RN11.2
unnamed: DSYNC#.P$1, RN11.1
unnamed: CLOCK#.P$1, RN12.4
unnamed: CTRL.1, RN12.1
unnamed: /COLD.1, RN12.2
unnamed: RN41.3, U4.7 (Y)
unnamed: R51.1, U5.2 (SO/IO1)
unnamed: /RST.1, RN12.3
unnamed: R51.2, U1.13 (IO13/DATA0)
unnamed: U1.12 (IO12/DCLK), U5.6 (SCK)
unnamed: R53.1, U1.133 (DATA3/IO133), U5.7 (HOLD#/IO3)
unnamed: U1.8 (IO8/FLASH_NCE/NCSO), U5.1 (CS#)
unnamed: U1.6 (IO6/DATA1/ASDO), U5.5 (SI/IO0)
unnamed: U1.24 (IO24/CLK1P), U8.3 (OUT)
unnamed: U1.28 (IO28), U8.1 (TS)
RED: R/PR.1, RN23.1, U2.34 (IOR)
RGSB#: J2.1, U1.38 (IO38)
SL_STR_0: J3.3, U1.34 (IO34)
SL_STR_1: J3.1, U1.33 (IO33)
TCK: J5.1, R11.1, U1.16 (TCK)
TDI: J5.9, R13.1, U1.15 (TDI)
TDO: J5.3, U1.20 (TDO)
TMS: J5.5, R12.1, U1.18 (TMS)
USE_VGA: J1.3, U1.111 (IO111)
VCCA: R12.2, R13.2, U1.35 (VCCA), U1.96 (MSEL1), U1.107 (VCCA); also elsewhere on the board
VCCD_PLL: U1.37 (VCCD_PLL), U1.109 (VCCD_PLL); also elsewhere on the board
VCCINT: U1.5 (VCCINT), U1.29 (VCCINT), U1.45 (VCCINT), U1.61 (VCCINT), U1.78 (VCCINT), U1.102 (VCCINT), U1.116 (VCCINT), U1.134 (VCCINT); also elsewhere on the board
VCCIO: J5.4, R14.2, R15.2, R16.1, R52.2, R53.2, U1.7 (IO7/VREF), U1.17 (VCCIO), U1.26 (VCCIO), U1.40 (VCCIO), U1.47 (VCCIO), U1.56 (VCCIO), U1.62 (VCCIO), U1.80 (VREF/IO80), U1.81 (VCCIO), U1.93 (VCCIO), U1.105 (VREF/IO105), U1.117 (VCCIO), U1.119 (VREF/IO119), U1.122 (VCCIO), U1.130 (VCCIO), U1.139 (VCCIO), U5.8 (VCC); also elsewhere on the board
VCCIO_CO: U8.4 (VDD); also elsewhere on the board
VSYNC47#: RN41.5, VS#.1
VSYNC#: U1.100 (IO100), U4.3 (A)
YPBPR#: J2.3, U1.39 (IO39)

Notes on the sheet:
IO22 = GND -> Backward compatibility to CycloneIV
Supported Devices: - EP4CE6E22 - EP4CE10E22 - 10CL006YE144 - 10CL010YE144

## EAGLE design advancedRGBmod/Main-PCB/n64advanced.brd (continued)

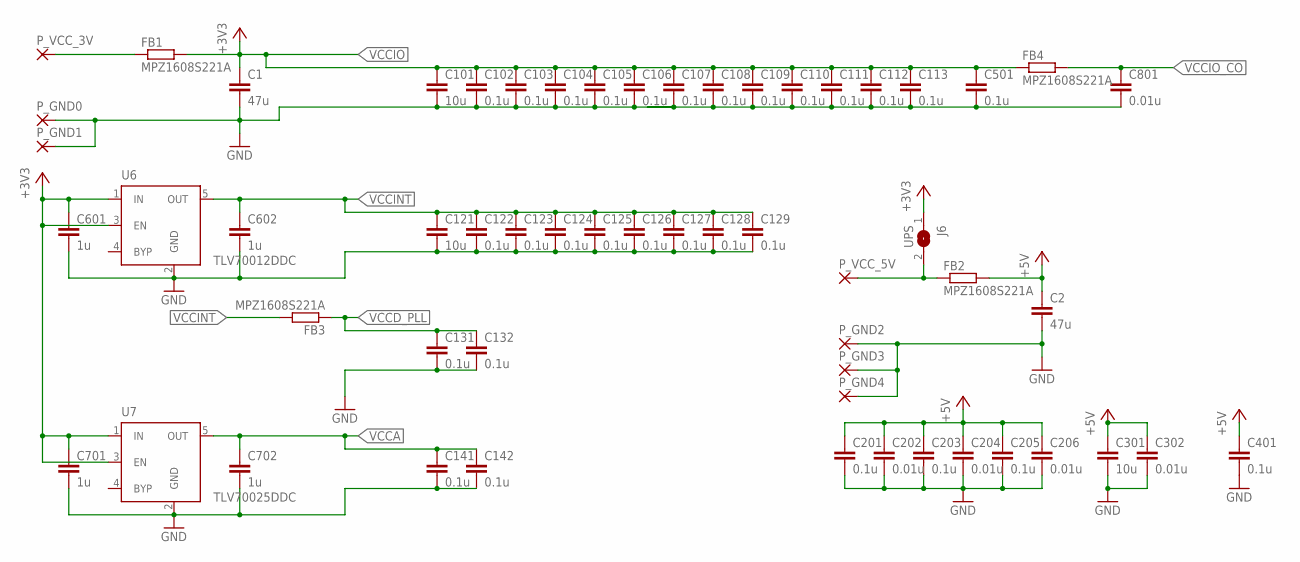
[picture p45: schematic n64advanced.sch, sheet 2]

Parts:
C1, C2: 47u; C0805
C101, C121, C301: 10u; C0805
C102, C103, C104, C105, C106, C107, C108, C109, C110, C111, C112, C113, C122, C123, C124, C125, C126, C127, C128, C129, C131, C132, C141, C142, C201, C203, C205, C401, C501: 0.1u; C0603
C202, C204, C206, C302, C801: 0.01u; C0603
C601, C602, C701, C702: 1u; C0603
FB1, FB2, FB3, FB4: MPZ1608S221A; R0603
J6: UPS; SJ
P_GND0, P_GND1, P_GND2, P_GND3, P_GND4: SMD2; SMD1,27-2,54
P_VCC_3V, P_VCC_5V: SMD2; SMD1,27-2,54
U6: TLV70012DDC; SOT23-5
U7: TLV70025DDC; SOT23-5

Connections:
+5V: C2.1, C201.1, C202.1, C203.1, C204.1, C205.1, C206.1, C301.1, C302.1, C401.1, FB2.2; also elsewhere on the board
GND: C1.2, C2.2, C101.2, C102.2, C103.2, C104.2, C105.2, C106.2, C107.2, C108.2, C109.2, C110.2, C111.2, C112.2, C113.2, C121.2, C122.2, C123.2, C124.2, C125.2, C126.2, C127.2, C128.2, C129.2, C131.2, C132.2, C141.2, C142.2, C201.2, C202.2, C203.2, C204.2, C205.2, C206.2, C301.2, C302.2, C401.2, C501.2, C601.2, C602.2, C701.2, C702.2, C801.2, P_GND0.1, P_GND1.1, P_GND2.1, P_GND3.1, P_GND4.1, U6.2 (GND), U7.2 (GND); also elsewhere on the board
unnamed: FB2.1, J6.2, P_VCC_5V.1
unnamed: FB1.1, P_VCC_3V.1
VCCA: C141.1, C142.1, C702.1, U7.5 (OUT); also elsewhere on the board
VCCD_PLL: C131.1, C132.1, FB3.1; also elsewhere on the board
VCCINT: C121.1, C122.1, C123.1, C124.1, C125.1, C126.1, C127.1, C128.1, C129.1, C602.1, FB3.2, U6.5 (OUT); also elsewhere on the board
VCCIO: C1.1, C101.1, C102.1, C103.1, C104.1, C105.1, C106.1, C107.1, C108.1, C109.1, C110.1, C111.1, C112.1, C113.1, C501.1, C601.1, C701.1, FB1.2, FB4.1, J6.1, U6.1 (IN), U6.3 (EN), U7.1 (IN), U7.3 (EN); also elsewhere on the board
VCCIO_CO: C801.1, FB4.2; also elsewhere on the board

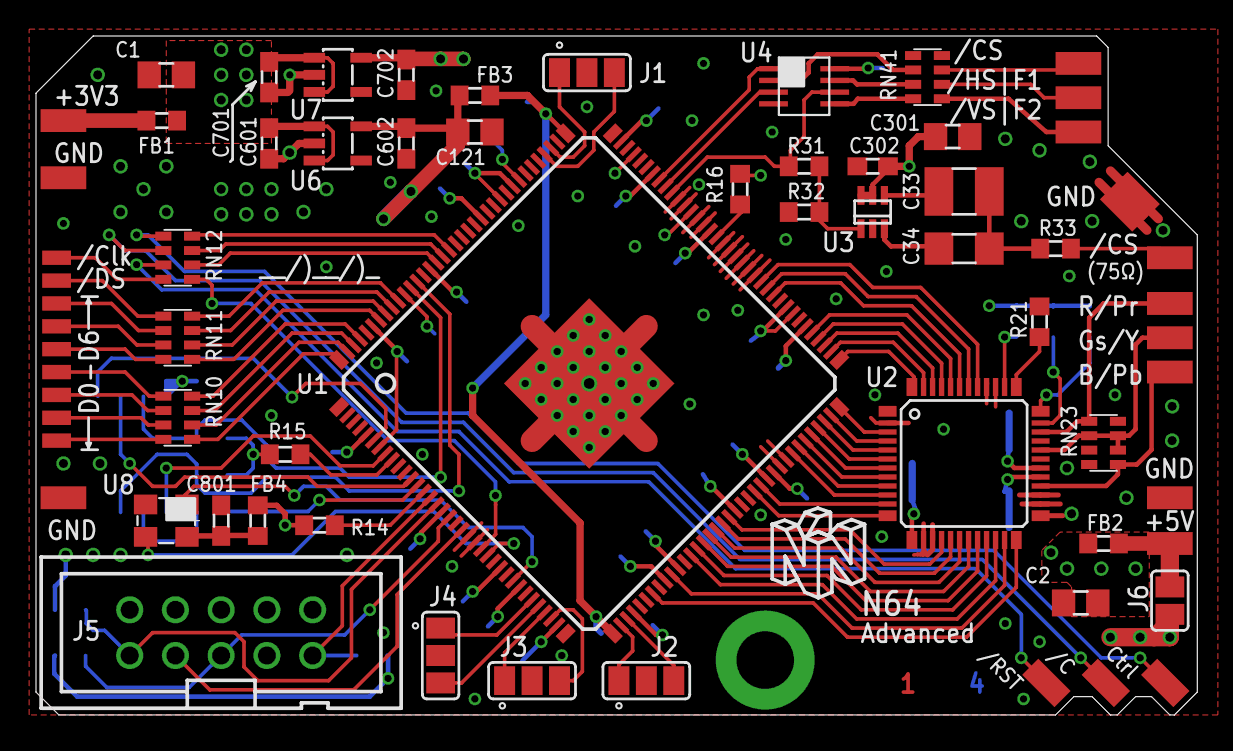
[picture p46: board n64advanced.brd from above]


Board: 4 copper layers, 64.5 x 37.7 mm, 112 parts (45 on the bottom side), 105 nets.

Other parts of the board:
U$1: ESD_10.00
U$2: MUELLTONNE_10.00

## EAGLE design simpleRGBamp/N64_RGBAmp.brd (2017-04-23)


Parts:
B: SMD2; SMD1,27-2,54
C1: 0.1u; C0603K
C2: 22u; SMC_B
C11, C21, C31: 82n; C0603K
C14, C24, C34, C44: 47p; C0603K
C43: 330u; SMC_D
CS: SMD2; SMD1,27-2,54
G: SMD2; SMD1,27-2,54
J1, J2: SJ
J3: SNES_MULTIAV_RGBC_ONLY
R: SMD2; SMD1,27-2,54
R1, R41: 4k7; R0603
R12, R22, R32: 5M1; R0603
R13, R23, R33, R43: R-EU_R0603; R0603
R42: 475; R0603
U1: THS7374

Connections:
GND: C1.2, C2.-, C14.2, C24.2, C34.2, C44.2, J3.P$5 (GND), J3.P$6 (GND), R1.2, R42.2, U1.5 (GND), U1.6 (/CE)
unnamed: C21.2, R22.1, U1.3 (CI3)
unnamed: R41.1, R42.1, U1.1 (CI1)
unnamed: J1.2, R1.1, U1.9 (BYP)
unnamed: C11.2, R12.1, U1.2 (CI2)
unnamed: C14.1, J3.P$1 (RED), R13.1
unnamed: C24.1, J3.P$2 (GREEN), R23.1
unnamed: R13.2, U1.13 (CO2)
unnamed: R23.2, U1.12 (CO3)
unnamed: C34.1, J3.P$4 (BLUE), R33.1
unnamed: C43.+, J2.1, U1.14 (CO1)
unnamed: R33.2, U1.11 (CO4)
unnamed: C11.1, R.1
unnamed: C21.1, G.1
unnamed: B.1, C31.1
unnamed: CS.1, R41.2
unnamed: C43.-, J2.2, R43.2
unnamed: C44.1, J3.P$3 (/CS), R43.1
R9: C31.2, R32.1, U1.4 (CI4)
VCC: C1.1, C2.+, J1.1, J3.P$10 (VCC), R12.2, R22.2, R32.2, U1.10 (VCC)


Board: 2 copper layers, 17.5 x 28.6 mm, 28 parts (0 on the bottom side), 20 nets.

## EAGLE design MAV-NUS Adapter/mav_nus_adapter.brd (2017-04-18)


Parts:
PAD1, PAD2: SMD2; SMD1,27-2,54
U$1, U$2, U$3, U$4, U$5, U$6, U$7, U$8, U$9, U$10, U$11, U$12, U$13: SMD0,45; SMD0,45-1,35
U$14, U$15, U$16, U$17, U$18, U$19, U$20, U$21, U$22: SMD1; SMD0,8-1,6

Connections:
unnamed: U$1.P$1, U$14.P$1
unnamed: U$2.P$1, U$15.P$1
unnamed: U$3.P$1, U$16.P$1
unnamed: U$4.P$1, U$17.P$1
unnamed: U$5.P$1, U$18.P$1
unnamed: U$6.P$1, U$19.P$1
unnamed: U$7.P$1, U$20.P$1
unnamed: U$8.P$1, U$21.P$1
unnamed: U$9.P$1, U$22.P$1
unnamed: PAD1.1, U$10.P$1, U$11.P$1
unnamed: PAD2.1, U$12.P$1, U$13.P$1


Board: 2 copper layers, 8.7 x 13.3 mm, 24 parts (0 on the bottom side), 11 nets.

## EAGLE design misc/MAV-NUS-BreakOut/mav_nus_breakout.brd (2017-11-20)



Board: 2 copper layers, 8.6 x 13.3 mm, 37 parts (13 on the bottom side), 11 nets.

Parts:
PAD13, PAD14: SMD1,27-2,54
U$211, U$212, U$213, U$214, U$215, U$222, U$226, U$227, U$228, U$229, U$230, U$231, U$232, U$233, U$234, U$235, U$236, U$237, U$238, U$239, U$240, U$241, U$242, U$243, U$244, U$245: SMD0,45; SMD0,5-1,4
U$216, U$217, U$218, U$219, U$220, U$221, U$223, U$224, U$225: SMD1; SMD0,8-1,6

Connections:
unnamed: U$211.P$1, U$216.P$1
unnamed: U$217.P$1, U$222.P$1
unnamed: U$218.P$1, U$226.P$1
unnamed: U$219.P$1, U$227.P$1
unnamed: U$220.P$1, U$228.P$1
unnamed: U$221.P$1, U$229.P$1
unnamed: U$223.P$1, U$230.P$1
unnamed: U$224.P$1, U$231.P$1
unnamed: U$225.P$1, U$232.P$1
unnamed: PAD13.1, U$212.P$1, U$213.P$1
unnamed: PAD14.1, U$214.P$1, U$215.P$1

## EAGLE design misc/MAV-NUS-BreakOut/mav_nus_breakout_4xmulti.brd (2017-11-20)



Board: 2 copper layers, 20.3 x 27.9 mm, 148 parts (74 on the bottom side), 44 nets.

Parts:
PAD3, PAD4, PAD5, PAD6, PAD11, PAD12, PAD13, PAD14: SMD1,27-2,54
U$36, U$37, U$38, U$39, U$40, U$47, U$51, U$52, U$53, U$54, U$55, U$56, U$57, U$58, U$59, U$60, U$61, U$62, U$63, U$64, U$65, U$66, U$67, U$68, U$69, U$70, U$71, U$72, U$73, U$74, U$75, U$82, U$86, U$87, U$88, U$89, U$90, U$91, U$92, U$93, U$94, U$95, U$96, U$97, U$98, U$99, U$100, U$101, U$102, U$103, U$104, U$105, U$176, U$177, U$178, U$180, U$187, U$191, U$192, U$193, U$194, U$195, U$196, U$197, U$198, U$199, U$200, U$201, U$202, U$203, U$204, U$205, U$206, U$207, U$208, U$210, U$211, U$212, U$213, U$214, U$215, U$222, U$226, U$227, U$228, U$229, U$230, U$231, U$232, U$233, U$234, U$235, U$236, U$237, U$238, U$239, U$240, U$241, U$242, U$243, U$244, U$245: SMD0,45; SMD0,5-1,4
U$41, U$42, U$43, U$44, U$45, U$46, U$48, U$49, U$50, U$76, U$77, U$78, U$79, U$80, U$81, U$83, U$84, U$85, U$181, U$182, U$183, U$184, U$185, U$186, U$188, U$189, U$190, U$216, U$217, U$218, U$219, U$220, U$221, U$223, U$224, U$225: SMD1; SMD0,8-1,6
U$179, U$209: SMD0,45; SMD0,45-1,35

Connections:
unnamed: U$36.P$1, U$41.P$1
unnamed: U$42.P$1, U$47.P$1
unnamed: U$43.P$1, U$51.P$1
unnamed: U$44.P$1, U$52.P$1
unnamed: U$45.P$1, U$53.P$1
unnamed: U$46.P$1, U$54.P$1
unnamed: U$48.P$1, U$55.P$1
unnamed: U$49.P$1, U$56.P$1
unnamed: U$50.P$1, U$57.P$1
unnamed: PAD3.1, U$37.P$1, U$38.P$1
unnamed: PAD4.1, U$39.P$1, U$40.P$1
unnamed: U$71.P$1, U$76.P$1
unnamed: U$77.P$1, U$82.P$1
unnamed: U$78.P$1, U$86.P$1
unnamed: U$79.P$1, U$87.P$1
unnamed: U$80.P$1, U$88.P$1
unnamed: U$81.P$1, U$89.P$1
unnamed: U$83.P$1, U$90.P$1
unnamed: U$84.P$1, U$91.P$1
unnamed: U$85.P$1, U$92.P$1
unnamed: PAD5.1, U$72.P$1, U$73.P$1
unnamed: PAD6.1, U$74.P$1, U$75.P$1
unnamed: U$176.P$1, U$181.P$1
unnamed: U$182.P$1, U$187.P$1
unnamed: U$183.P$1, U$191.P$1
unnamed: U$184.P$1, U$192.P$1
unnamed: U$185.P$1, U$193.P$1
unnamed: U$186.P$1, U$194.P$1
unnamed: U$188.P$1, U$195.P$1
unnamed: U$189.P$1, U$196.P$1
unnamed: U$190.P$1, U$197.P$1
unnamed: PAD11.1, U$177.P$1, U$178.P$1
unnamed: PAD12.1, U$179.P$1, U$180.P$1
unnamed: U$211.P$1, U$216.P$1
unnamed: U$217.P$1, U$222.P$1
unnamed: U$218.P$1, U$226.P$1
unnamed: U$219.P$1, U$227.P$1
unnamed: U$220.P$1, U$228.P$1
unnamed: U$221.P$1, U$229.P$1
unnamed: U$223.P$1, U$230.P$1
unnamed: U$224.P$1, U$231.P$1
unnamed: U$225.P$1, U$232.P$1
unnamed: PAD13.1, U$212.P$1, U$213.P$1
unnamed: PAD14.1, U$214.P$1, U$215.P$1

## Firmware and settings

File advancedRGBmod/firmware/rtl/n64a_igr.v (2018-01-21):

//////////////////////////////////////////////////////////////////////////////////
//
// This file is part of the N64 RGB/YPbPr DAC project.
//
// Copyright (C) 2016-2018 by Peter Bartmann <borti4938@gmx.de>
//
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
//////////////////////////////////////////////////////////////////////////////////
//
// Company:  Circuit-Board.de
// Engineer: borti4938
//
// Module Name:    n64a_igr
// Project Name:   N64 Advanced RGB/YPbPr DAC Mod
// Target Devices: universial (PLL and 50MHz clock required)
// Tool versions:  Altera Quartus Prime
// Description:
//
// Dependencies: vh/igr_params.vh
//               ip/altpll_1.qip
//
// Revision: 3.0
// Features: console reset
//           override heuristic for deblur (resets on each reset and power cycle)
//           activate / deactivate de-blur in 240p (a change overrides heuristic for de-blur)
//           activate / deactivate 15bit mode (no selectable default since 2.6)
//           selectable defaults
//           defaults set on each power cycle and on each reset
//
//////////////////////////////////////////////////////////////////////////////////


module n64a_igr (
  SYS_CLK,
  nRST,

  CTRL,

  Default_DeBlur,
  Default_nForceDeBlur,

  nDeBlur,
  nForceDeBlur,
  n15bit_mode
);

`include "vh/igr_params.vh"


input SYS_CLK;
inout nRST;

input CTRL;

input Default_nForceDeBlur;
input Default_DeBlur;

output reg nDeBlur      = 1'b1;
output reg nForceDeBlur = 1'b1;
output reg n15bit_mode  = 1'b1;


wire CLK_4M, CLK_16k;

altpll_1 sys_pll(
  .inclk0(SYS_CLK),
  .c0(CLK_4M),
  .c1(CLK_16k)
);


reg [1:0] read_state  = 2'b0; // state machine

parameter ST_WAIT4N64 = 2'b00; // wait for N64 sending request to controller
parameter ST_N64_RD   = 2'b01; // N64 request sniffing
parameter ST_CTRL_RD  = 2'b10; // controller response

reg [3:0] sampling_point_n64  = 4'h8; // wait_cnt increased a few times since neg. edge -> sample data
reg [3:0] sampling_point_ctrl = 4'h8; // (9 by default -> delay somewhere around 2.25us)

reg        prev_ctrl    =  1'b1;
reg [11:0] wait_cnt     = 12'b0; // counter for wait state (needs appr. 1.0ms at CLK_4M clock to fill up from 0 to 4095)

reg [15:0] data_stream      = 16'b0;
reg  [3:0] data_cnt         =  4'h0;

reg initiate_nrst = 1'b0;

reg nfirstboot = 1'b0;


// controller data bits:
//  0: 7 - A, B, Z, St, Du, Dd, Dl, Dr
//  8:15 - 'Joystick reset', (0), L, R, Cu, Cd, Cl, Cr
// 16:23 - X axis
// 24:31 - Y axis
// 32    - Stop bit
// (bits[0:15] used here)

always @(posedge CLK_4M) begin
  case (read_state)
    ST_WAIT4N64:
      if (&wait_cnt) begin // waiting duration ends (exit wait state only if CTRL was high for a certain duration)
        read_state    <= ST_N64_RD;
        data_stream   <= 16'h0000;
        data_cnt      <=  4'h0;
        initiate_nrst <=  1'b0;
      end
    ST_N64_RD: begin
      if (wait_cnt[7:0] == {4'h0,sampling_point_n64}) begin // sample data
        if (data_cnt[3]) // eight bits read
          if (data_stream[13:6] == 8'b00000001 & CTRL) begin // check command and stop bit
          // trick: the 2 LSB command bits lies where controller produces unused constant values
          //         -> (hopefully) no exchange with controller response
            read_state  <= ST_CTRL_RD;
            data_stream <= 16'h0000;
            data_cnt    <=  4'h0;
          end else
            read_state  <= ST_WAIT4N64;
        else begin
          data_stream[13:7] <= data_stream[12:6];
          data_stream[6]    <= CTRL;
          data_cnt          <= data_cnt + 1'b1;
        end
      end
      if (&{prev_ctrl,~CTRL,|data_cnt})
        sampling_point_n64 <= wait_cnt[4:1];
    end
    ST_CTRL_RD: begin
      if (wait_cnt[7:0] == {4'h0,sampling_point_ctrl}) begin // sample data
        if (&data_cnt) begin // sixteen bits read (analog values of stick not point of interest)
          if ({data_stream[14:0], CTRL} == igr_deblur_off) begin // defined button combination pressed
            nForceDeBlur <= 1'b0;
            nDeBlur      <= 1'b1;
          end
          if ({data_stream[14:0], CTRL} == igr_deblur_on) begin // defined button combination pressed
            nForceDeBlur <= 1'b0;
            nDeBlur      <= 1'b0;
          end
          if ({data_stream[14:0], CTRL} == igr_15bitmode_off) begin // defined button combination pressed
            n15bit_mode  <= 1'b1;
          end
          if ({data_stream[14:0], CTRL} == igr_15bitmode_on) begin // defined button combination pressed
            n15bit_mode  <= 1'b0;
          end
          if ({data_stream[14:0], CTRL} == igr_reset) // defined button combination pressed
            initiate_nrst <= 1'b1;
          read_state  <= ST_WAIT4N64;
        end else begin
          data_stream[15:1] <= data_stream[14:0];
          data_stream[0]    <= CTRL;
          data_cnt          <= data_cnt + 1'b1;
        end
      end
      if (&{prev_ctrl,~CTRL,|data_cnt})
        sampling_point_ctrl <= wait_cnt[4:1];
    end
    default: read_state <= ST_WAIT4N64;
  endcase


  if (prev_ctrl & ~CTRL) // counter resets on neg. edge
    wait_cnt <= 12'h000;
  else if (~&wait_cnt) // saturate counter if needed
    wait_cnt <= wait_cnt + 1'b1;

  prev_ctrl <= CTRL;

  if (nRST == 1'b0) begin
    nForceDeBlur <= Default_nForceDeBlur;

    read_state    <= ST_WAIT4N64;
    wait_cnt      <= 12'h000;
    prev_ctrl     <=  1'b1;
    initiate_nrst <=  1'b0;
  end

  if (~nfirstboot) begin
    nfirstboot   <=  1'b1;
    nDeBlur      <= ~Default_DeBlur;
    nForceDeBlur <=  Default_nForceDeBlur;
  end
end

reg        drv_rst =  1'b0;
reg [9:0] rst_cnt = 10'b0; // ~64ms are needed to count from max downto 0 with CLK_16k.

always @(posedge CLK_16k) begin
  if (initiate_nrst == 1'b1) begin
    drv_rst <= 1'b1;      // reset system
    rst_cnt <= 10'h3ff;
  end else if (|rst_cnt) // decrement as long as rst_cnt is not zero
    rst_cnt <= rst_cnt - 1'b1;
  else
    drv_rst <= 1'b0; // end of reset
end

assign nRST = drv_rst ? 1'b0 : 1'bz;

endmodule

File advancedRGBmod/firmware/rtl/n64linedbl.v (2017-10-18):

//////////////////////////////////////////////////////////////////////////////////
// Company:  Circuit-Board.de
// Engineer: borti4938
//
// Module Name:    n64linedbl
// Project Name:   Advanced RGB Mod
// Target Devices: Max10, Cyclone IV and Cyclone 10 LP devices
// Tool versions:  Altera Quartus Prime
// Description:    simple line-multiplying
//
// Dependencies: ip/ram2port_0.qip
//
// Revision: 1.1
// Features: linebuffer for - NTSC 240p -> 480p rate conversion
//                          - PAL  288p -> 576p rate conversion
//           injection of scanlines on demand in three selectable intensities
//
///////////////////////////////////////////////////////////////////////////////////////////


module n64linedbl(
  nCLK_4x,

  vinfo,

  Sync_i,
     R_i,
     G_i,
     B_i,


  Sync_o,
     R_o,
     G_o,
     B_o
);

parameter color_width_i = 7;
parameter color_width_o = 8;

localparam ram_depth = 11; // plus 1 due to oversampling

input nCLK_4x;

input [4:0] vinfo; // [nLinedbl,SL_str (2bits),PAL,interlaced]

input               [3:0] Sync_i;
input [color_width_i-1:0]    R_i;
input [color_width_i-1:0]    G_i;
input [color_width_i-1:0]    B_i;

output reg               [3:0] Sync_o;
output reg [color_width_o-1:0]    R_o;
output reg [color_width_o-1:0]    G_o;
output reg [color_width_o-1:0]    B_o;

reg div_2x = 1'b0;

always @(negedge nCLK_4x) begin
  div_2x <= ~div_2x;
end

reg                 wrline = 1'b0;
reg [ram_depth-1:0] wraddr = {ram_depth{1'b0}};

wire wren = ~&{wraddr[ram_depth-1],wraddr[ram_depth-2],wraddr[ram_depth-5]};

reg [ram_depth-1:0] line_width[0:1];
initial begin
   line_width[1] = {ram_depth{1'b0}};
   line_width[0] = {ram_depth{1'b0}};
end

wire valid_line = &wraddr[ram_depth-1:ram_depth-2]; // hopefully enough for evaluation

reg           [1:0] rdrun    = 2'b00;
reg                 rdcnt    = 1'b0;
reg                 rdline   = 1'b0;
reg [ram_depth-1:0] rdaddr   = {ram_depth{1'b0}};

wire nVSYNC_i     = Sync_i[3];
reg  nVSYNC_i_buf = 1'b0;
wire nHSYNC_i     = Sync_i[1];
reg  nHSYNC_i_buf = 1'b0;


reg [1:0] newFrame       = 2'b0;
reg [1:0] start_reading_proc = 2'b00;


always @(negedge nCLK_4x) begin
  if (~div_2x) begin
    if (nVSYNC_i_buf & ~nVSYNC_i) begin
      newFrame[0] <= ~newFrame[1];
      if (&{nHSYNC_i_buf,~nHSYNC_i,wren,valid_line})
        start_reading_proc[0] <= ~start_reading_proc[1];  // trigger start reading
    end

    if (nHSYNC_i_buf & ~nHSYNC_i) begin // negedge nHSYNC -> reset wraddr and toggle wrline
      line_width[wrline] <= wraddr[ram_depth-1:0];

      wraddr <= {ram_depth{1'b0}};
      wrline <= ~wrline;
    end else if (wren) begin
      wraddr <= wraddr + 1'b1;
    end

    nVSYNC_i_buf <= nVSYNC_i;
    nHSYNC_i_buf <= nHSYNC_i;
  end
end

//wire pal_mode = vinfo[1];
//wire [ram_depth-1:0] line_width = pal_mode ? 11'd1588 : 11'd1546;

always @(negedge nCLK_4x) begin
  if (rdrun[1]) begin
    if (rdaddr == line_width[rdline]) begin
      rdaddr   <= {ram_depth{1'b0}};
      if (rdcnt)
//        rdline <= ~rdline;
        rdline <= ~wrline;
      rdcnt <= ~rdcnt;
    end else begin
      rdaddr <= rdaddr + 1'b1;
    end
    if (~wren || &{nHSYNC_i_buf,~nHSYNC_i,~valid_line}) begin
      rdrun <= 2'b00;
    end
  end else if (rdrun[0] && wraddr[3]) begin
    rdrun[1] <= 1'b1;
    rdcnt    <= 1'b0;
    rdline   <= ~wrline;
    rdaddr   <= {ram_depth{1'b0}};
  end else if (^start_reading_proc) begin
    rdrun[0] <= 1'b1;
  end

  start_reading_proc[1] <= start_reading_proc[0];
end

wire               [3:0] Sync_buf;
wire [color_width_i-1:0]    R_buf, G_buf, B_buf;

ram2port_0 videobuffer(
  .clock(~nCLK_4x),
  .data({R_i,G_i,B_i}),
  .rdaddress({rdline,rdaddr}),
  .wraddress({wrline,wraddr}),
  .wren(&{wren,~div_2x}),
  .q({R_buf,G_buf,B_buf})
);


wire       nHSYNC_WIDTH = rdaddr[7];    // HSYNC width (effectively 64 pixel)
wire [1:0] nVSYNC_WIDTH = 2'd3;         // three lines for VSYNC
wire   CSYNC_post_VSYNC = &rdaddr[7:6];


reg        rdcnt_buf = 1'b0;
reg [1:0] nVSYNC_cnt = 2'b0;


wire [1:0] SL_str = vinfo[3:2];
wire nENABLE_linedbl = vinfo[4] | ~rdrun[1];

always @(negedge nCLK_4x) begin

  if (rdcnt_buf ^ rdcnt) begin
    Sync_o[0] <= 1'b0;
    Sync_o[1] <= 1'b0;
    Sync_o[2] <= 1'b1; // dummy

    if (|nVSYNC_cnt) begin
      nVSYNC_cnt <= nVSYNC_cnt - 1'b1;
      Sync_o[0]  <= 1'b1;
    end

    if (^newFrame) begin
      nVSYNC_cnt  <= nVSYNC_WIDTH;
      Sync_o[3]   <= 1'b0;
      newFrame[1] <= newFrame[0];
    end
  end else begin
    if (nHSYNC_WIDTH) begin
      Sync_o[0] <= 1'b1;
      Sync_o[1] <= 1'b1;
      if (~Sync_o[3])
        Sync_o[0] <= 1'b0;
    end

    if ((~|nVSYNC_cnt) && (CSYNC_post_VSYNC)) begin
      Sync_o[0] <= 1'b1;
      Sync_o[3] <= 1'b1;
    end
  end

    rdcnt_buf <= rdcnt;

    if (rdcnt) begin
      case (SL_str)
        2'b11: begin
          R_o <= {R_buf,1'b0};
          G_o <= {G_buf,1'b0};
          B_o <= {B_buf,1'b0};
        end
        2'b10: begin
          R_o <= {1'b0,R_buf[color_width_i-1:0]} + {2'b00,R_buf[color_width_i-1:1]};
          G_o <= {1'b0,G_buf[color_width_i-1:0]} + {2'b00,G_buf[color_width_i-1:1]};
          B_o <= {1'b0,B_buf[color_width_i-1:0]} + {2'b00,B_buf[color_width_i-1:1]};
        end
        2'b01: begin
          R_o <= {1'b0,R_buf[color_width_i-1:0]};
          G_o <= {1'b0,G_buf[color_width_i-1:0]};
          B_o <= {1'b0,B_buf[color_width_i-1:0]};
        end
        2'b00: begin
          R_o <= {color_width_o{1'b0}};
          G_o <= {color_width_o{1'b0}};
          B_o <= {color_width_o{1'b0}};
        end
      endcase
    end else begin
      R_o <= {R_buf,1'b0};
      G_o <= {G_buf,1'b0};
      B_o <= {B_buf,1'b0};
    end

  if (nENABLE_linedbl) begin
    Sync_o <= Sync_i;
       R_o <= {R_i,1'b0};
       G_o <= {G_i,1'b0};
       B_o <= {B_i,1'b0};
  end
end


endmodule 

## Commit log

2016-08-17 toggle de-blur on/off and 15bit mode on/off using the controller - de-blur : default on, D-Pad right + L + R + C-right to toggle - 15bit mode: default off, D-Pad left + L + R + C-left to toggle - def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
2016-08-17 Console reset using A + B + D-pad dw + D-pad ri + L + R
    [n64igr.v]
2016-08-26 set defaults on reset (de-blur & 15bit mode)
    [n64igr.v]
2017-02-01 remove one-pixel shift in de-blur mode
2017-02-01 De-blur switched off by default -> can enabled by setting pad A (pin 100) to GND
2017-02-01 version with IGR: defaults are not set with a reset anymore as it is not needed any more with the new button combination introduced a few days before.
    [n64igr.v]
2017-04-18 Move files for viletims PCB solution to a new subfolder
2017-04-18 MAV-NUS adapter (0.8mm to 1.27mm break out) for the general RGB DAC mod
    [mav_nus_adapter.brd, mav_nus_adapter.sch]
2017-04-19 Update for viletims commercial PCB version: implemented heuristic for de-blur
2017-04-23 initial commit DIY projects
    [N64_RGBAmp.brd, N64_RGBAmp.sch, mav_nus_breakout.brd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]
2017-05-18 Add debug mode: - works only for CPLDs 570LEs - large picture shift on de-blur on and off - parameterise heuristic algorithm (implementation for release is slightly optimized)
2017-06-08 PCB Update: - rotate JTAG header by 180deg - pull-ups and -downs for TCK, TMS and TDI as recommended by Altera / Intel - thicker wire for Vcc near pad
    [n64rgb.brd, n64rgb.sch]
2017-06-21 unique firmware for my prototype and GitHub version (No feature changes, no bugfixes, etc.)
2017-06-28 Remove pixel shift between de-blur on and off update to Quartus Prime Version 17.0.1
2017-07-10 Initial commit: parameterize IGR button combination for easy editing
2017-07-11 IGR button combinations: - readme for building own fw - alternative fw-builds - update readme’s - Amend (11.07.2017): new folder structure and headlines fixed
2017-08-09 insert default stage (was in by synthesis anyway)
2017-09-01 Selectable installation type: either IGR or Switches
    [n64rgb.brd, n64rgb.sch]
2017-09-28 some typos and rearrangements
    [mav_nus_breakout.brd, mav_nus_breakout.sch]
2017-09-28 N64 Advanced: initial commit
    [BOM_n64advanced.xlsx, N64A_FA.brd, N64A_FA.sch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]
2017-09-30 new "default" IGR button combinations in "default" fw. builds of (folder output_files) (equal to set 1)
2017-10-11 BOM Update with recommended FPGA version
    [BOM_n64advanced.xlsx]
2017-10-12 PCB Update: - unused VREF to VCCIO (see connection guideline) - unused DEV_CLRn and DEV_OE to GND (see connection guideline) - rename of some resistors
    [BOM_n64advanced.xlsx, SMT_Coordinates_N64A.csv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]
2017-10-12 important BOM update: Use Schmitt triggered buffer instead of simple one!!!
    [BOM_n64advanced.xlsx, n64advanced.brd, n64advanced.sch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]
2017-10-14 add U5 to SMT coordination file
    [SMT_Coordinates_N64A.csv]
2017-10-17 Update PCB - reroute power supply layer reducing noise injection to +5V plane from digital signals - adapt some component positions
    [BOM_n64advanced.xlsx, SMT_Coordinates_N64A.csv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]
2017-10-18 bugfix: pinout for UseVGA_HVSync now as described in README cosmetic changes in n64_linedbl.v
    [n64linedbl.v]
2017-10-20 important DRC error fix in PCB design! If you ordered version N64A_20171017 - like I did -, you can unfortunately throw them away :(. There was a design error in the board such that there is a short 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
    [n64advanced.brd, n64advanced_E7x.brd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]
2017-10-20 remove separate eagle 7.x version
    [n64advanced.brd, n64advanced.sch, n64advanced_E7x.brd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]
2017-10-20 MAV-NUS breakout in 4x panel (e.g. for OSHPark)
    [mav_nus_breakout_4xmulti.brd]
2017-10-23 remove pixel shift between deblured and non-deblured material
2017-11-04 add missing caps in BOM
    [BOM_n64advanced.xlsx]
2017-11-05 add TOP, BOT and THT pages in BOM
    [BOM_n64advanced.xlsx]
2017-11-08 update adapter PCB
    [mav_nus_breakout.brd, mav_nus_breakout.sch, mav_nus_breakout_4xmulti.brd]
2017-11-20 Silkscreen update at BOT side of PCB
    [n64advanced.brd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]
2017-11-24 gerber files for N64RGB
    [n64rgb.GBL, n64rgb.GBO, n64rgb.GBP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]
2017-11-24 Provide installation and setup guide for N64A and N64RGB. Update Readmes accordingly
    [BOM_n64rgb.xlsx]
2017-11-24 provide assembly sheets
2017-11-26 Add filter bypass option for FilterAddOn; e.g. for simple signal conversion for PAL SNES RGB cables
    [n64advanced.brd, n64advanced.sch]
2017-11-27 fallback mode: deactivate linedoubling and YPbPr conversion if reset is pressed on power cycle
2017-11-27 update resistor value
    [BOM_n64advanced.xlsx, n64advanced.brd, n64advanced.sch]
2017-11-28 bugfix (forget to change MPN of R21 on last change)
    [BOM_n64advanced.xlsx]
2017-11-30 change load resistor values at R2R output to have a more colourful picture
    [BOM_n64rgb.xlsx, n64rgb.brd, n64rgb.sch]
2017-11-30 update BOM
    [BOM_n64advanced.xlsx]
2017-12-04 Place R21 (R_set of the DAC) on TOP layer making it easy to replace if board is installed
    [BOM_n64advanced.xlsx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]
2017-12-07 bugfix: small typo thanks to philenotfound (circuit-board.de)
2017-12-11 Update PCB: add logo, new name, stencil reduce pad size by 10%
    [n64rgb.brd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]
2017-12-11 reduce pad size by 10% for stencil
    [n64advanced.brd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]
2017-12-18 new structure - preparation for firmware files of N64RGBv2
    [BOM_n64rgbv1.xlsx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]
2017-12-18 update PCB v1 (silcscreen/solder mask error/missmatch)
    [n64rgbv1.brd]
2017-12-18 initial commit PCB v2
    [BOM_n64rgbv2.xlsx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]
2017-12-19 move filter addon and mav-nus breakout to new misc/ folder
    [N64A_FA.brd, N64A_FA.sch, N64A_FA_E7x.brd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]
2017-12-21 use LSB of the ADV7125 (new design is compatible to initial public N64RGBv2 Version 20171211)
    [BOM_n64rgbv2.xlsx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]
2018-01-02 simplify (automatic) de-blur estimation algorithm incl. programming files (commit from dev_tests branch: 88fc0eb1f5248bb670de839c5d6ea502ab8799ad)
2018-01-21 N64RGBv1/v2 misc updates (thanks to iFixRetro for giving feedback here!!!): - bugfix BOM and silkscreen (N64RGBv2) - silkscreen update to distinguish between MaxII and MaxV setup avoiding assembly mi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
    [BOM_n64rgbv1.xlsx, BOM_n64rgbv2.xlsx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]
2018-01-22 update guide according to recent layout changes on PCB design (N64RGBv1, v2)

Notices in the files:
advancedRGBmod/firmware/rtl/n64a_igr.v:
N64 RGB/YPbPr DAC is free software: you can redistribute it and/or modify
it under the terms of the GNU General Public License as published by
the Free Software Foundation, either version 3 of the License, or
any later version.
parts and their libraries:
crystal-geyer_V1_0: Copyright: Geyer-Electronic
